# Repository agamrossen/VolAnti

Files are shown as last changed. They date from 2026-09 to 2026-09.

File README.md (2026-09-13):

<div align="center">

<picture>
  <source media="(prefers-color-scheme: dark)" srcset="docs/images/logo-dark.svg">
  VolAnti
</picture>

### Open-source acoustic drone detection. It hears the propellers, not the radio.

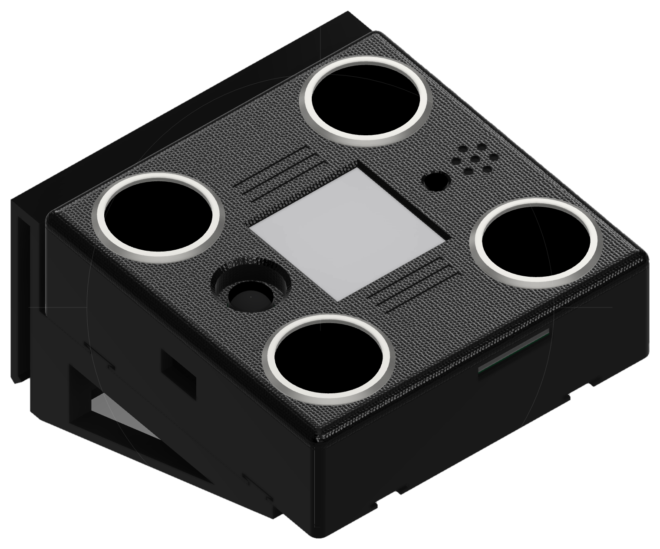
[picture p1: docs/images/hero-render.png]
VolAnti unit on its mount


<br>

**[Website](https://volantitech.com)** · **[Live simulator](https://volantitech.com/#simulator)** · **[Build it on a breadboard](docs/breadboard-build.md)** · **[Build the full unit](docs/pcb-build.md)** · **[Photos and videos](docs/gallery.md)**

Detection and alert only. No jamming, no interception, no countermeasures, ever.

</div>

---

A 91 mm box with four microphones, an ESP32-S3, an e-paper screen and a LoRa radio. It listens for the harmonic comb a multirotor makes and when it hears one it beeps, flashes red, buzzes, writes the time to a screen that survives a power cut, and tells every other unit on the network.

If you want the short illustrated version, or to watch the detector work on a sound field you control, that is what [the website](https://volantitech.com) and [the simulator](https://volantitech.com/#simulator) are for. This page is the long version, and everything needed to build one is in this repository.

<table>
<tr>
<td align="center" width="20%"><h3>104 m</h3>measured detection,<br>hovering airframe, light wind</td>
<td align="center" width="20%"><h3>0.23 s</h3>from first sound<br>to alarm</td>
<td align="center" width="20%"><h3>none</h3>false alarms in<br>field sessions so far</td>
<td align="center" width="20%"><h3>18 to 22 h</h3>on one<br>battery charge</td>
<td align="center" width="20%"><h3>£50 to £80</h3>parts for a<br>full unit</td>
</tr>
</table>

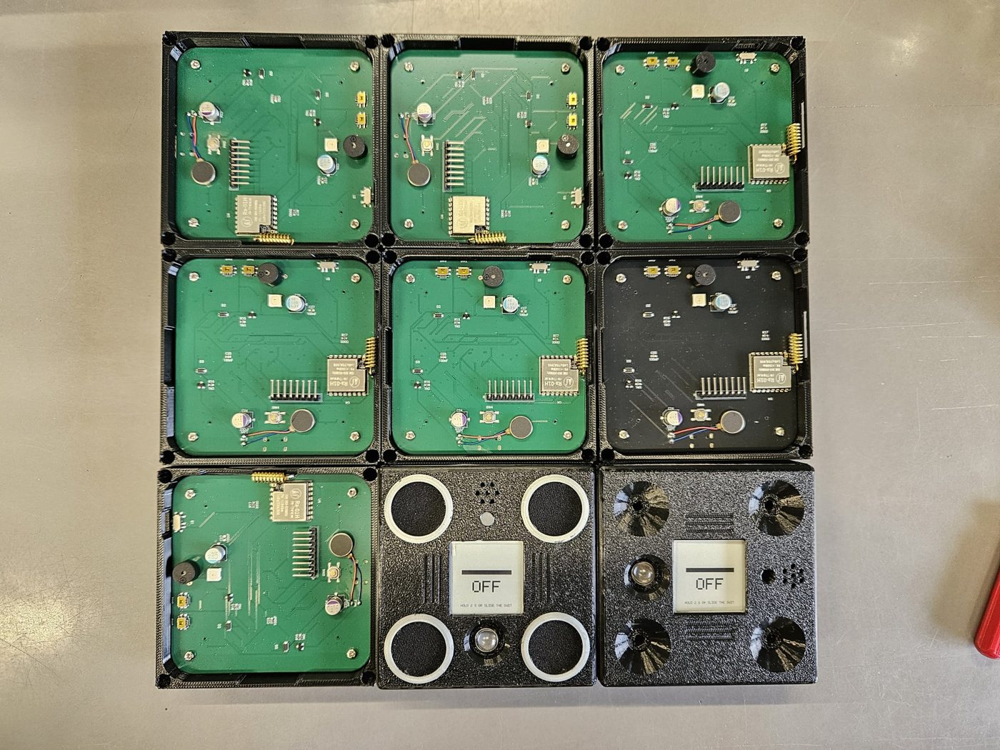
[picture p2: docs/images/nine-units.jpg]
Nine units on the bench, seven open, two closed


## Contents

**Understand it**: [The problem](#the-problem) · [What the device does](#what-the-device-does) · [How it works](#how-it-works) · [Radio](#radio) · [Power](#power) · [Range and testing](#range-and-testing)

**Build it**: [Two ways to build it](#two-ways-to-build-it) · [Breadboard guide](docs/breadboard-build.md) · [Full unit guide](docs/pcb-build.md) · [Flashing](docs/flashing.md) · [Running several units](#running-several-units)

**Everything else**: [Photos and videos](docs/gallery.md) · [Test results](docs/test-results.md) · [Deploying](docs/deploying.md) · [Contributing](#contributing) · [Scope](#scope) · [Licence](#licence) · [A note from Agam](#a-note-from-agam)

**Files**: [firmware](firmware/) · [reference detector](src/) · [PCB, BOM and placement](hardware/pcb/) · [printable enclosure](hardware/enclosure/) · [test audio](test/) · [website source](index.html)

---

## The problem

Nearly all drone detection listens for radio. It finds the control link between the pilot and the aircraft, decodes it, and reports where both are. It works well, and it has one hard failure: the drone has to transmit.

A fibre-optic FPV drone does not. It trails a thread of glass back to its operator, video comes down the fibre, control goes up it, and the radio spectrum stays silent. There is nothing to find and nothing to decode.

What it cannot hide is four motors spinning propellers. A 7 in three-blade propeller on a 2807-class motor puts a precisely structured comb of harmonics into the air, spaced by the blade-passage rate, and that spacing is set by physics the airframe cannot switch off. VolAnti listens for that structure.

It is not radar and not a replacement for one. It is a cheap local tripwire for the last few hundred metres that keeps working when the radio picture is empty, and that a school or a farm can build and repair themselves.

## What the device does

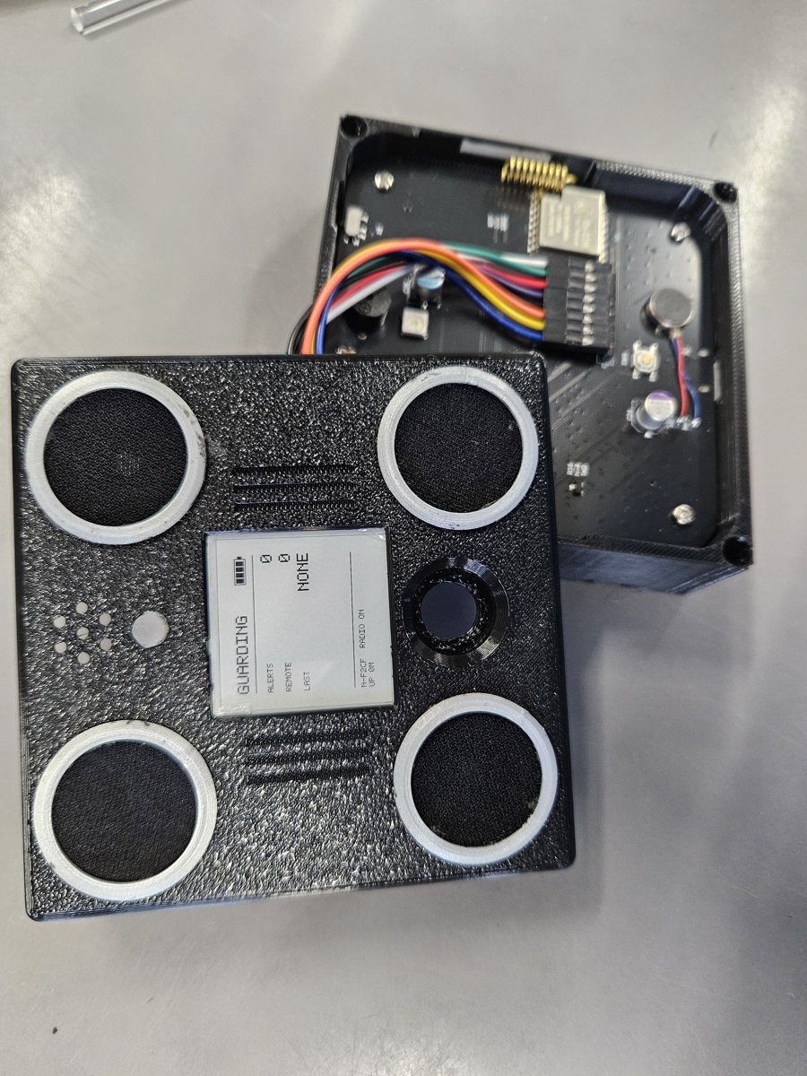
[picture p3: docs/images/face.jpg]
The face of the unit: four grilles, a screen, a light and a button


It runs continuously and does one job. Every 32 ms it takes a new slice of sound from the four microphones, folds them together, measures how comb-like the spectrum is, and asks four independent detectors whether that is a rotor.

When one of them says yes, five things happen at once.

| Channel | What happens |
|---|---|
| Beeper | Loud and patterned. The one that carries through a wall. |
| LED | Fast flashing red through the light pipe in the lid. |
| Motor | A haptic pulse for whoever is holding it. |
| E-paper | The alert and the time, and it stays on the screen with no power. |
| LoRa | An 18 byte packet to every other unit in range. |

Between alerts the light blinks slow green, so a quiet unit and a dead unit never look the same. A press on the snooze button silences the outputs for ten seconds while detection carries on underneath.

<br clear="right">

## How it works

A propeller with B blades turning at R revolutions per second chops the air B×R times a second. That is the fundamental. Because the chopping is not a smooth sine, energy also lands at 2×, 3×, 4× and so on, and the result is a harmonic comb: peaks at even spacing with quiet gaps between.

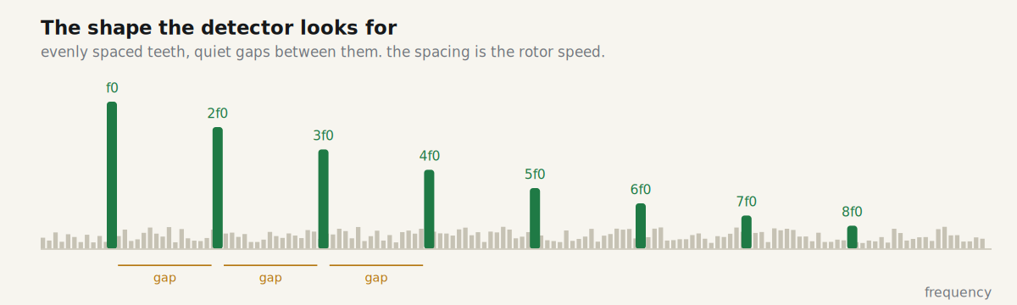
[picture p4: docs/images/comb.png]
Measured spectrum of a loaded propeller, showing the comb


Wind, traffic and rain smear across the whole spectrum. Evenly spaced teeth do not, and their spacing is the rotor speed. So the detector measures a rate and checks that it holds still.

**Four microphones to one number.** Four ICS-43434 MEMS microphones sit in a plus, 79 mm corner to corner, clocked from one source. Their four streams are added. At these frequencies 79 mm is a tenth of a wavelength, so sound from any direction adds in phase and each capsule's own noise does not. That is about 6 dB of signal to noise for free and it is nearly omnidirectional. Beamforming was tried at this size and buys nothing, so the array is a sensitivity device, not a direction finder.

**Spectrum.** A 2048 point FFT every 512 samples at 16 kHz, one frame every 32 ms.

**Adaptive floor.** The detector keeps a running picture of what the site normally sounds like at every frequency and subtracts it. Quiet things are learned in about 6 s, loud broadband bursts in under a second, which is what stops a passing lorry parking itself in the noise model.

**Comb score.** For every candidate rate from 70 to 2000 Hz, add the energy on that comb's teeth, subtract the energy in its gaps, normalise, keep the best.

**Track and hold.** One high scoring frame means nothing. The same rate has to win six frames in a row within 2 %. Noise does not do that. A rotor does.

**Four detectors on one spectrum.** A single detector would have to be tuned for either a drone that arrives or a drone that hovers, so there are four, and the alert is whichever is sure first.

| | Tier | Catches | How | Latency |
|---|---|---|---|---|
| 1 | Fast comb | An aircraft that arrives, approaches or changes | Comb score against the fast floor | 0.23 s |
| 2 | Slow comb | An aircraft that arrives and then hovers | Same score against a 30 s floor | 1.4 to 4 s |
| 3 | Envelope wash | Loaded, close, high thrust flight | Broadband modulation above 3 kHz | 1 to 3 s |
| 4 | No-floor comb | A long hover somewhere that never goes quiet | 2 s Welch spectrum, whitened, no floor | 5 to 15 s |

Tier 1 is sealed: golden test vectors pin its behaviour, and the same audio gives the same score to the last decimal place on a laptop and on the board. Tier 4 is the one that fired at 104 m.

More detail, including the numbers behind each stage, is in [docs/how-it-works.md](docs/how-it-works.md). All of it runs live in [the simulator](https://volantitech.com/#simulator).

## Radio

Each unit carries an Ra-01H LoRa module and a spring antenna lying in the wall of the case. The alert packet is 18 bytes: identity, tier, rate, score, sequence. There is no relay and no mesh. Every unit hears every other unit directly, which is a thing you can test in an afternoon.

The link spreads an alert, it does not vote on one. Every unit decides for itself. Waiting for a second opinion costs seconds and seconds are the whole product.

The frequency has to be set for the country of use: 868 MHz in the UK and EU, 915 MHz in the US, and whatever the local allocation is elsewhere. Details in [docs/deploying.md](docs/deploying.md).

## Power

USB-C in, a BQ24074 charger with power path, a TPS63020 buck-boost holding 3.3 V, and a 1S 2500 mAh LiPo. About 18 to 22 hours on the cell alone.

The cell stays fitted even on a unit that lives on mains. During bring-up the board browned out when the beeper, the motor and the radio fired at the same moment on USB alone. The cell absorbs that spike. A mains unit with no battery is a unit that reboots at the exact moment it matters.

## Range and testing

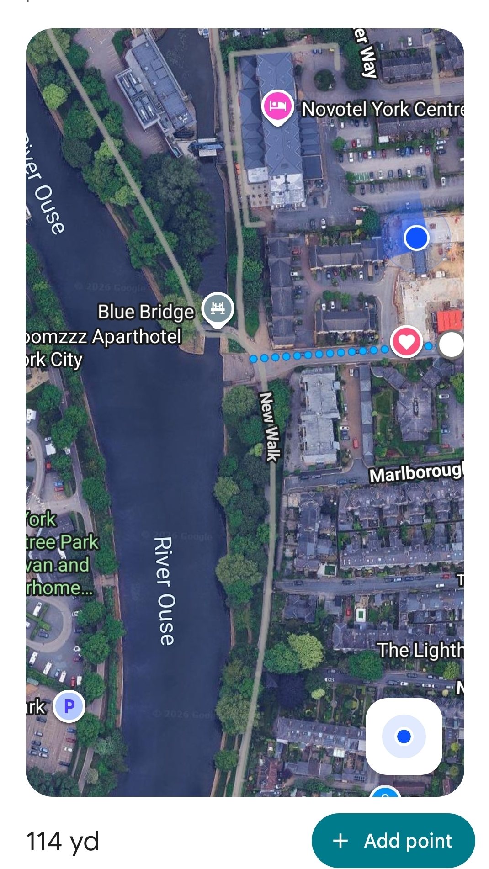
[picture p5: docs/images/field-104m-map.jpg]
114 yards on the map


**6 September 2026, 104 m.** One unit on a brick-walled street with traffic passing, the test rig hovering at the far end. Tier 4 fired at 104.2 m, 114 yards on the map, with people talking near the unit. Nothing fired on the cars. The rig is four 2807-class motors with 7 in three-blade propellers on the same frame as the airframes this was built against, each motor on its own throttle, so it holds a hover wherever the tape says. Video, the map and the test screen are in [test results](docs/test-results.md) and [the gallery](docs/gallery.md).

Since that test the detector has been tuned further, for a lower false-alarm rate and a faster reaction, and those changes are in the current firmware.

**Before it.** 21 August, open ground, changing wind: 14 m with loaded propellers, no false alarms all day. 28 August, first production board: detector output bit-identical to the reference on the golden vectors, worst frame 29.4 ms against the 32 ms budget over 1,938 frames, no overruns.

Range moves by an order of magnitude with wind. Still air and a quiet site should give 100 to 200 m. A breezy or noisy site can give 15 to 50 m. Above 8 m/s assume it is degraded. [docs/deploying.md](docs/deploying.md) has the table.

<br clear="right">

## Two ways to build it

<table>
<tr>
<td width="50%" valign="top">

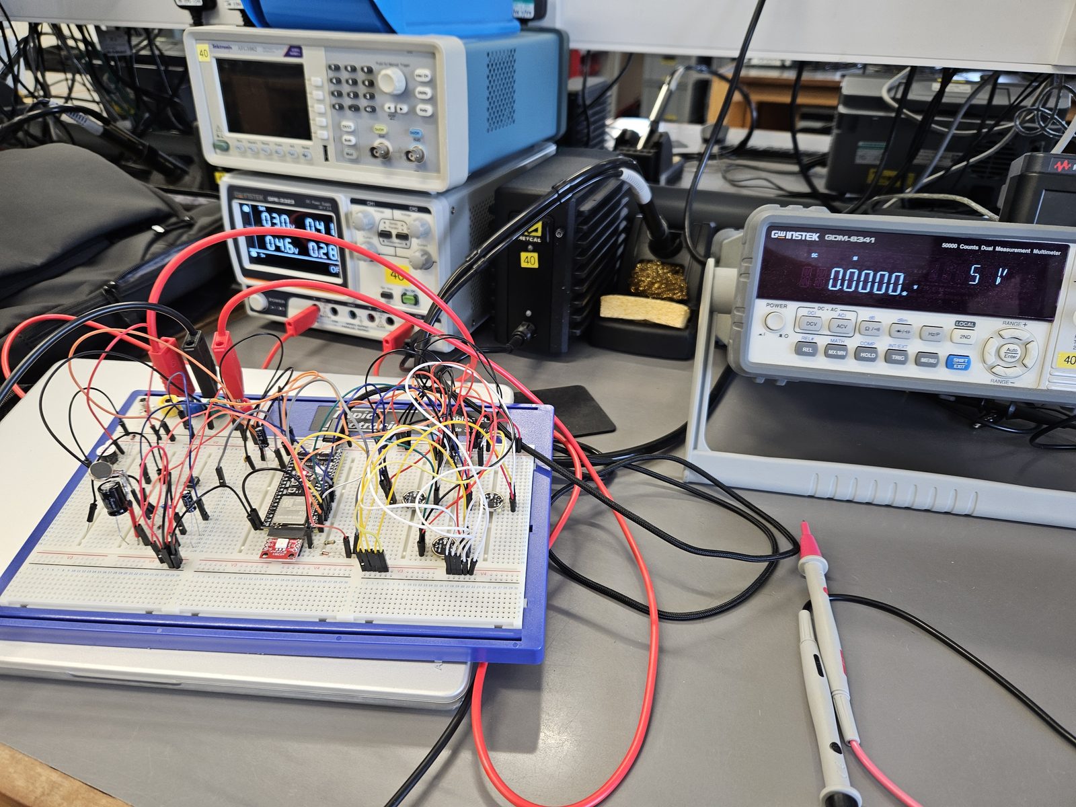
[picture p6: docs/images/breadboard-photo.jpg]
The breadboard build


**On a breadboard.** A dev board and four microphone breakouts. No custom PCB, nothing to solder beyond header pins. Same firmware, same detector, and it will detect a drone. About £35 to £45 and an evening.

**[Breadboard build guide →](docs/breadboard-build.md)**

</td>
<td width="50%" valign="top">

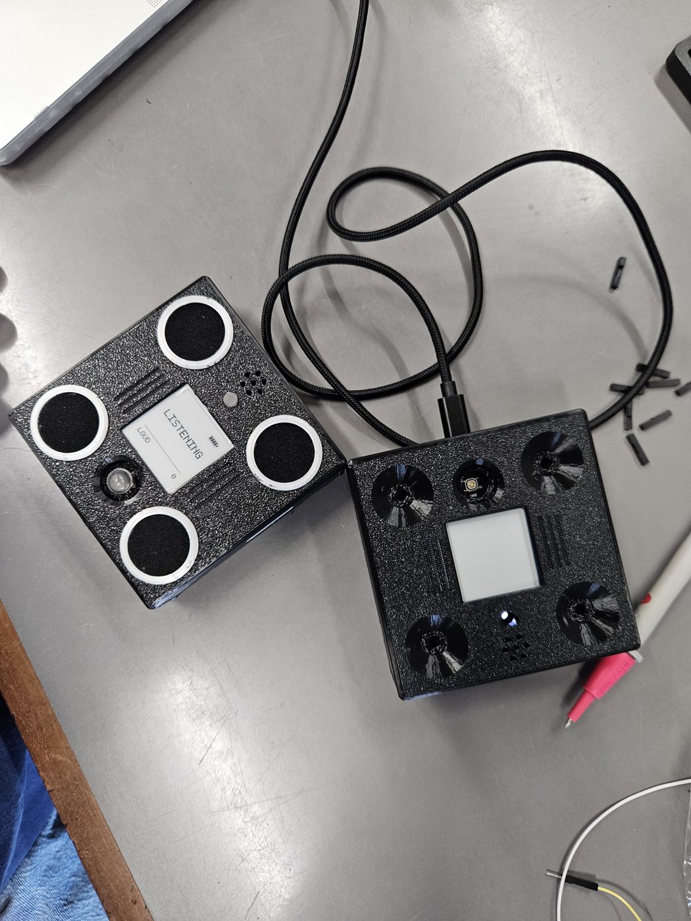
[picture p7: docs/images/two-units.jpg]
Two finished units


**Or the full unit.** Order the four-layer board assembled, print four parts, solder the few joints the fab cannot, screw it together. This is the unit every number on this page came from. About £50 to £80 and a weekend.

**[Full unit build guide →](docs/pcb-build.md)**

</td>
</tr>
</table>

## Running several units

A single unit is complete on its own. Several units cover more ground and move the alarm to where the people are: a unit at the fence hears the aircraft, a unit in the kitchen repeats it.

Every unit runs the full detector and alerts on its own evidence. Listening units go out on the approach sides, spaced so their coverage touches, on solar or battery. Indoor units sit where people are, on mains, and mostly repeat. One assembled and flashed spare on a shelf turns a week's repair into a two minute swap.

Face up, parallel to the ground, in shade, 2 to 4 m high, a few metres clear of steady noise. Do not publish where your units are. Siting, mains wiring, the service schedule and the planning arithmetic are in [docs/deploying.md](docs/deploying.md).

## Contributing

Build reports are the most useful thing you can send, including the ones where it did not work. Open an issue titled `Build report: <rough location, month>` with the build type, firmware version, what made the sound, the distance it was and was not detected at, the wind, and any false alarms. No maps of where your units are.

Pull requests are welcome for anything inside the scope below. Changes to the detection chain need to pass the golden vector tests unchanged, or come with new vectors and a reason.

## Scope

VolAnti detects and alerts. It will never include jamming, spoofing, interception, targeting or any other countermeasure, in this project or in any fork carrying its name. Contributions in that direction are closed without discussion.

## Licence

Hardware under CERN-OHL-W-2.0, firmware under Apache-2.0, documentation under CC BY-SA 4.0. Full texts in [LICENSES/](LICENSES/), the short version and the disclaimer in [LICENSE.md](LICENSE.md). Not a life-safety product. It will miss aircraft.

## A note from Agam

Hello, and thank you for taking an interest in VolAnti. If you have questions about the breadboard build, the hardware or the firmware, open an issue and I will be happy to help.

A few things worth knowing before you build and test one:

- **The software has the most room for improvement.** I wrote the firmware in one month while building the hardware at the same time, and parts of it show that.
- **It was made for outdoors.** Outside it has coped well with wind, traffic, people and generators. Indoors it has raised false alarms a number of times on certain music, propeller recordings and loud fan-like sounds. I believe this comes from the sensitivity of tiers 1 and 4, which triggered indoors the most.
- **By my calculations the hardware is capable of more than the firmware gets out of it**, in how early and how far away it can detect a drone. Most of the tuning used synthetic audio and a small number of real recordings, so recordings of real drones and real background noise, from other places and in other weather, are the most useful thing for improving both range and false alarms.
- **The LED has misbehaved on some flashed units**, sometimes staying lit the whole time the device was on and sometimes flashing red at boot. I believe it is a software fault and have not had time to track it down.

VolAnti does not care about politics, where you are from or what you look like. It exists to protect people's lives and the lives of those around them. That is why it is not sold, why it was never made for or with any military, and why it is open source: the small towns and communities these drones attack are often the ones left unprotected, and anyone who could benefit from one should be able to build it. A few units are being deployed at a civilian site in Israel as a deployment test, as an extra layer of protection for the residents rather than something to rely on alone. Beyond that, I hope people build their own and improve it, especially the firmware, so it can reach people anywhere without waiting on shipping.

If you build one or test it in the field, I would love to see photos of it being made, tested or used. Leave out anything that shows where a unit is deployed. It would genuinely make my day, and it helps my portfolio for academic applications.

---

<div align="center">

Designed and tested by Agam Rossen at the University of York.

</div>

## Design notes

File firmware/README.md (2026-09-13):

# Firmware

ESP32-S3 firmware, built with ESP-IDF v6.0. Setup, build commands for both boards and the three mistakes that cost an evening are in [docs/flashing.md](../docs/flashing.md). [docs/how-it-works.md](../docs/how-it-works.md) describes what the detector does.

    firmware/sentry_node/
      main/              the application: capture, the four detector tiers, alerts, display, radio
        boards/          pin maps for the two targets, the DevKitC breadboard and the PCB
        epaper/          e-paper panel drivers
        generated/       headers written by the build, not kept in git
      scripts/           host tools: header generator, golden vector capture and comparison, parity checks
      PORTING_NOTES.md   how the C port is kept identical to the Python reference

    src/                 the Python reference detector, and the synthetic audio used to test it
    data/                detector constants, operating points and the golden test vectors
    tests/test_golden.py checks the golden vectors against the reference detector
    environment.yml      the Python environment the build and the tools use

## One codebase, two boards

The four-layer board and the DevKitC breadboard build are two build targets of the same source. The target selects the pin map and the hardware the board has, such as the battery monitor and the LoRa radio, and nothing else. The detector is the same code on both, which is what lets a breadboard result mean something for a boxed unit.

## Generated headers

The detector's constants, lookup tables and golden vectors are not written by hand. On every build `scripts/gen_headers.py` writes them into `main/generated/` from `src/` and `data/`, which is why the build needs Python with numpy as well as ESP-IDF.

## Sealed

Tier 1 is pinned by golden test vectors. A given input file must produce the same score to the last decimal place on a laptop and on the board, and on the production board it does, bit for bit. Any change to the detection chain has to pass those unchanged, or bring new vectors and a reason.

On a laptop, `python tests/test_golden.py` checks the vectors against the reference detector. On a board, `scripts/capture_trace.py` records the replay of each vector and `scripts/compare_trace.py` judges it against the reference trace.

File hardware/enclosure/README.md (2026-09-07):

# The enclosure

91 × 91 × 29 mm, four printed parts, no supports anywhere. The lid's four 45 degree cones are the point of the design: they run unbroken from the grille mouth down to the microphone port and print as self-supporting funnels when the lid is face down.

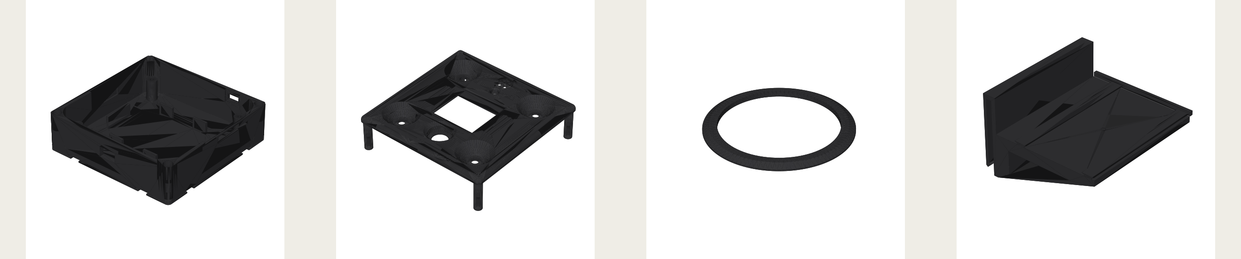
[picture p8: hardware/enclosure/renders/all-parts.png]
Base, lid, grille ring and mount


| Part | STL | STEP | Material | On the bed |
|---|---|---|---|---|
| Base | [VolAnti_Base.stl](stl/VolAnti_Base.stl) | [step](step/VolAnti_Base.step) | PETG | As modelled, cavity up |
| Lid | [VolAnti_Lid.stl](stl/VolAnti_Lid.stl) | [step](step/VolAnti_Lid.step) | PETG | Face down, flat on the bed |
| Grille ring, four per unit | [VolAnti_GrilleRing.stl](stl/VolAnti_GrilleRing.stl) | [step](step/VolAnti_GrilleRing.step) | PLA is fine | Flat side down |
| Mount | [VolAnti_Mount.stl](stl/VolAnti_Mount.stl) | [step](step/VolAnti_Mount.step) | PETG | Wedge, tray with two rails, belt clip on the back |

All STLs are in millimetres and print at 100 %. STEP files are there for anyone changing the design.

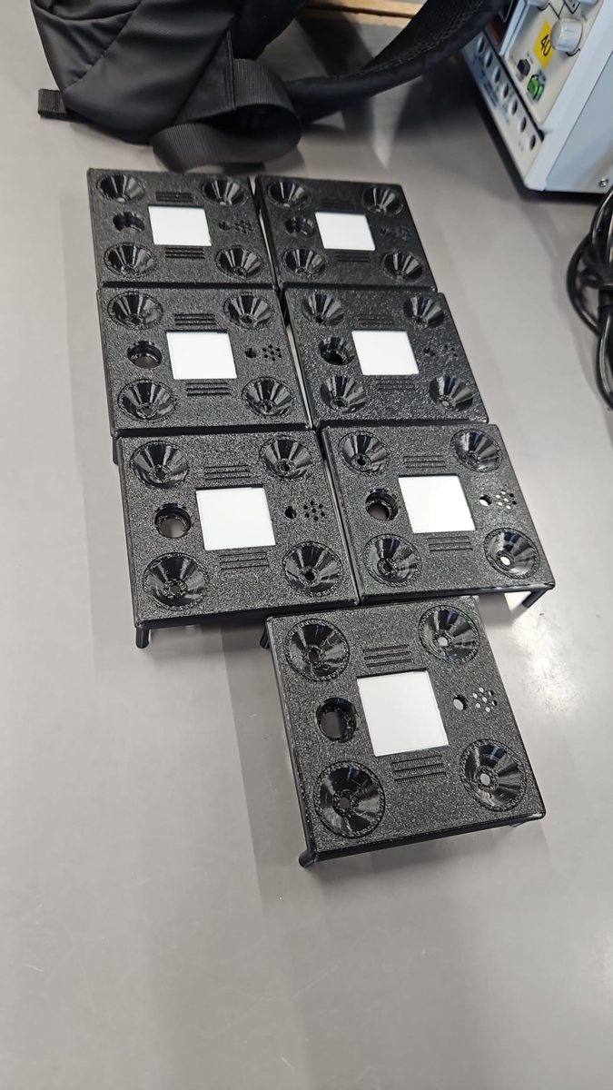
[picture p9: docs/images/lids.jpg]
Seven printed lids


## Print settings

Every unit so far: 0.4 mm nozzle, 3 perimeters, 20 to 25 % infill, 0.2 mm layers, black PETG. Grille rings at 0.1 mm layers so the ramp comes out smooth. Elephant-foot compensation on, several fits are first-layer critical. If your slicer wants supports, the part is the wrong way up.

After printing, check the corner posts drop into the lid bores and the light pipe port takes a 5 mm rod. Ream to 5.1 mm if your printer runs tight.

## For anyone remixing

Three things this design learned the hard way. Weld every hanging feature at least 1 mm into its parent, a face-kissing overlap exports as a floating body. Any feature joined after a cut refills that cut, so recheck every hole downstream of a new join. Printed undersides are flat or ramped, never stepped. The grille ring took three revisions to get a fully flat bottom and has printed cleanly ever since.

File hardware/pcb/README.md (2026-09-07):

# The PCB

84 × 84 mm, four layers, ENIG, designed in Flux. One board carries the whole device: the ESP32-S3-WROOM-1-N16R8, the four microphones at ±28 mm, the LoRa radio, the charger and regulator, and every alert output. The fab assembles everything except four through-hole parts.

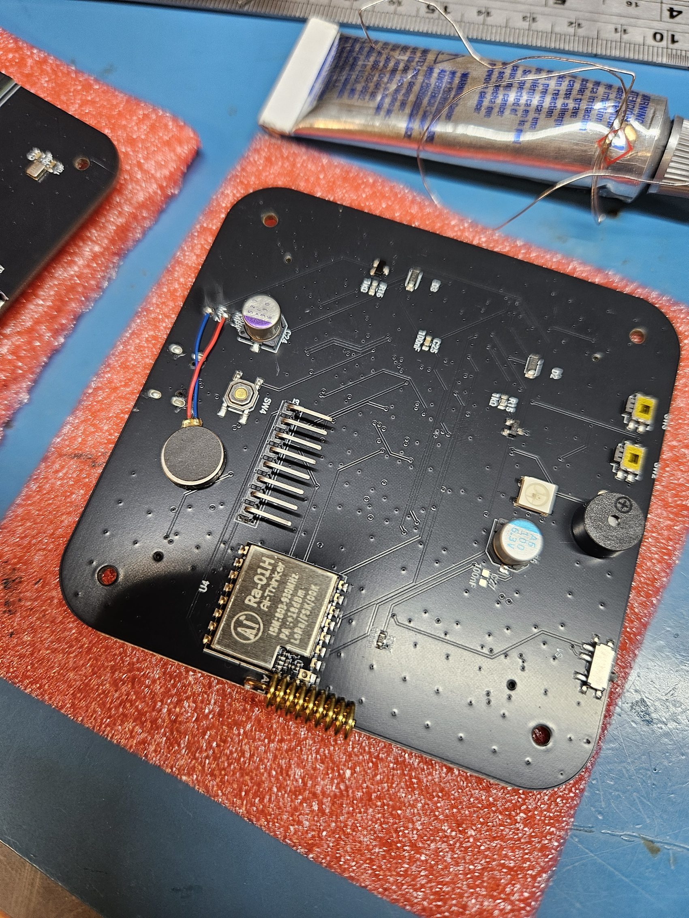
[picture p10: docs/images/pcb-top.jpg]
Rev A2, top side


| File | What it is |
|---|---|
| [gerbers/VolAnti_revA2_gerbers.zip](gerbers/VolAnti_revA2_gerbers.zip) | Gerber and drill set, rev A2, straight from Flux, with per-fab BOMs inside |
| [bom.csv](bom.csv) | Bill of materials, 36 lines, with LCSC part numbers |
| [pick-and-place.csv](pick-and-place.csv) | Placement file for assembly |
| [placement-bottom.jpg](placement-bottom.jpg) | The fab's placement drawing for the underside |
| [Flux project](https://www.flux.ai/agamrossen/sentry-node-v1~wa) | The design itself, schematic and layout |

## Ordering from JLCPCB

1. Upload the gerber zip. Accept the detected 84 × 84 mm four-layer stackup.
2. ENIG finish, 1.6 mm, any mask colour, five is the minimum quantity.
3. Turn on assembly, top and bottom, and upload `bom.csv` and `pick-and-place.csv` when asked.
4. On the part matching screen every line carries its LCSC number. If a passive is out of stock, any same value, size and tolerance substitute is fine. Do not substitute U1 to U4, the four microphones, or the USB and battery connectors.
5. BZ1, J3, ANT1 and the motor pads are excluded from assembly on purpose. You solder those, see [the build guide](../../docs/pcb-build.md).

About two weeks door to door.

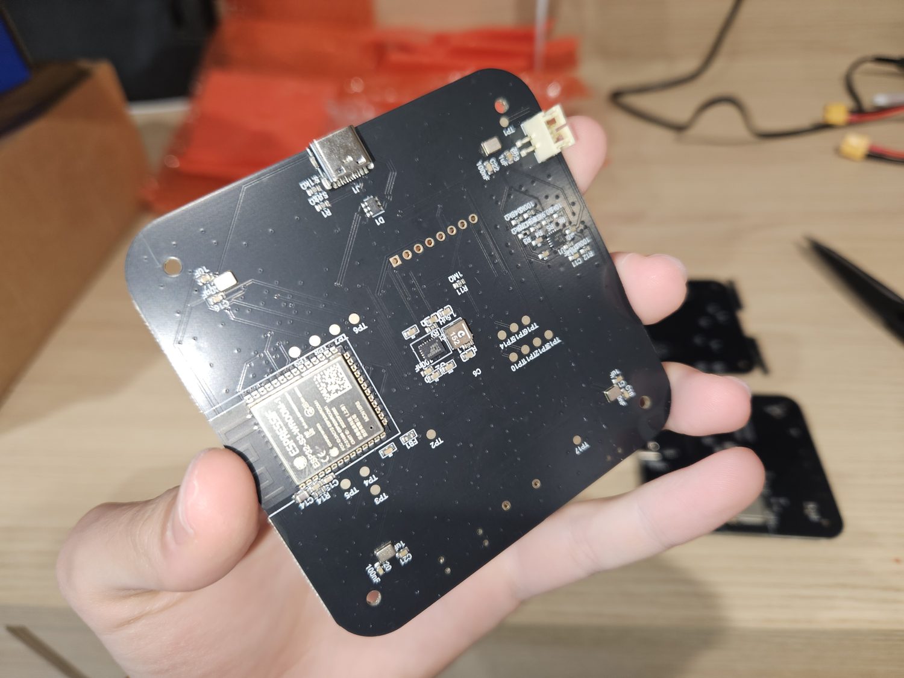
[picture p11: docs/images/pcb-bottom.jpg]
Rev A2, underside


## Design notes

The microphones are bottom-ported parts firing through apertures in the board. Keep fingers and flux off the port holes. The mic positions, the shared I2S clock tree and the per-channel calibration path are exactly what the firmware assumes, which is why a stock board reproduces the golden vectors bit for bit.

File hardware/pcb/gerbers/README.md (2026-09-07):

# Gerbers

`VolAnti_revA2_gerbers.zip` is the fabrication export straight from Flux: all four copper layers, mask, paste and silk for both sides, the board outline, the drill file, the IPC-D-356 netlist, the pick and place file, and a BOM in each of the formats JLCPCB, PCBWay, Eurocircuits, Seeed, Elecrow, AllPCB and Advanced Circuits ask for. Board 84 × 84 mm, four layers, 1.6 mm, ENIG. Upload the zip as it is.

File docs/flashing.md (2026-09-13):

# Flashing

The firmware is in [firmware/sentry_node](../firmware/sentry_node/). Building it needs two things: ESP-IDF v6.0 with the ESP32-S3 toolchain (tested with v6.0.2), and a Python environment with numpy, which the build uses to generate the detector's constants, tables and test vectors from [src/](../src/) and [data/](../data/).

## Setting up

Install ESP-IDF v6.0 by following Espressif's getting started guide, and open a terminal where `idf.py` works. Then create the Python environment from the root of this repository:

    conda env create -f environment.yml

The build finds that environment by its name, `acoustic-detector`. To use a different interpreter instead, point the build at any Python 3 with numpy installed:

    export SENTRY_PYTHON=/path/to/python

## Building and flashing

The breadboard build, on an ESP32-S3-DevKitC-1, is the default target:

    cd firmware/sentry_node
    idf.py build
    idf.py -p PORT erase-flash flash monitor

The full unit, on PCB rev A2, builds into its own directory with its own configuration:

    cd firmware/sentry_node
    idf.py -B build_pcb_a2 -DSDKCONFIG=build_pcb_a2/sdkconfig -DSDKCONFIG_DEFAULTS="sdkconfig.defaults;sdkconfig.pcb_a2" build
    idf.py -B build_pcb_a2 -p PORT erase-flash flash monitor

Keep the two builds in separate directories. The `-DSDKCONFIG` option is what stops the PCB configuration leaking into the breadboard build. The target changes the pin map and the hardware the board has, such as the battery monitor and the LoRa radio, and nothing else. The detector is the same code on both.

Three things that will save you an evening.

1. **Never assume the serial port.** The ESP32-S3's native USB re-enumerates on every reset and the name differs between bootloader and application. List ports from the terminal each time, and if `idf.py` picks the wrong one give it `-p`.
2. **Erase before the first flash of a new unit.** The image expects clean settings storage. Leftovers from an interrupted flash produce confusing boots. Later flashes of the same unit can leave out `erase-flash`.
3. **Use a data cable.** Charge-only USB-C cables are the most common reason a board does not show up, ahead of every real fault seen so far.

The unit boots to LISTENING in about two seconds and needs nothing else. The serial console stays available. Send `I` for the pin map and the board the image was built for, and watch the frame line for the score, the best rate and the tier states.

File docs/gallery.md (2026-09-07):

# Photos and videos

Everything from the build, in order, then the field session videos, then the rest of the archive. Full-size originals are on request.

## The build, in order

**Parts on the desk**  
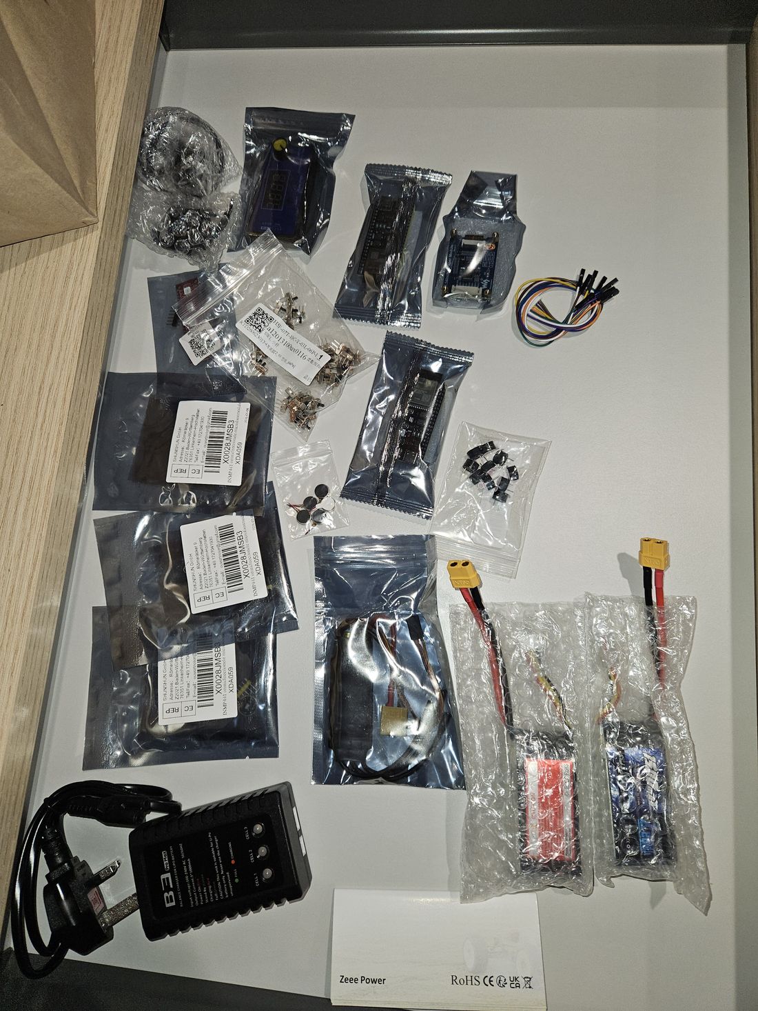
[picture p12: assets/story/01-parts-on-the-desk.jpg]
Parts on the desk


**First power up**  
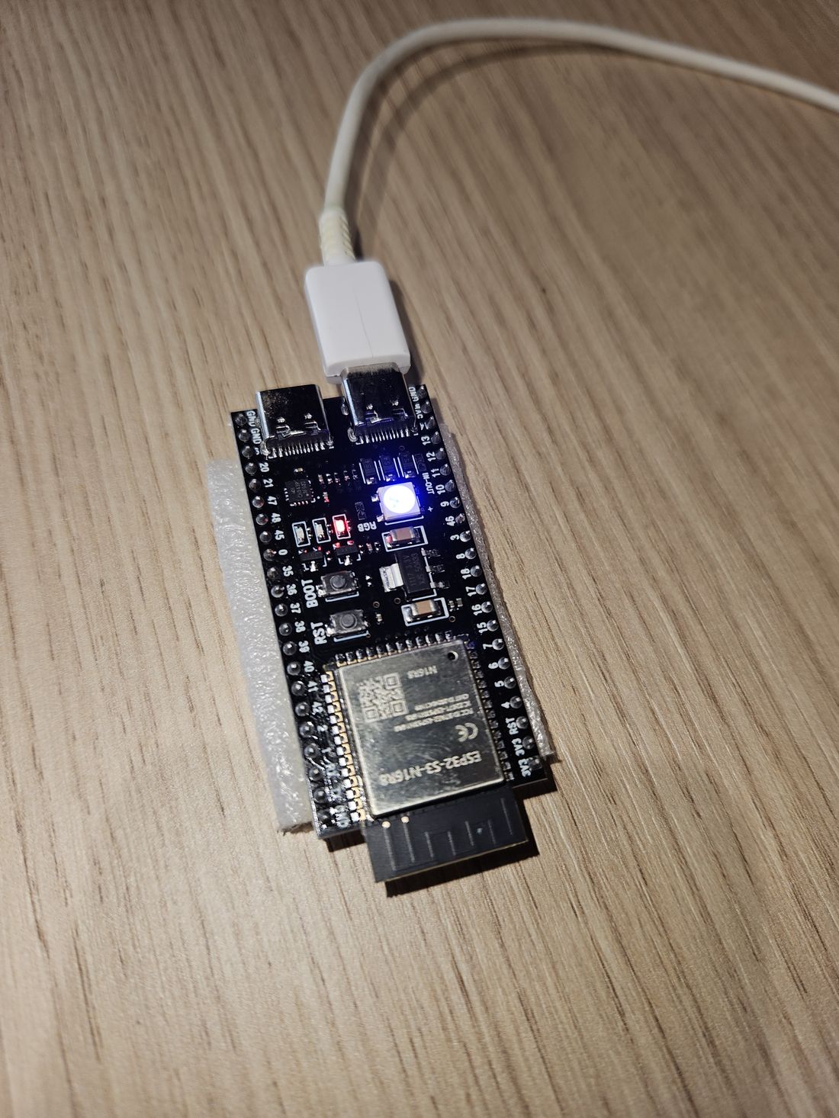
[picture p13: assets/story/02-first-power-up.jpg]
First power up


**First microphones on a breadboard**  
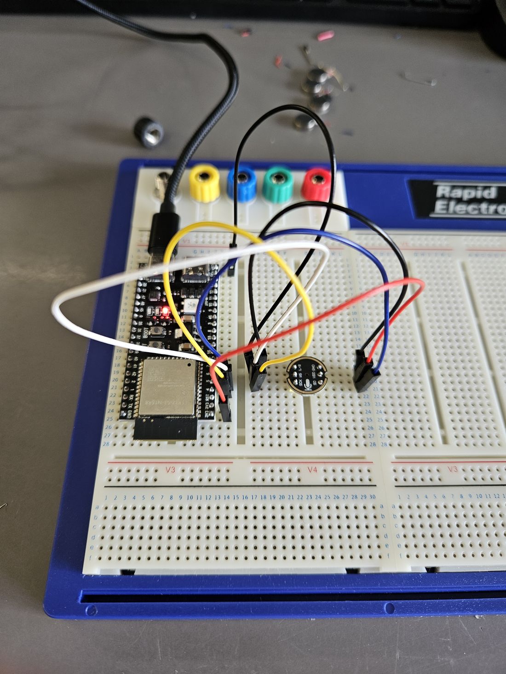
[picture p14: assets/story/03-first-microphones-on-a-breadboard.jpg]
First microphones on a breadboard


**The breadboard grows**  
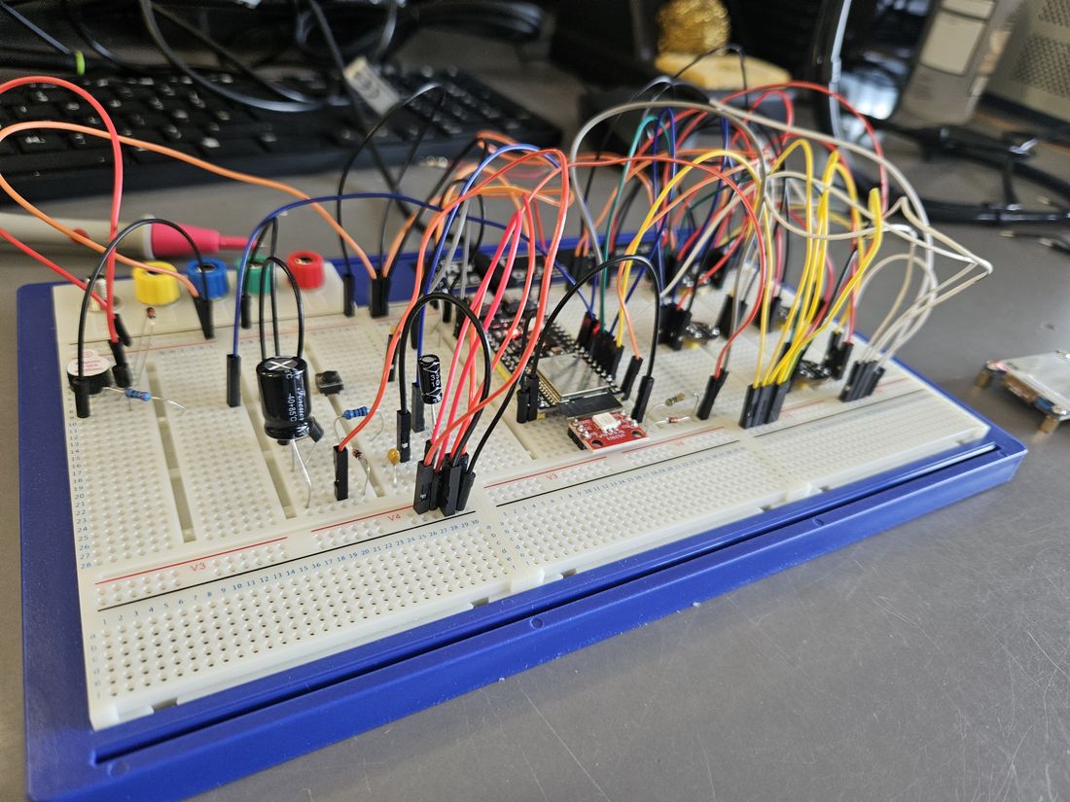
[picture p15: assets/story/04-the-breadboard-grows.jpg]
The breadboard grows


**On the bench**  
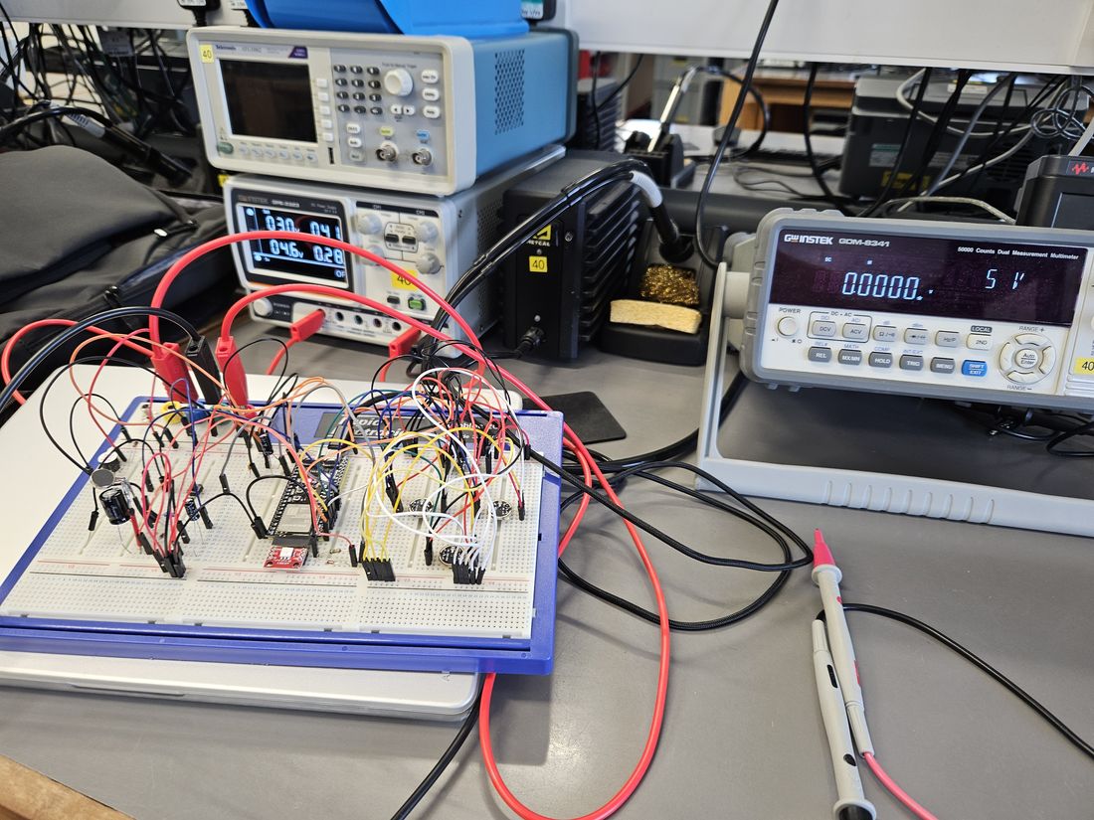
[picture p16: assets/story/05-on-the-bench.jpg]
On the bench


**First real rotor**  
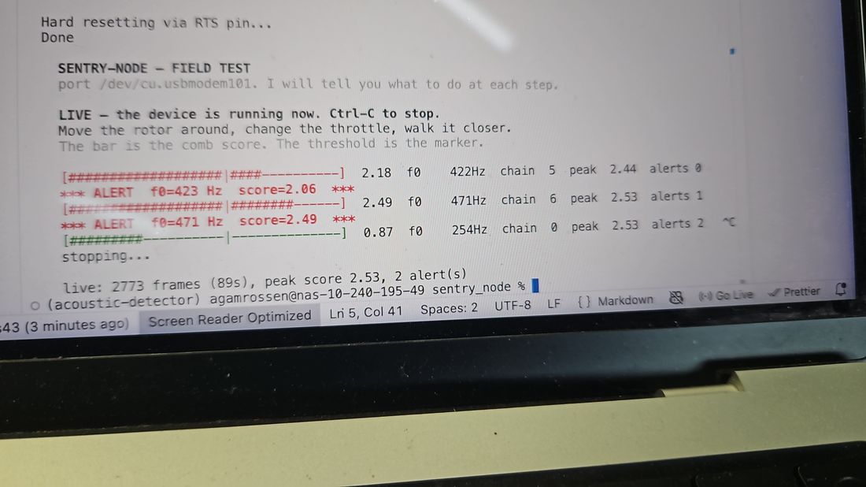
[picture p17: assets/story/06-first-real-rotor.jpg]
First real rotor


**Designing the pcb**  
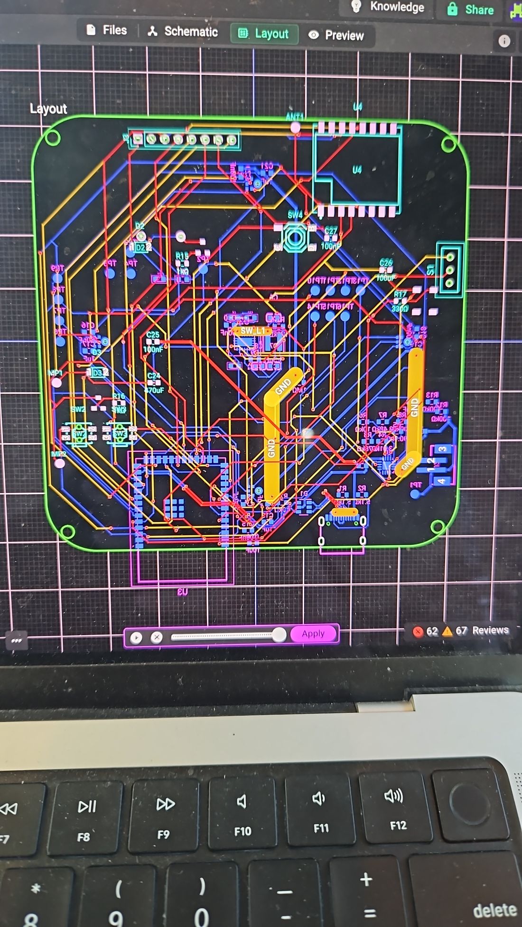
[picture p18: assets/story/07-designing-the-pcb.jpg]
Designing the pcb


**The board rendered**  
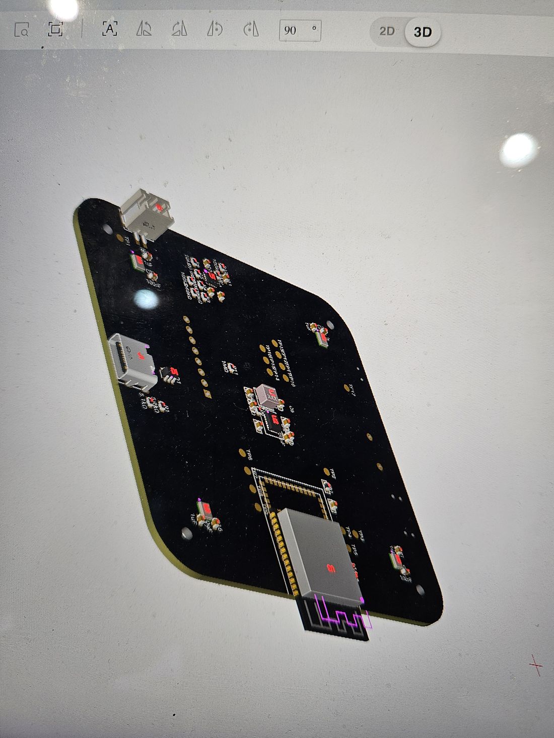
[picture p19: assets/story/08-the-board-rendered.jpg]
The board rendered


**Designing the case**  
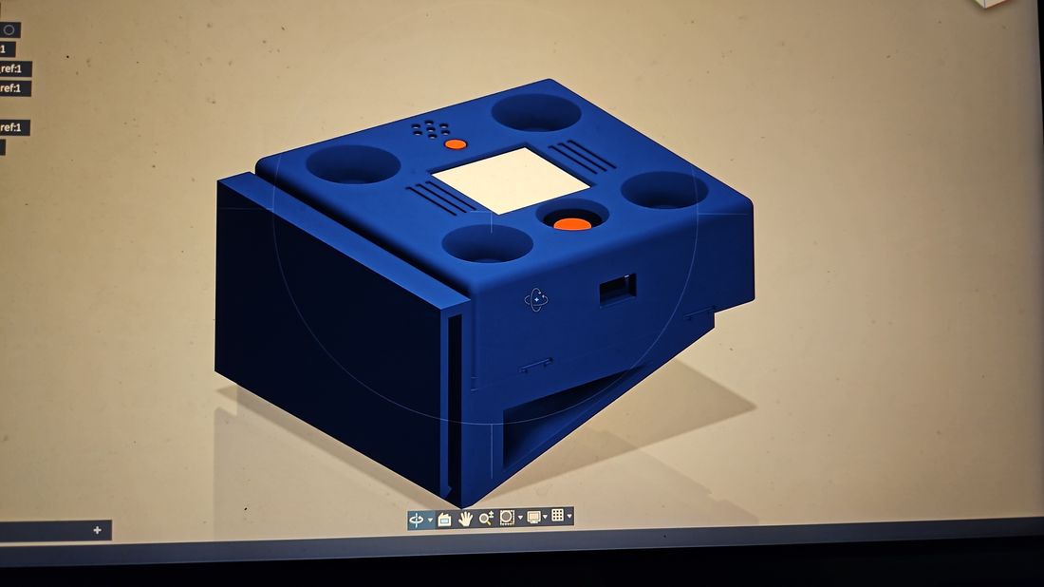
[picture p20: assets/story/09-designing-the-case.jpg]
Designing the case


**Building the drone rig**  
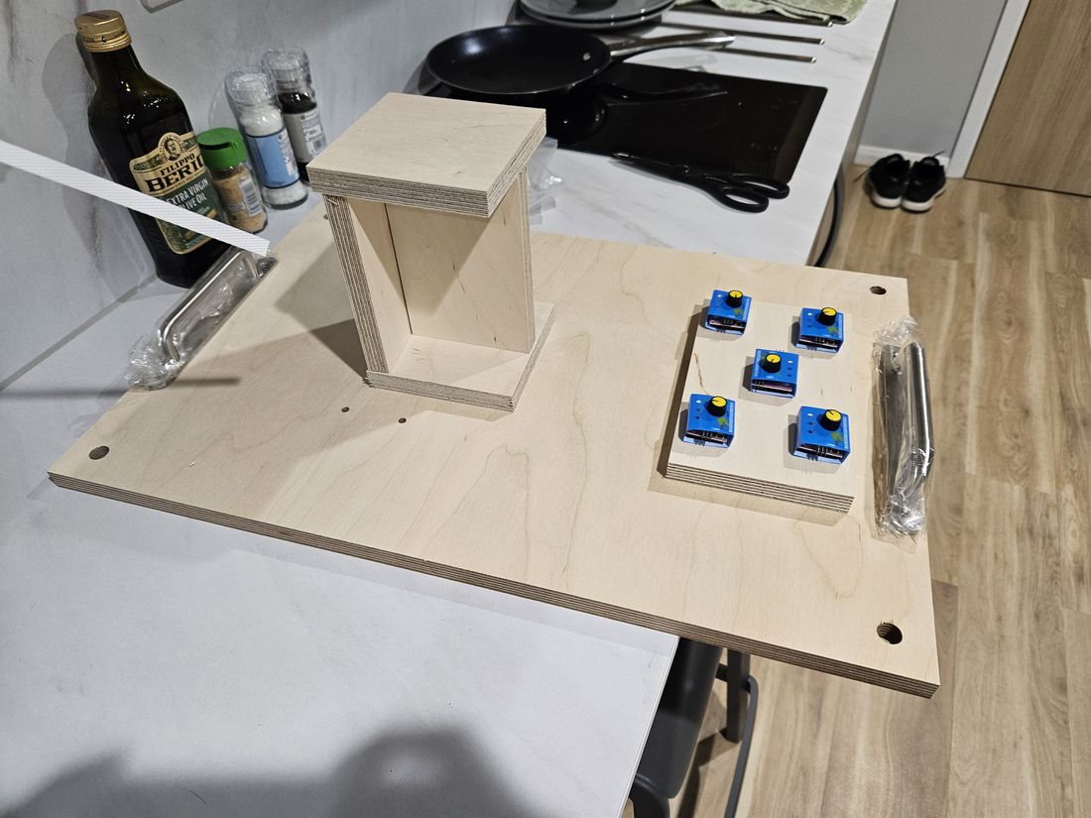
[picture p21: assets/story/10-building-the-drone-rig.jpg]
Building the drone rig


**The drone rig takes shape**  
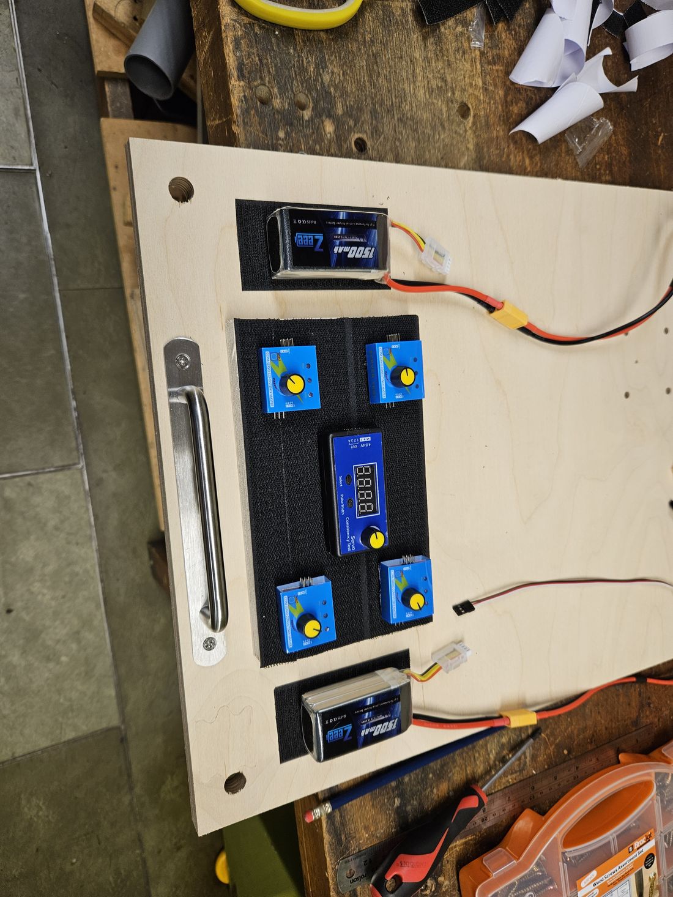
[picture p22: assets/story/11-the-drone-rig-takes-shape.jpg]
The drone rig takes shape


**The drone rig**  
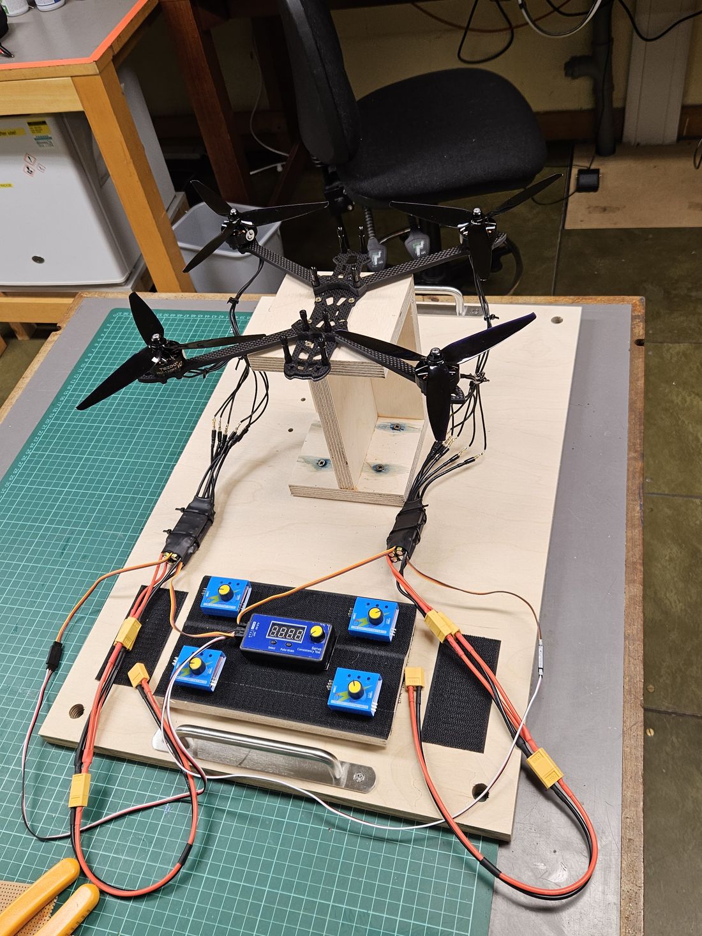
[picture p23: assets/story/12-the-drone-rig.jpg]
The drone rig


**First outdoor field test**  
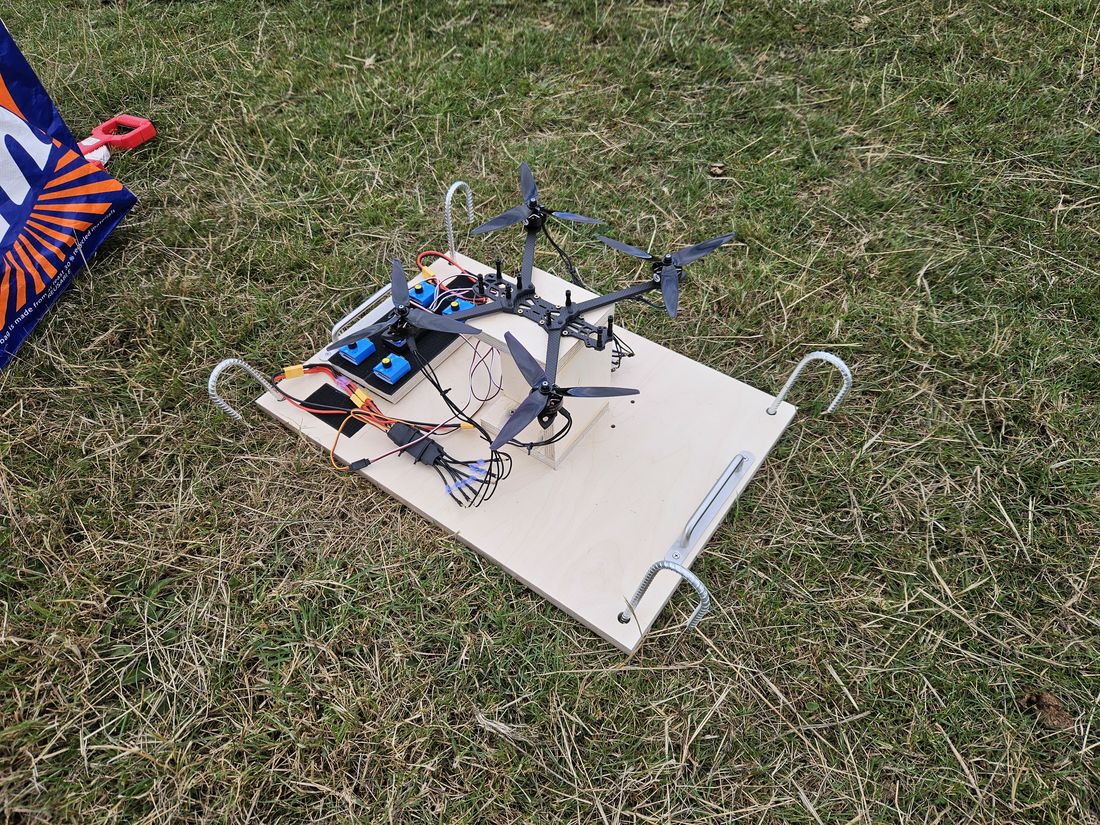
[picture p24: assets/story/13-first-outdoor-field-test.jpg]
First outdoor field test


**All the enclosure parts arrive**  
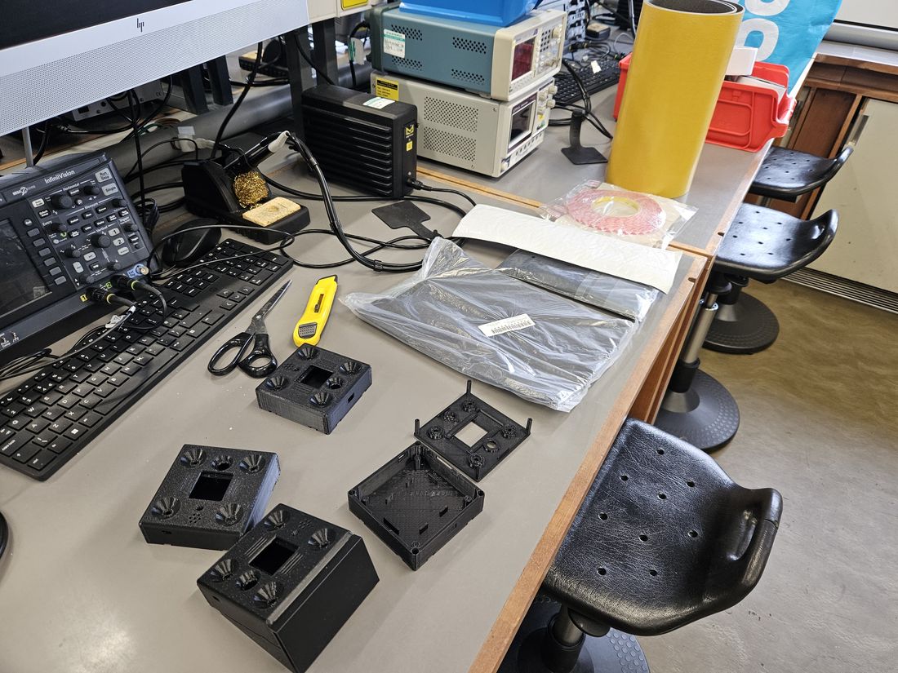
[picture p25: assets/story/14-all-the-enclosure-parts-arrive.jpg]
All the enclosure parts arrive


**Installing grill cloth**  
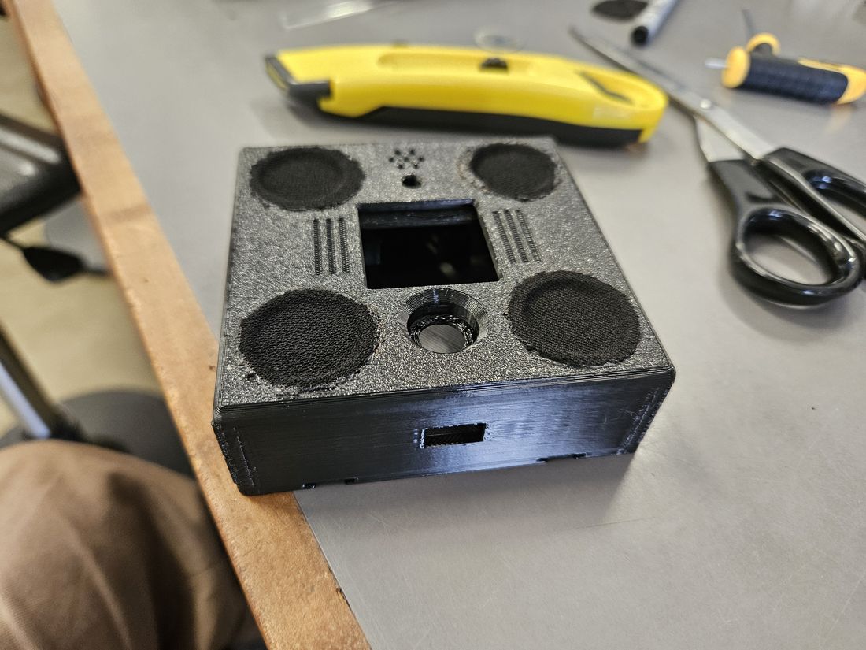
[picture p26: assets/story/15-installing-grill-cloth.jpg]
Installing grill cloth


**First batch of boards arrive**  
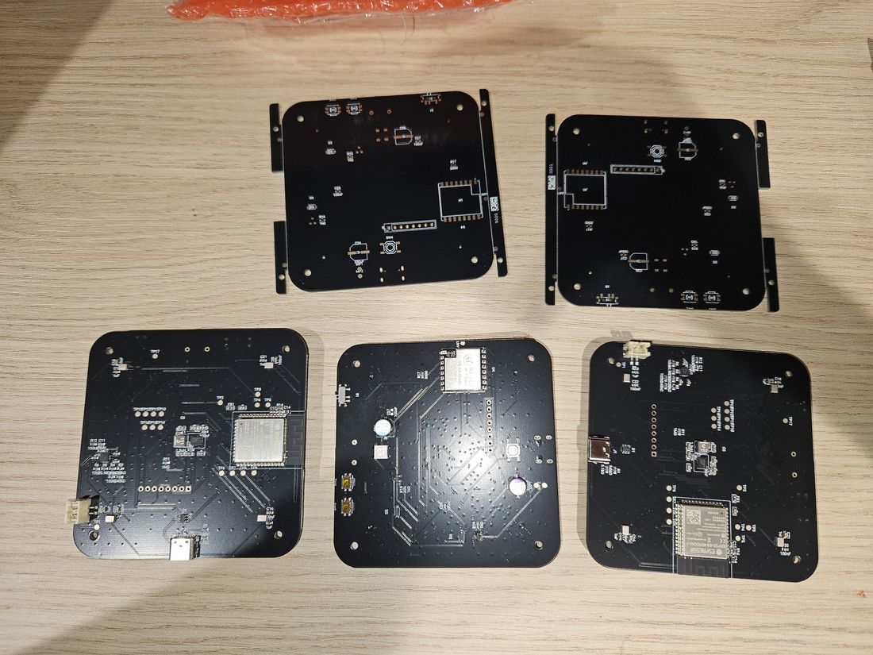
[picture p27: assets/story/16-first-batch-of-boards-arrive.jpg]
First batch of boards arrive


**Remaining enclosure parts arrive**  
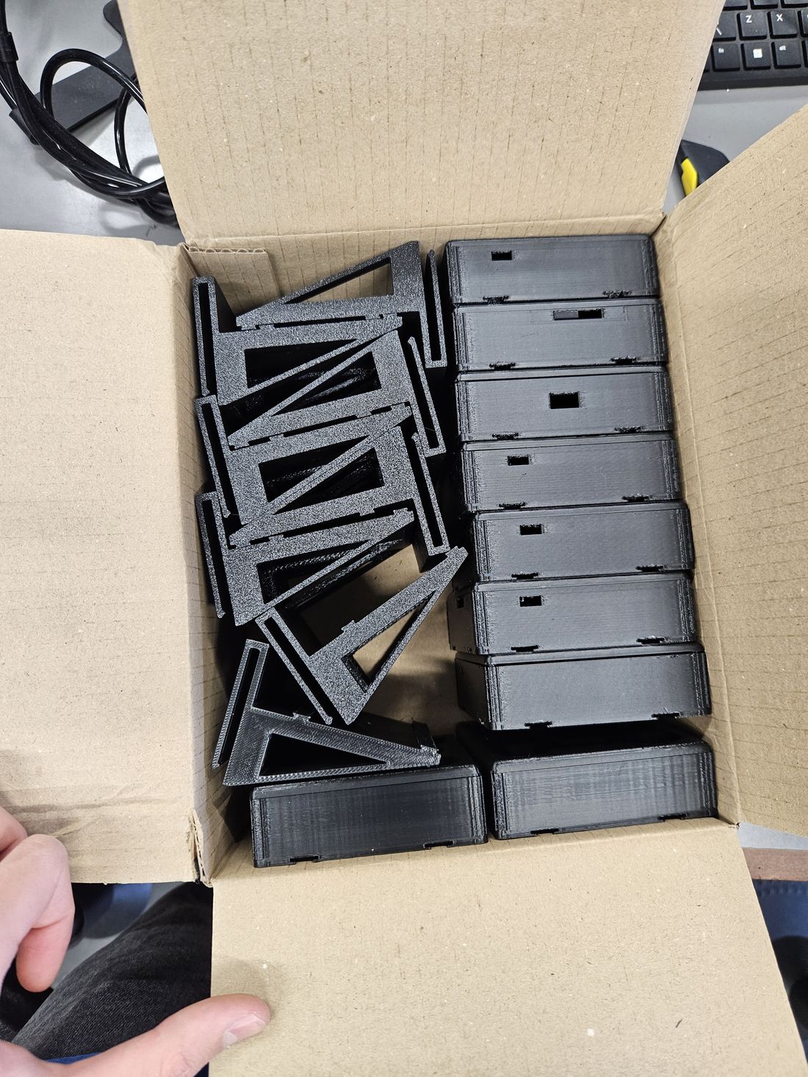
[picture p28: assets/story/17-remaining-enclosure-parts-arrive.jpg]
Remaining enclosure parts arrive


**Parts to go on the board**  
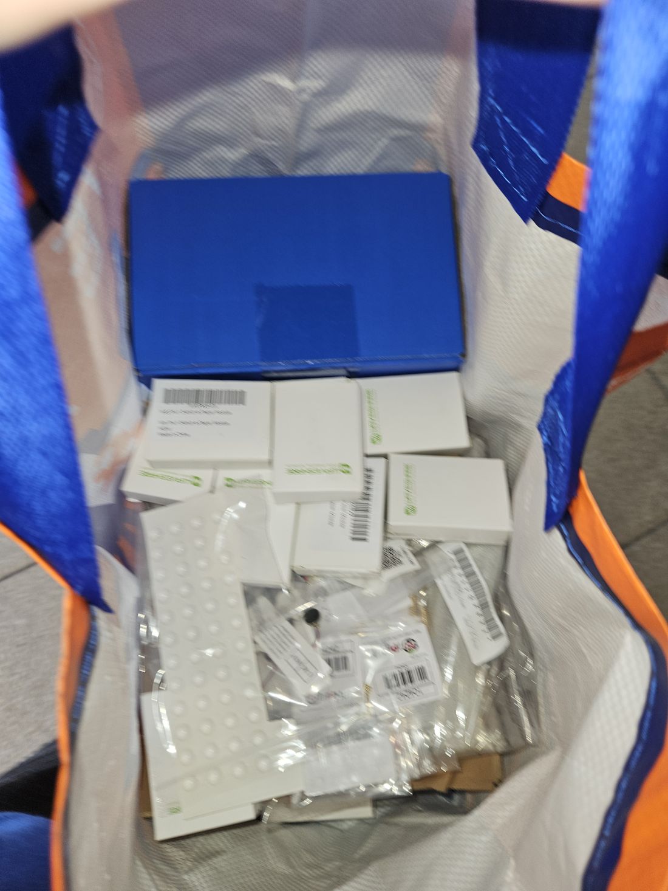
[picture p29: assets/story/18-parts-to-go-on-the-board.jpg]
Parts to go on the board


**Soldering of extra parts on the pcb**  
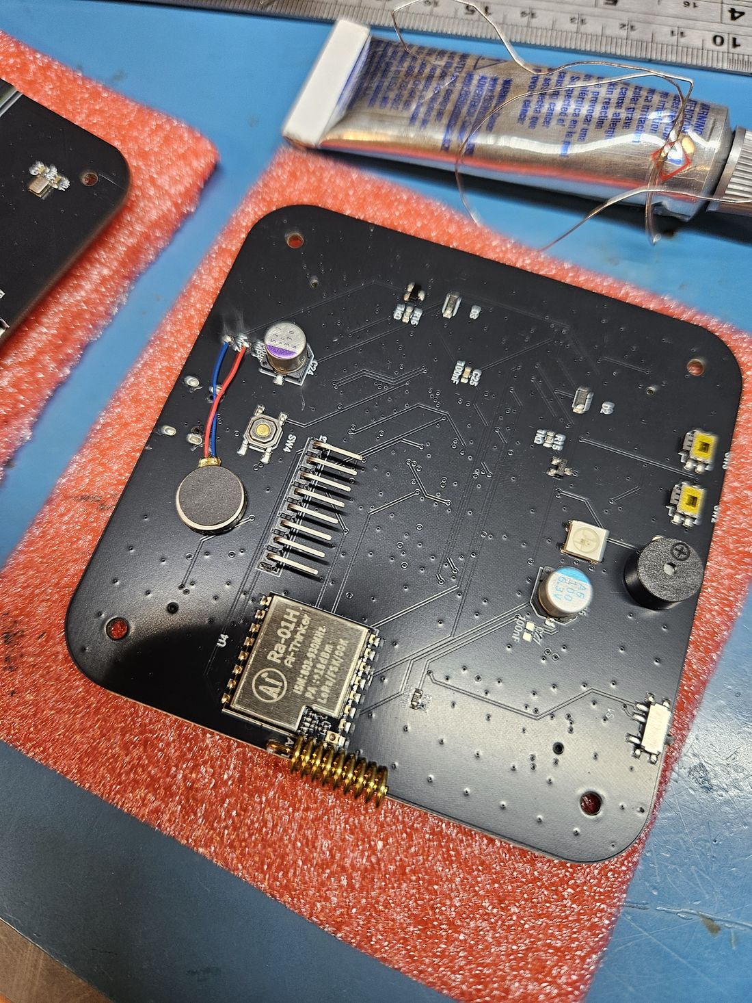
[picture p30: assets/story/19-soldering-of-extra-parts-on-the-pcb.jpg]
Soldering of extra parts on the pcb


**In the lab**  
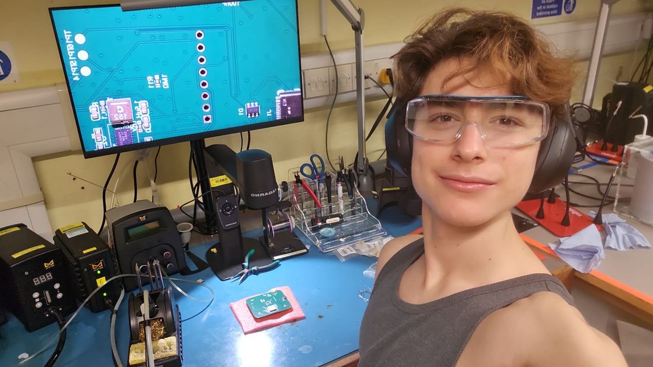
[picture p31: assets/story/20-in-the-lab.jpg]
In the lab


**Printing accessory parts**  
Printing accessory parts

**Bring up**  
Bring up

**Board in the base display and lid**  
Board in the base display and lid

**Battery foam pad in**  
Battery foam pad in

**Fitting the battery**  
Fitting the battery

**Unit assembly**  
Unit assembly

**The face**  
The face

**In the hand**  
In the hand

**More units**  
More units

**More than one finished unit**  
More than one finished unit

## Field test videos

6 September 2026, the 104 m street session. Click a frame to open the clip.

**The 104 m detection, sped up. The unit in the hand, the rig at the far end of the street.**  
[The 104 m detection, sped up. The unit in the hand, the rig at the far end of the street.](media/field/20260906_104m-test-sped-up.mp4)

**The same run at normal speed.**  
[The same run at normal speed.](media/field/20260906_104m-test-full.mp4)

**Setting up. Walking the rig out along the wall, 18:59.**  
[Setting up. Walking the rig out along the wall, 18:59.](media/field/20260906_185923.mp4)

**The unit on the pavement, 19:10.**  
[The unit on the pavement, 19:10.](media/field/20260906_191004.mp4)

**19:12.**  
[19:12.](media/field/20260906_191256.mp4)

**19:14.**  
[19:14.](media/field/20260906_191406.mp4)

## The rig and the 21 August session

The rig staked on open ground

The four-motor rig from above

The 50 m tape laid along the path

The unit showing its test screen, rig behind

Two units at two ranges

## Everything else

Every photo taken during the build, by date.

 
 
 
 
 
 
 
 
 
 
 
 
 
 
 
 
 
 
 
 
 
 
 
 
 
 
 
 
 
 
 
 
 
 
 
 
 
 
 
 
 
 
 
 
 
 
 
 
 
 
 
 
 
 
 
 
 
 
 
 
 
 
 
 
 
 
 
 
 
 
 
 
 
 
 
 
 
 
 
 
 
 
 
 
 


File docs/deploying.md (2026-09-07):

# Deploying

## What to expect for range

Range moves by an order of magnitude with wind, so a figure without its wind speed is meaningless. These are for a full 7 to 9 in multirotor under load, unit face up in the open with grille cloth fitted.

| Conditions | Wind | Expect detection at |
|---|---|---|
| Still air, quiet rural site | under 2 m/s, leaves still | 100 to 200 m |
| Light breeze, ordinary background | 2 to 5 m/s, leaves moving | 50 to 120 m |
| Moderate wind, or a noisy site | 5 to 8 m/s, branches moving | 15 to 50 m |
| Strong wind | over 8 m/s | tens of metres at best |

The 104 m measurement was made in light wind on a noisy street, so it sits where the second row says it should. Warning time is detection distance divided by closing speed. At 27 m/s, 120 m is about 4.5 s and 50 m is under 2 s.

A steady distant hover takes longer to alarm than an approach. Loud steady noise near the unit shortens range without causing false alarms. Your own drone triggers it. Close conversation can trigger the comb tiers, which is rare in an outdoor mounting position and known.

## Several units

Every unit runs the full detector and alerts on its own evidence. There is no voting. The radio spreads an alert, it does not confirm one.

| Role | Where | Power |
|---|---|---|
| Listening units | Across the approach sides, spaced so coverage touches | Solar or battery |
| Indoor units | Where people are, mostly repeating the alert | Mains |
| Cold spare | On a shelf, assembled and flashed | |

Warning time = (detection distance + standoff) ÷ threat speed. A unit that reliably hears an aircraft at 100 m, sited 300 m out, gives about 15 seconds against something moving at 27 m/s.

## Siting

Face up, parallel to the ground. The array is omnidirectional at drone rates, so the only orientation that matters is the unit's own body shadowing the sky. In shade: sun cooks the cell and ages the e-paper. Two to four metres up, above head height and below rooflines. A few metres clear of air conditioning, generators and transformers. They will not false-alarm it, but they raise the floor and cost range.

Do not publish where your units are.

## Radio region

The LoRa frequency has no universal default. Set it for your country before transmitting, and set every unit at a site the same.

| Region | Band |
|---|---|
| UK and EU | 868 MHz |
| Israel | 917 to 920 MHz, verify the current allocation |
| US | 915 MHz |

The Ra-01H covers all of them. Link settings are SF9, BW125, CR4/5.

## Mains units

The USB input is the charger and the battery stays fitted. It is the buffer that keeps the rail up when beeper, motor and radio fire together. Use a locally certified 5 V supply, a braided USB-A to USB-C cable no longer than 2 m at 22 AWG, a drip loop under the port with self-amalgamating tape over the connector, and an RCD on the circuit.

## Service

| When | What |
|---|---|
| Weekly | Green blink present, screen sane, note the alert count |
| 3 months | Open one mains unit and look at the cell for swelling |
| 6 months | Replace cells. Check the silica sachets. A saturated one means that unit's seal has failed. |
| After any alert | Pull the event log and keep it. Real events are the rarest data this project has. |

## Drills

Decide in advance what an alert means, who moves where, who checks and who stands down, and walk it once with the beeper going. Seconds of warning only help people who already know what to do with them.

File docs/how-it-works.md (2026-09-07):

# How it works

The device measures how strongly the sound spectrum looks like an evenly spaced comb of harmonics, and refuses to alert until that pattern has held still long enough not to be an accident. This page is the numbers behind that sentence. Every stage below runs live in [the simulator](https://volantitech.com/#simulator).

## The signal

A propeller with B blades at R revolutions per second chops the air B×R times a second. That is the fundamental, f0. The chopping is not a sine, so energy lands at 2×, 3×, 4× and so on: a harmonic comb.

Measured spectrum of a loaded 7 in three-blade propeller

For a three-blade propeller the detector tracks two comb families, at the 2× and 3× spacing, so a detection survives one family being masked. The predicted hover band for the airframe this was built against was 375 to 475 Hz. The first real-rotor locks landed at 423 and 471 Hz. Loaded flight sits higher, 480 to 570 Hz, which is what a propeller doing work should do.

## Capture

| Stage | Setting |
|---|---|
| Microphones | 4 × ICS-43434, digital MEMS, one shared I2S clock |
| Array | Plus pattern, 79 mm corner to corner, ±28 mm on each axis |
| Sample rate | 16 kHz per channel |
| Combination | The four channels are summed |
| FFT | 2048 points, every 512 samples, so one frame every 32 ms |
| Bin width | 7.8 Hz |

At the frequencies that matter, 79 mm is about a tenth of a wavelength, so the array is effectively a point. Sound from any direction adds in phase, uncorrelated capsule noise does not, and the sum gains about 6 dB of signal to noise while staying nearly omnidirectional. Measured grazing loss across the comb band was between −0.02 and +0.03 dB.

That measurement closed a design question. Beamforming was tried and dropped. At 79 mm the ratio of aperture to wavelength at 450 Hz is about 0.10, and steering does nothing until around 2 kHz. The sum already is the beam. The array buys sensitivity, not direction.

## Floor

The detector keeps a running estimate of the site's normal spectrum in every bin and subtracts it. Quiet changes are learned with a 6 s time constant, so a new tone stands out for seconds. Loud broadband bursts, wind gusts, a lorry, are learned in 0.8 s, so they cannot park themselves in the model. The whitened value is capped at 2.5 so nothing can dominate.

The floor has a known weakness. A drone that arrives and hovers is learned into the fast floor after about 6 s and disappears from tier 1. Tiers 2 and 4 exist because of that.

## Score

For every candidate f0 from 70 to 2000 Hz in 1 Hz steps, 1931 candidates a frame:

    score = (energy on the comb teeth − energy in the gaps) / √K

with K the number of teeth in band. A high score means the spectrum is combed at that spacing, not just loud. The best candidate has to win six frames in a row within 2 % before anything is allowed to happen.

## Four detectors

| Tier | Floor | Band | Decision | Threshold | Latency |
|---|---|---|---|---|---|
| 1 Fast comb | 6 s rise, 0.8 s fall | 70 to 2000 Hz, alerts 200 to 810 Hz | 6 frame chain, family continuity across 1, 2, 3, ½, ⅓ | 1.70 | 0.23 s |
| 2 Slow comb | 30 s | 200 to 800 Hz | 44 of 63 frames | 1.40 | 1.4 s and up |
| 3 Envelope wash | none, whitened across frequency | modulation rate 100 to 650 Hz on the envelope above 3 kHz | 16 of 23 | 20 | 1 to 3 s |
| 4 No-floor comb | none, 64 frame Welch median, whitened across frequency | f0 110 to 700 Hz | 5 of 8 updates | 30.5 | 5 to 15 s |

Tier 1 catches arrivals and changes. Tier 2 catches an arrival that then hovers, because its floor has not caught up. Tier 3 catches loaded, close, high thrust flight, where the giveaway is a roar modulated above 3 kHz rather than a clean comb. Tier 4 catches a long hover in a place that never goes quiet, because nothing is ever learned into a floor. It is the most sensitive and the slowest, and it is the one that fired at 104 m.

The alert is the first tier to be sure. Outputs hold for 5 s with a countdown on the screen, and the slow accumulators freeze while the outputs are active so the unit's own beeper cannot feed the detector.

## Why the thresholds are low

For this use a missed aircraft costs far more than a false beep. So the thresholds sit low and the false alarm defence is the trackers: a real, stable, physically plausible rotor rate that persists. That rejects noise better than a high threshold does, because a high threshold also rejects quiet real drones.

## Sealed

Tier 1 is pinned by golden test vectors. A given input file must produce the same score to the last decimal place on a laptop and on the board, and on the production PCB it does, bit for bit. No future change can move it silently.

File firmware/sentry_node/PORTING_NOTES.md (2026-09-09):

# PORTING_NOTES.md — every place the C could have diverged from the Python

Companion to `main/detector.c`. `src/detector.py` is normative; this file
records each site where a faithful port required a decision, what was decided,
and why. Nothing here is a tolerance and nothing here is a tuning knob.

Result of the port: **all four golden vectors PASS** — zero decision-field
mismatches, zero chain divergence, at 61% of the frame budget.

(The two `f0_bin` differences that appear since the float32 whitening landed
are both frame 0, pre-warmup, at score ~5e-7: on frame 0 the floor is
initialised to the magnitude, so `S = ln2` in every bin and teeth-minus-gaps is
exactly zero for all ~1881 candidates. The argmax is a coin flip among exact
ties and can never reach a decision field.)

---

## 0. The reference is NOT uniformly float32

This is the single most important thing to understand before reading the C.
`src/detector.py` looks like a float32 pipeline and is not one. Reading the
code rather than the comments:

| site | Python dtype | why |
|---|---|---|
| `np.fft.rfft(block * window)` | **float64** (complex128) | numpy's FFT always promotes to double, whatever the input dtype |
| `st.floor` | **float64** from frame 0 onward | `np.where(up, a_up, a_fall)` builds a float64 array from two numpy float64 scalars, so `a*prev + (1-a)*mag` promotes |
| `r`, `m1`, `m2`, `flat` | **float64** (frame 0: float32) | consequence of the above |
| `log1p(mag/(floor+1e-9))` | **float64**, cast to float32 after `minimum` | consequence of the above |
| `S`, `tv`, `gv`, `tw`, `gw`, `znorm`, `scores` | **float32** | genuinely, by construction |
| tracker arithmetic (`f0`, `t`, thresholds, jitter) | **float64** | Python floats |

So "float32 throughout" would itself have been a divergence. The port matches
the dtype **at each site**: `double` for the floor/whitening/tracker path,
`float` for the spectrum gather and the comb score.

Two places now differ from the reference dtype, both deliberately:

* the **FFT**, which esp-dsp only provides in float32 — irreducible, and
  budgeted before a line of C was written (§1);
* the **whitening `log1p`**, which is float32 by choice
  because float64 cost 21.8 ms of a 32 ms frame and the port could not run in
  real time with it (§4). Measured, not argued: ≤1 ulp of float32 on `S`,
  ~150x below the measured decision tolerance, and re-proved against all four
  golden vectors with zero decision mismatches.

---

## 1. FFT — precision, scaling, ordering

### 1a. Precision: measured, not assumed

Before choosing esp-dsp's float32 FFT over a soft-float64 one (~2 M cycles per
frame), the question "how much FFT error can the golden set actually absorb?"
was answered by measurement, not by a rule of thumb.

`scratchpad/sensitivity.py` imports the unmodified reference detector, wraps
`front_end` to inject error into the spectrum, re-runs all three vectors and
counts decision-field mismatches against the shipped traces (3 seeds per
point). Two models: per-bin relative, and norm-scaled (`spec += eps*rms*n`),
the latter being what a float32 radix-2 FFT actually does — its roundoff is
proportional to the norm of the transform, so small bins take a large
*relative* hit.

```
model 'abs' (norm-scaled)
  eps=1e-8 .. 1e-5   0 decision-field mismatches on all three vectors
  eps=1e-4           12 mismatches + VERDICT FLIP on golden_marginal_pos
```

A float32 radix-2 FFT of length 2048 has norm-scaled roundoff of about
`eps_f32 * sqrt(log2 N)` ≈ 2e-7 — roughly **50x inside** the measured
tolerance. esp-dsp float32 was therefore chosen on evidence.

The tightest decision margins in the reference, for context:

| vector | frame | role | \|score − 2.14\| |
|---|---|---|---|
| golden_marginal_pos | 169 | takes chain 5 → 6, i.e. FIRES | 4.65e-4 |
| golden_marginal_pos | 74 | — | 1.78e-4 |

Both reproduced exactly (device 2.1404647827148438 vs reference 2.140465).

### 1b. Scaling

None. `dsps_fft2r_fc32` and `np.fft.rfft` are both the **unnormalised** DFT —
there is no 1/N on either side. Confirmed on-device with the `F` self-test
command: `x[n] = cos(2π·64n/2048)`, no window, gives `|X[64]| = 1024.0002`
(exactly N/2 as required) and ~1e-3 in every other bin.

### 1c. Ordering — the real difference

esp-dsp does the packed-real trick: the N real samples are consumed as N/2
**complex** values.

```c
dsps_fft2r_fc32 (buf, N/2);   /* N/2-point complex FFT   */
dsps_bit_rev2r_fc32(buf, N/2);   /* natural order           */
dsps_cplx2real_fc32(buf, N/2);   /* unpack to a real spectrum */
```

The result is bins 0..N/2−1 in place, **with the real-valued Nyquist bin
packed into the imaginary slot of bin 0** (`dsps_cplx2real_fc32_ansi_` does
`result[0].im = X[0].re − X[0].im`, which is X[N/2]). numpy's `rfft` instead
returns N/2+1 separate bins.

`front_end()` unpacks to the numpy layout, so nothing downstream ever learns
the difference:

```
spec[0]      = { buf[0], 0 }        DC, real
spec[k]      = { buf[2k], buf[2k+1] }   k = 1 .. 1023
spec[1024]   = { buf[1], 0 }        Nyquist, real, un-packed from bin 0's im
```

Bin 1024 is not decoration: `mag.sum()` (the tonality energy gate) and
`r.mean()` (the flatness moments) run over all 1025 bins, so dropping it
would move the floor gate.

`dsps_cplx2real_fc32` reads the **radix-4** twiddle table, so
`dsps_fft4r_init_fc32()` is required even though no radix-4 FFT is ever
called. Its `wind_step = table_size / N` needs `dsps_fft4r_w_table_size` to be
`2 * max_fft_size`, which is why both inits take `N_FFT >> 1`.

### 1d. Sign convention — deliberately not reconciled

numpy uses `exp(-2πi kn/N)`. Whether esp-dsp matches or conjugates is
irrelevant here: only `|X|` is ever consumed, and conjugation leaves the
magnitude unchanged. Do not "fix" this if beamforming later needs phase —
**check the convention then**, because the combiner is where phase first
matters.

### 1e. 16-byte alignment is REQUIRED, not preferred — this one bit

`dsps_fft2r_fc32` resolves on ESP32-S3 (with `CONFIG_DSP_OPTIMIZED`) to
`dsps_fft2r_fc32_aes3`, the SIMD assembly variant, whose 128-bit loads need
the data buffer 16-byte aligned. `__attribute__((aligned(16)))` on a struct
member does **not** reach the allocator, and `heap_caps_calloc` only promises
4.

The first run of the port produced a magnitude spectrum that was flat at ~330
across every bin and nearly identical from frame to frame — the FFT silently
returning nonsense rather than faulting. The allocation is now
`heap_caps_aligned_calloc(16, ...)` and `I` reports the alignment it actually
got. If a future refactor moves `detector_work_t`, keep the aligned
allocation.

---

## 2. numpy's summation order, reproduced exactly

`np.sum` / `np.mean` over a contiguous axis are **not** left-to-right. numpy
uses an 8-accumulator unrolled block up to `PW_BLOCKSIZE = 128` and recurses
above it:

```
n < 8      naive left-to-right
n <= 128   r[0..7] = a[0..7]; r[k] += a[i+k] in steps of 8 while i < n-(n%8);
           res = ((r0+r1)+(r2+r3)) + ((r4+r5)+(r6+r7)); then += the remainder
n > 128    n2 = (n/2) rounded DOWN to a multiple of 8; recurse on both halves
```

Left-to-right accumulation over the 1025-bin spectrum differs from numpy in
the 6th significant figure — the same order as the 1.78e-4 margin at
`golden_marginal_pos` frame 74. So the order is reproduced, in
`pw_sum_f32` / `pw_sum_f64`.

Validated bit-for-bit against numpy 2.4.6 on the host before any C was written
(`scratchpad/pairwise_check.py`): **0 mismatches** over 1800 random arrays at
n = 7 / 12 / 137 / 1025 / 2048 in both float32 and float64, plus `axis=1` rows
of 12 and `mean`.

Sites that depend on it:

| Python | n | dtype |
|---|---|---|
| `mag.sum()` — tonality energy gate | 1025 | float32 |
| `r.mean()`, `(r*r).mean()` — flatness | 1025 | float64 |
| `(tv*tw).sum(axis=1)`, `(gv*gw).sum(axis=1)` | 12 | float32 |

The 12-element case is not a special case worth skipping: it evaluates as
`((a0+a1)+(a2+a3))+((a4+a5)+(a6+a7))` followed by `+a8 +a9 +a10 +a11` in
order, which is *not* the same float32 result as a plain loop.

---

## 3. Compiler flags that are load-bearing

`main/CMakeLists.txt` compiles this component with:

```
-ffp-contract=off -fno-fast-math -fno-unsafe-math-optimizations
-fno-associative-math
```

`-ffp-contract=off` is the critical one. Xtensa has `MADD.S`, and without it
GCC is free to contract `S[i0]*(1-fr) + S[i0+1]*fr` into a single fused
operation with one rounding instead of two. That silently changes the comb
score in the last bits, on every one of 46,344 interpolations per frame. The
others forbid reassociation, which would defeat §2.

---

## 4. The floor, step by step

`_update_floor`, "tonality" branch, in the order the Python actually executes:

```
prev   = floor                     the OLD array (Python rebinds, C reads
                                   before writing, per bin)
e      = float(mag.sum())          float32 pairwise sum, then widened
rising = e > gate_ratio * e_slow   BEFORE e_slow is updated
r      = mag / (prev + 1e-9)
flat   = mean(r)^2 / (mean(r*r) + 1e-12)
fast   = rising and flat > flat_hi
e_slow = a_energy*e_slow + (1-a_energy)*e
a_up   = a_rise_fast if fast else a_rise
a      = where(mag > prev, a_up, a_fall)
floor  = a*prev + (1-a)*mag
S      = min(log1p(mag / (floor + 1e-9)), sat_log)     <-- the NEW floor
```

Two traps:

* **S whitens against the floor AFTER this frame's update, while the tonality
  gate looks at the one BEFORE.** Getting these the same way round is the
  difference between passing and a slow drift that only shows up 200 frames
  later.
* `rising` uses `e_slow` from the *previous* frame. On frame 0 `e_slow = e`,
  so `rising = e > 1.35e` is false for any `e >= 0` and the fast path can
  never fire on frame 0. The C relies on this rather than special-casing.

**Frame-0 dtype quirk, deliberately not reproduced.** On frame 0 only, Python's
`prev` is still float32 (`mag.copy()`), so `r` and the flatness moments are
computed in float32; from frame 1 they are float64. The C computes them in
double on every frame. This is safe *because* `fast` is false on frame 0
regardless of `flat` (see above) and `flat` is not a trace field, so the
quirk cannot reach any observable. Recorded here so nobody "fixes" it into a
real divergence.

**Smoothing coefficients** (`a_rise`, `a_fall`, `a_rise_fast`, `a_energy`) are
`exp(-hop/fs/tau)` evaluated **on the host in float64** by
`scripts/gen_headers.py` and frozen into `detector_config.h` as 17-digit
literals. The device never calls `exp()`, so it never depends on its libm
agreeing with numpy's.

---

## 5. Sample conversion

`x = q / 32767.0f` — 32767, not 32768, matching `make_golden.py`'s
`np.clip(np.round(x*32767), -32768, 32767)` and the inverse
`q.astype(np.float32) / 32767.0`. That division is a **float32** operation
under NumPy 2's NEP 50 weak-scalar promotion (float32 array ÷ Python float
stays float32), so the C does it in float32 too.

---

## 6. Gather tables — exported, not recomputed

`t_i0`, `t_fr`, `g_i0`, `g_fr`, `tw`, `gw`, `znorm`, `n_tooth` are exported
from an **instantiated `CombDetector`** by `scripts/gen_headers.py`, not
rederived in C. Recomputing them would introduce a second implementation of
`np.arange`, `np.clip`, integer truncation and the `1/sqrt(k)` normalisation —
four more chances to diverge, for no benefit. `znorm` in particular involves
two more float32 sums that would otherwise have to reproduce §2.

Float literals use `%.9g` (float32) and `%.17g` (float64), which IEEE-754
guarantees round-trip exactly.

`tooth_ok` is not exported as a mask: `tooth_f = k*f0` is monotone in `k`, so
the mask is always a **prefix**, and a single count per `f0` reproduces it
exactly. The generator asserts this rather than assuming it, and also asserts
`valid == (n_tooth >= n_harm_min)`.

### Indexed, not quantised

The float tables cost 460 KB of flash traffic **per frame**, and the comb score
was bandwidth bound on them. They are now stored as one byte per entry, an
index into the table's own distinct float32 values:

| table | distinct values | why that number |
|---|---|---|
| `tw`, `gw` | 76 | the normalised 1/sqrt(k) weights depend ONLY on how many harmonics fall below `f_max_harm`, and that count takes 10 values across the whole grid — not 1931 |
| `t_fr`, `g_fr` | 125 | `bin_w = fs/n_fft = 16000/2048 = 125/16`, so every position `f/bin_w` is an exact multiple of 1/125 and its fractional part can only be one of 125 values |

This is **not quantisation**. The LUT holds the original float32 values, so the
dequantised array is bit-identical — the generator asserts that on the raw
uint32 bit patterns and refuses to emit otherwise. Device traces are
byte-for-byte the same as with the float tables.

Scalar quantisation was measured on the host first and is the wrong answer:
uint8 broke the gate outright (13 decision mismatches and a verdict flip),
uint16 survived but is **bigger** than the exact scheme and 100x less accurate.

460.1 KB -> 188.6 KB, comb score 19.5 -> 10.9 ms/frame. `SENTRY_TABLES_LUT=0`
rebuilds with the float tables for an A/B.

Total flash `.rodata` is now 1,835,540 B against 11,854 B of `.data` — the
tables and all four vectors are in flash, not DRAM.

---

## 7. Tracker

Direct transcription of `TrackerState.step`. Points worth naming:

* `track_miss = 2`: a rejected frame does `count = max(0, count - 2)`, and the
  chain/`last_f0` reset happens **only when the counter reaches exactly 0** —
  including when the tracker had not fired. Both branches are reproduced.
* **Octave-tolerant continuity holds `last_f0`**: on an octave match the frame
  is accepted, `is_oct` is set, and `last_f0` is *not* updated; the held value
  is what enters `chain_f0s`.
* **The jitter gate runs on the RAW argmax**, not the accepted chain. With
  `reanchor` off the two are numerically identical, but the C keeps them as
  separate fields so re-enabling re-anchoring cannot silently change which
  series is gated.
* `np.median`: odd n → middle element; even n → mean of the two middle. The C
  sorts a copy and does the same.
* `above_thr` is computed **independently** of warmup, band and continuity,
  exactly as `track_frames` does — it is not "the frame was accepted".
* `band_threshold` is implemented in full even though both offsets are 0.0 and
  it currently returns `thr` unconditionally. The two-tier machinery is kept
  because the bench rig may move the priority band.

`SENTRY_MAX_CHAIN = 1024` bounds the chain arrays (longest vector is 916
frames). Overflow sets a flag that the host comparator treats as a hard
failure — it never wraps silently.

---

## 8. REJECTED features have no code path

Re-anchoring and comb-hold are **absent**, not disabled. `reanch` and
`n_held_bins` are emitted as constant 0 and the host comparator fails the run
if either is ever nonzero. `detector_config.h` carries `_Static_assert`s on
`CFG_REANCHOR_ENABLED == 0` and `CFG_HOLD_ENABLED == 0` with the rejection
rationale inline, so re-enabling one is a deliberate act with the measurement
that killed it in front of you.

`min_teeth == 0`, so the teeth gate is `#if`'d out rather than evaluated to
"always true" — but the `teeth` count itself is still computed and traced,
because it is a trace field.

---

## 10. The microphone: 24-in-32, and what is deliberately NOT done to it

The INMP441 emits **24-bit two's complement, MSB first, in a 32-bit slot**,
Philips timing (MSB one BCLK after the WS edge). The I2S peripheral assembles
that into a 32-bit word as

```
bits 31..8   the 24 data bits, sign correct by position
bits  7..0   zero - the mic drives nothing there
```

so the signed 24-bit value is `raw >> 8`, and the pipeline's int16 is the top
16 bits of it:

```c
dst[k] = (int16_t)(s_raw[k] >> 16);     /* arithmetic shift, sign preserved */
```

That is a pure rescale by 2^-16. Nothing else happens to the sample.

**NO DC removal, NO high-pass, NO gain, NO dither.** The Python reference has
no such stage, so adding one on the device would be an ALGORITHM CHANGE wearing
plumbing's clothes: it would move the floor, the energy gate and the flatness
moment, and every golden number would silently stop meaning what it says. The
DC offset is **measured instead** — meter mode reports it every 500 ms — and
the decision about whether it needs handling is a separate, evidenced one.

Where the DC offset actually lands, so the measurement can be read properly:
bin 0 is never a comb tooth (the lowest is `f0=70, k=1` -> bin 8), so DC cannot
contribute to a comb score directly. It *is* inside `mag.sum()` (the tonality
energy gate) and `r.mean()` / `r*r.mean()` (the flatness moments), so a large
offset biases the floor's fast/slow decision without ever showing up as a
score. That is the thing to watch in the meter numbers.

**Gain invariance, and its one limit.** `S = log1p(mag/floor)` with the floor a
linear EMA of `mag`, so scaling the input by k scales both and leaves S
unchanged; the energy gate is a ratio and the flatness moment is scale-free.
Microphone sensitivity therefore does NOT move the operating point. The limit
is the `+1e-9` in `mag/(floor + 1e-9)` and the `+1e-12` in the flatness
denominator: invariance holds only while levels stay well above those. Do not
right-shift the sample "to be safe" — that is the one way to break it.

### I2S configuration

| | |
|---|---|
| mode | `i2s_std`, master, RX only |
| slot | 32-bit, `I2S_SLOT_MODE_MONO`, `slot_mask = I2S_STD_SLOT_LEFT` |
| why LEFT | the mic's L/R pin is strapped to GND, so it drives the left slot |
| BCLK | `fs * 32 * 2` = 1.024 MHz — std mode always clocks two slots even when only one is stored |
| DMA | 6 descriptors x 512 frames = 3072 samples = **192 ms**, i.e. six whole hops of slack against a 19.6 ms compute |

Pins live in exactly one place, `main/board_pins.h`, and the running firmware
prints them in response to `I` — so what you read is what is flashed.

---

## 9. What is NOT covered by this port

* `combiner()` is the identity at `N_CHANNELS == 1`. The multi-channel branch
  is written but **never executed and never tested** — it is a placeholder for
  beamforming, not a validated path.
* `source_i2s()` is implemented (§10) but, as of writing, **has never seen a
  microphone**. It has been exercised end to end against a floating SD pin:
  the I2S clocks, DMA delivers, samples reach the detector, and C and Python
  agree decision-for-decision on 153 frames of that input. What is unproven is
  everything downstream of the connector.
* Both presets are now exercised: three parity vectors at NORMAL (2.14) and
  `golden_high_alert_pos` at HIGH_ALERT (1.70). Each vector is replayed at the
  threshold it was cut at, carried in `generated/vectors.h` as a named preset
  macro, and the comparator FAILS a run whose header threshold does not match
  the vector's entry in `golden_vectors.json`.
* Real-time is met: **19.6 ms p99 against a 32 ms hop, 61%**. See
  `PORT_LOG.md`.

---

## 11. TIER-2 — `main/detector_t2.c`

Tier-2 is a SECOND consumer of the same seam, not a second pipeline: it takes
the combiner's output exactly as `back_end` does, and it shares no mutable
state with `detector.c`. `G`, `Z`, `L`, `Y` and `R` never enter it. Everything
in §0–§8 above applies to it unchanged; this section records only what is
specific to the second tier.

### 11.1 The dtype decisions, all of them

| quantity | Python reference | C port | why |
|---|---|---|---|
| `floor2` | **float64** | **float64** | `np.where(up, a2_up, a2_dn)` builds a float64 array from two numpy scalars, exactly as v1's floor does. `src/detector_t2.py` mirrors that promotion ON PURPOSE — see its "NUMERICS" section — so the T2 port faces the identical, already-measured relationship the v1 port faces. One religion, one gate. |
| whitening `log1p` | float64 | **float32 `log1pf`** | The one deliberate divergence, and it is the SAME one v1 makes for the same reason: 1025 soft-float64 `log1p` calls cost ~21.8 ms of a 32 ms budget on a core with no double FPU. Within 1 ulp of float32 (~6e-8 on S). |
| magnitude | `np.abs(spec)` in float64, cast to float32 | `sqrtf(re*re+im*im)` in float32 | Identical line to `back_end`'s, identical divergence, already characterised in §0. |
| comb score | float32, numpy pairwise | float32, `t2_pw_sum_f32` | numpy's sum is not left-to-right even at n = 12. |
| decision arithmetic | Python floats | `double` | thresholds, continuity, f0. |
| `hits >= M2/2` | `st.hits * 2 >= m2` | `2 * st->hits >= c->m2` | written the same way on both sides so an odd M2 rounds identically. |

### 11.2 `t2_pw_sum_f32` is a byte-for-byte copy, and that is the point

`detector.c`'s `pw_sum_f32` is `static` and `detector.c` is frozen for this
branch, so the T2 port carries its own copy. If the two ever drift apart the
K-mode T2 gate fails, which is exactly what the gate is for.

### 11.3 The table duplication, measured

`generated/tables.h` declares its arrays `static const`, so including it in a
second translation unit gives that unit its own copy. **Measured cost: the
image grew from 0x1fc570 to 0x22de00, i.e. +197 KB** (about 189 KB of tables
plus ~8 KB of new code), leaving 73% of the app partition free.

D3 requires the T2 grid to be rows 130–730 of the EXISTING tables and forbids
new ones, and `detector.c` is frozen, so a shared-linkage table was not
available tonight. **The one-line fix for the first session allowed to touch
`detector.c`:** move the table definitions into a translation unit of their own
and declare them `extern const` in `tables.h`. Both tiers then share one copy
and the 189 KB comes back.

### 11.4 Coherence is evaluated at the teeth, not over the spectrum

The reference computes `C(b)` over all 1025 bins and then takes a
tooth-weighted mean. The port evaluates `C(b)` **only at the winner's teeth** —
the same ≤ 12 gathers the score already performs — because every other bin is
multiplied by a zero weight. Same number, roughly 40× less work: 24 bin reads
instead of four passes over the spectrum. The brief budgeted ~1.2 ms for this;
it is now negligible.

With one channel, `C(b) = |X|² / (1 · |X|²) = 1` identically, which is why a
mono `K` replay carries `kappa = 1.0` rather than a missing field — and why the
comparator FAILS a mono capture whose kappa is anything else.

### 11.5 Half rate

`st->frame_i++ % decim` is evaluated with the SAME pre-increment order as the
Python (`st.frame_i += 1` then test), so frame 0 always runs on both sides.
Every frame count halves and the floor coefficients are re-derived for the
doubled step, so the integration measured in SECONDS is unchanged. The
comparator detects a rate mismatch as a step-count difference and says so
rather than diffing misaligned series.

### 11.6 What is deliberately NOT in the parity gate

The Python event record carries a MEDIAN f0 over the event; the device's `AL2`
record carries the track f0 **at the firing frame**. Both are telemetry, and
neither is a per-frame field, so neither is diffed. Storing every f0 of a
latched event on the device would be an unbounded buffer for a reporting field.

### 11.7 CX-A is called, not reimplemented

`combiner_cx('a', ...)` returns `detector.c`'s own `combiner()` result, and
`combiner_cx('d', ..., busoff == 0)` falls through to it. So `H` with default
arguments is provably the same arithmetic as `G` — regrouping the sum as
`(M1+M2) + 1.0*(M3+M4)` would change the accumulation order and therefore the
last bits, which is precisely the class of difference this project refuses to
accept by inspection.

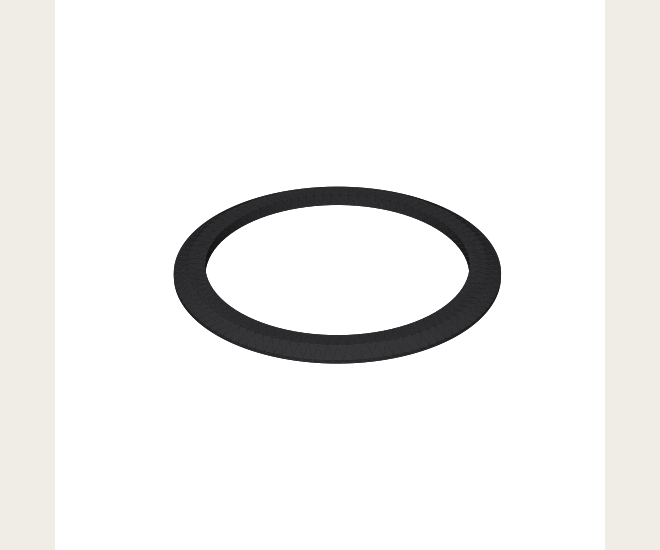
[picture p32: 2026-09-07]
hardware/enclosure/renders/VolAnti_GrilleRing.png

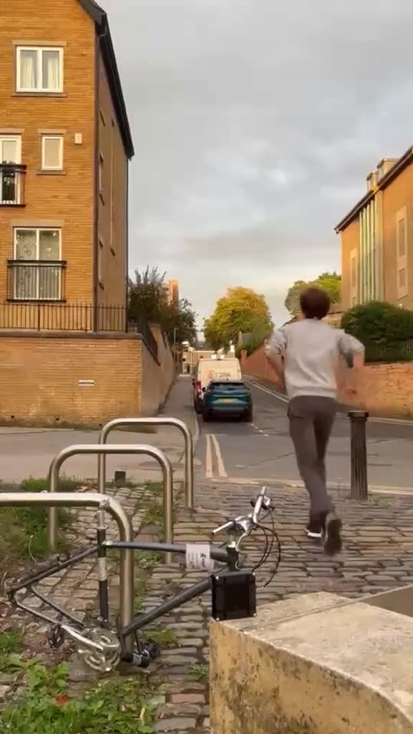
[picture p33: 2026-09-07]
assets/field/104m-poster.jpg

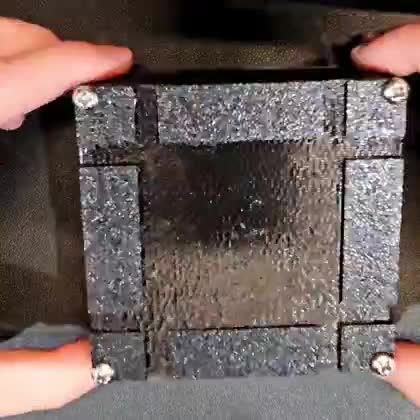
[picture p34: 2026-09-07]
assets/field/in-hand-poster.jpg

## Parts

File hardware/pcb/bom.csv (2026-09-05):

Comment | Designator | Footprint | JLCPCB Part # | LCSC Part #
TMB12A03 | BZ1 | Through Hole D12mm P7.6mm |  | C96222
CL10A475KP8NNNC | C1, C2, C3 |  |  | C1705
GRM188R61A226ME15L | C6, C7, C8 | C0603 |  | C167429
CL10B104KB8NNNC | C10, C11, C15, C16, C18, C20, C22, C25 | C_0603_1608Metric |  | C1591
CL10A106KP8NNNC | C12, C4, C5, C9 |  |  | C19702
CL10A105KB8NNNC | C13, C17, C19, C21, C23 | C_0603_1608Metric |  | C15849
MMASL168BB5106MTNA01 | C14 | C_0603_1608Metric |  | C6594205
6SVPC330M | C24 | CAP-SMD_BD6.3-L6.6-W6.6-FD |  | C139569
OCV101M0JTR-0606 | C26 | CAP-SMD_BD6.3-L6.6-W6.6-LS7.2-R-RD |  | C134854
USBLC6-2SC6 | D1 |  |  | C7519
1N4148W-13-F | D2, D3 | SOD-123_L2.7-W1.6-LS3.7-RD |  | C112342
BLM18AG601SN1D | FB1 |  |  | C19330
TYPE-C-31-M-12 | J1 | USB-C_SMD-TYPE-C-31-M-12 |  | C165948
B2B-PH-SM4-TB(LF)(SN) | J2 | CONN-SMD_B2B-PH-SM4-TB-LF-SN |  | C160352
XFL4020-152MEC | L1 |  |  | C3033018
WS2812B-V6 | LED1 | SMD5050-4P |  | C52917433
ICS-43434 | M1, M2, M3, M4 | LGA-6 3.5x2.65mm bottom-port |  | C5656610
MMBT2222ALT1G | Q1, Q2 | SOT-23 |  | C82460
0603WAF5101T5E | R1, R2 | R_0603_1608Metric |  | C23186
ERJ3EKF1781V | R3 | R_0603_1608Metric |  | C403029
RC0603FR-073K01L | R4 | R_0603_1608Metric |  | C137732
RC0603FR-0790K9L | R5 | R_0603_1608Metric |  | C185305
CL0603FN3K48P | R7 | R_0603_1608Metric |  | C52209912
ERJ-U03F1783V | R10 | R_0603_1608Metric |  | C1859202
0603WAF1004T5E | R11, R9 | R_0603_1608Metric |  | C22935
0603WAF1003T5E | R12, R13, R8 | R_0603_1608Metric |  | C25803
0603WAF1002T5E | R14, R6 | R_0603_1608Metric |  | C25804
0603WAF1001T5E | R15, R16 | R_0603_1608Metric |  | C21190
0603WAF3300T5E | R17 | R_0603_1608Metric |  | C23138
MK-12C02-G015 | S1 | SW-SMD_G-SWITCH_MK-12C02-G015 |  | C2911519
K2-1114SA-A4SW-06 | SW2, SW3 | KEY-SMD_4P-L4.8-W4.6-P1.70-LS6.2 |  | C136662
TS-1187A-B-A-B | SW4 | SW-SMD_4P-L5.1-W5.1-P3.70-LS6.5-TL-2 |  | C318884
BQ24074RGTR | U1
TPS63020DSJR | U2 |  | C15483
ESP32-S3-WROOM-1-N16R8 | U3 | WIRELM-SMD_ESP32-S3-WROOM-1 |  | C2913202
Ra-01H | U4 | WIRELM-SMD_RA-01H |  | C503593

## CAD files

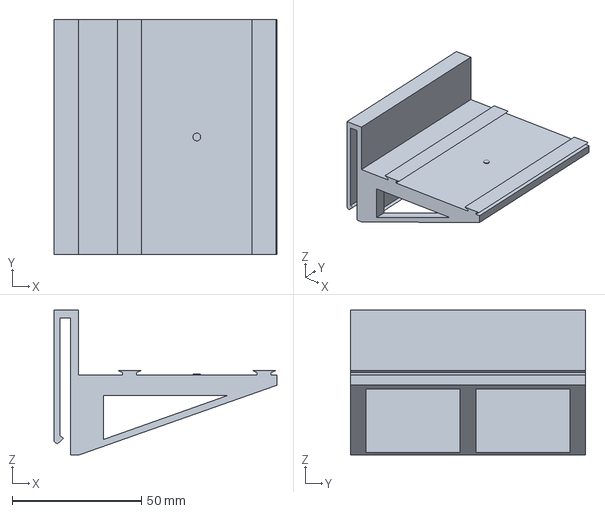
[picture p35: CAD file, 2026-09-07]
hardware/enclosure/step/VolAnti_Mount.step
86.2 x 91.0 x 56.0 mm

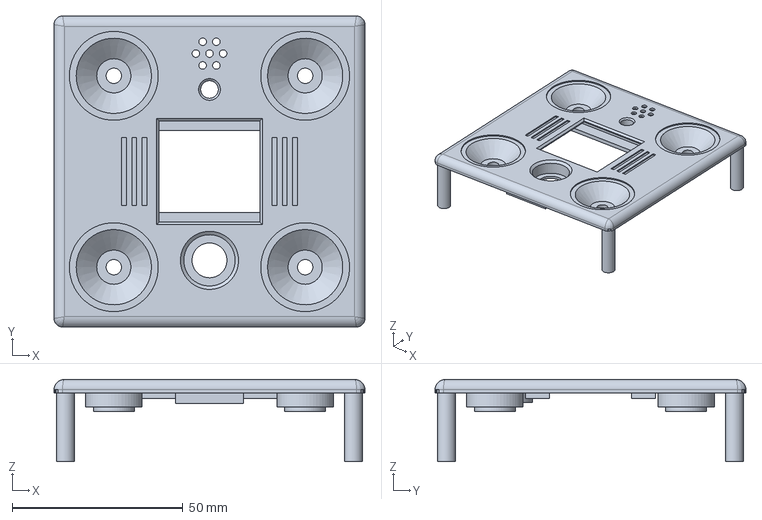
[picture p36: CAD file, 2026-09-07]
hardware/enclosure/step/VolAnti_Lid.step
91.0 x 91.0 x 24.0 mm

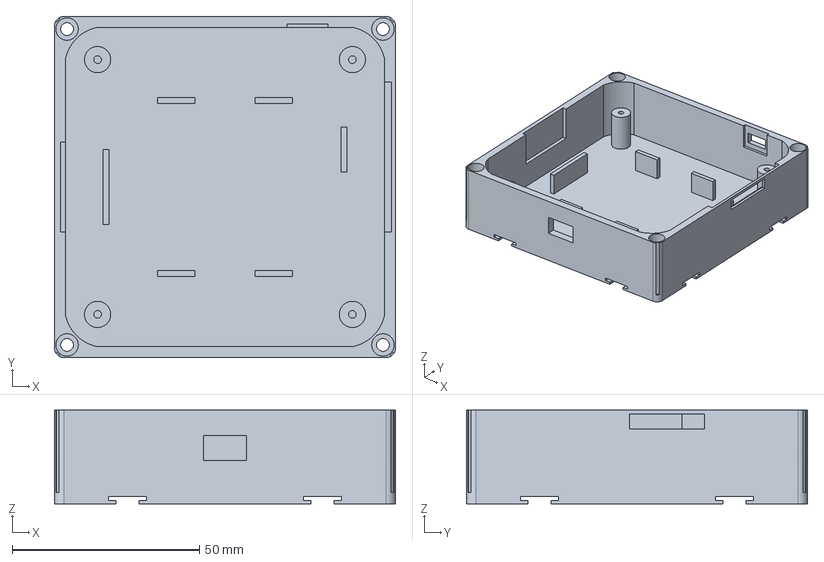
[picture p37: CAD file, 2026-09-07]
hardware/enclosure/step/VolAnti_Base.step
91.0 x 91.0 x 25.0 mm

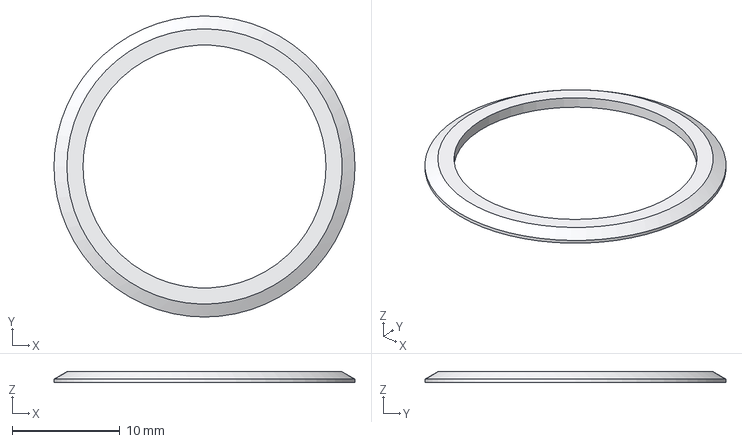
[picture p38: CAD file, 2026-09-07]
hardware/enclosure/step/VolAnti_GrilleRing.step
28.0 x 28.0 x 1.00 mm

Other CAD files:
hardware/enclosure/stl/VolAnti_Base.stl
hardware/enclosure/stl/VolAnti_GrilleRing.stl
hardware/enclosure/stl/VolAnti_Lid.stl
hardware/enclosure/stl/VolAnti_Mount.stl

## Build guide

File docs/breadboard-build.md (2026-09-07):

# Building it on a breadboard

The full detector on a dev board, with no custom PCB and no printed parts. This is how VolAnti was developed for its first weeks. Every algorithm in the firmware was proven on exactly this before a board was ordered, and the same image runs on both.

What you give up against the full unit: the sealed case and its wind performance, the e-paper that holds an alert with the power off, a tidy loud beeper, and a few dB of consistency from fixed microphone geometry.

The breadboard build wired up

## Parts

| Part | What to buy | Notes |
|---|---|---|
| Controller | ESP32-S3-DevKitC-1 **N16R8** | The memory variant matters. The firmware assumes 16 MB flash. |
| Microphones | 4 × I2S MEMS breakout, ICS-43434 or INMP441 | Any I2S breakout with SCK, WS, SD and L/R pins. |
| Display | Waveshare 1.54 in e-paper V2, black and white | Optional on the bench. The serial console shows everything. |
| LED | WS2812 breakout, 330 Ω, 100 µF | Optional. |
| Beeper | 3 V active beeper, BC337 or 2N2222, 1 kΩ, 1N4148 | Optional. Never drive a beeper straight from a GPIO pin. |
| Motor | 3 to 5 V coin vibration motor, same driver as the beeper, 470 µF | Optional. |
| Button | 6 mm tactile switch | |
| Power | USB-C data cable from your computer | The only supply. If you fit beeper, motor and radio together, expect brown-outs on USB alone. |

Plus a breadboard, male-to-male jumpers, 10 µF and 100 nF rail capacitors, and something stiff to mount the four microphones on. Skip the LoRa radio. It is a multi-unit feature and easy to add later. About £35 to £45 in total.

## Wiring

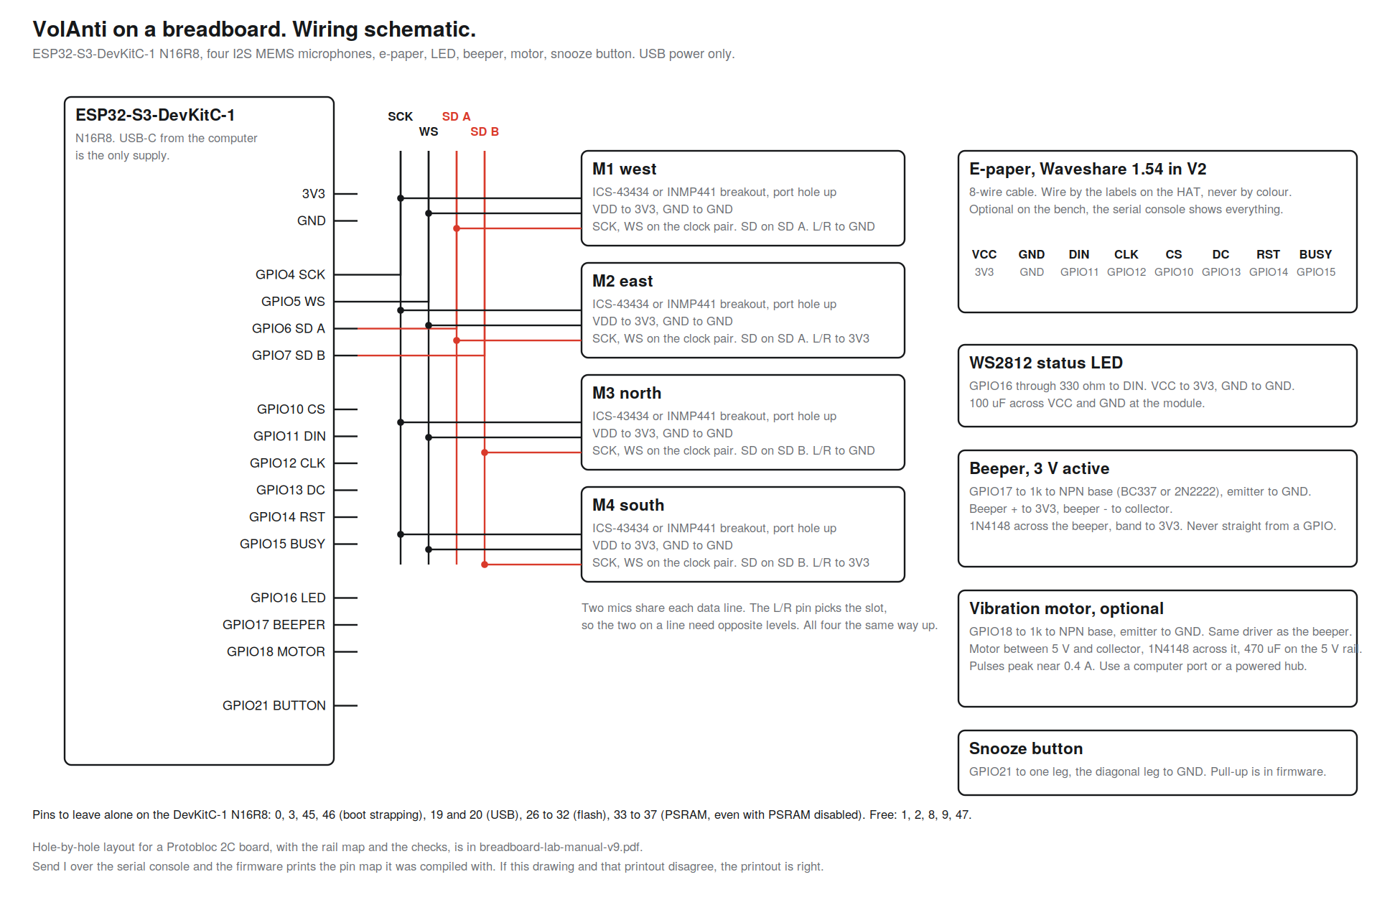
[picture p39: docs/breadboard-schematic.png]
Wiring schematic


[SVG version](breadboard-schematic.svg). The hole-by-hole layout with the rail map and the checks at every stage is [breadboard-lab-manual-v9.pdf](breadboard-lab-manual-v9.pdf), for a Protobloc 2C board. The earlier [v5 manual](breadboard-lab-manual-v5.pdf) does the same build on five clipped 830-point breadboards, if that is what you have.

All four microphones share one clock pair. They split across two data lines, two mics each, and the L/R pin picks which slot each one drives.

| Mic | Position | SD to | L/R to |
|---|---|---|---|
| M1 | west | GPIO6 | GND |
| M2 | east | GPIO6 | 3V3 |
| M3 | north | GPIO7 | GND |
| M4 | south | GPIO7 | 3V3 |

SCK on GPIO4 and WS on GPIO5 go to all four. Every mic: VDD to 3V3, GND to GND, same orientation, port hole up and never covered.

| GPIO | Function |
|---|---|
| 10, 11, 12, 13, 14, 15 | E-paper CS, DIN, CLK, DC, RST, BUSY. Wire by the labels on the HAT, never by wire colour. |
| 16 | WS2812 data, through 330 Ω |
| 17 | Beeper, through 1 kΩ to the transistor base |
| 18 | Motor, same driver, on the 5 V rail |
| 21 | Snooze button to GND. The pull-up is in firmware. |

Leave these alone on the DevKitC-1: 0, 3, 45 and 46 (boot strapping), 19 and 20 (USB), 26 to 32 (flash), and 33 to 37, which are bonded to the PSRAM die even when PSRAM is off and fail intermittently rather than cleanly. Free for your own additions: 1, 2, 8, 9, 47.

## Geometry

Mount the four breakouts on stiff card in a plus, about 56 mm across, ports up, M1 west, M2 east, M3 north, M4 south. Exact spacing does not matter for detection. It only matters that they stay put and all face the same way.

## Bring-up

1. Flash the `devkit` target. See [flashing.md](flashing.md).
2. Open the serial console and send `I`. The firmware prints the pin map it was compiled with. If your wiring and that printout disagree, the printout wins.
3. The boot report should show four healthy channels with quiet RMS values in the same order of magnitude, around 250 to 420 each on a bench. One silent channel is always a wiring fault.
4. Tap next to each mic and watch its channel respond. This catches swapped positions that every electrical check passes.
5. Play the clips in [test/audio](../test/audio/) from a phone at half a metre and watch the score cross 1.70 on the fast tier.

From here the unit behaves exactly like a boxed one. [Deploying](deploying.md) and [test results](test-results.md) apply unchanged.

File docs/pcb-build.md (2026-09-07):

# Building the full unit

Custom four-layer board, four printed parts, a battery, a screen and a radio in a sealed 91 mm box. Two evenings once the parts arrive. The board comes from the fab with everything placed except four through-hole parts.

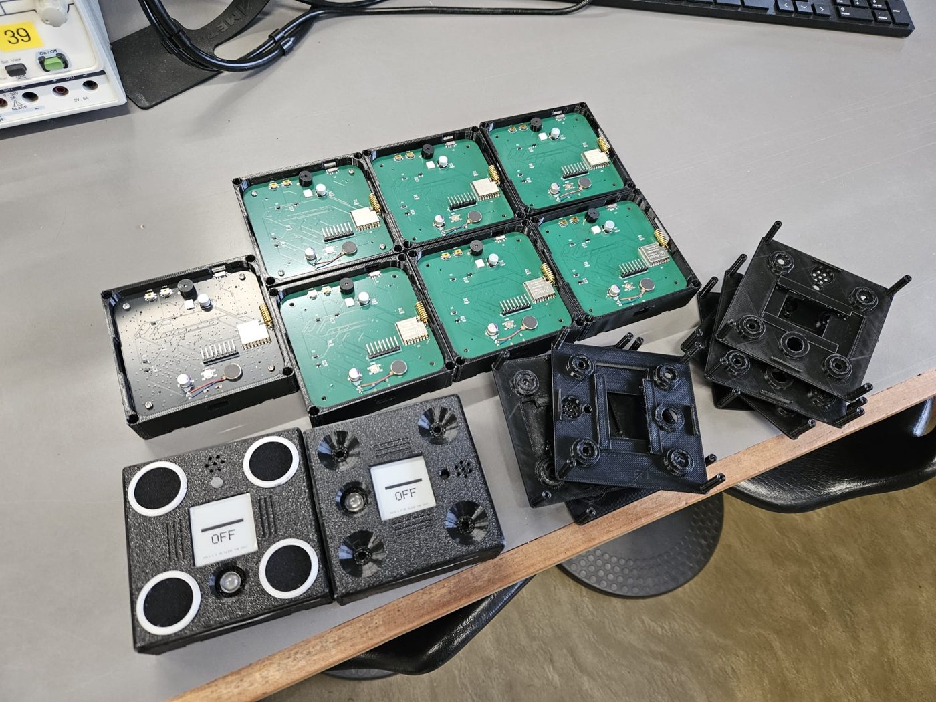
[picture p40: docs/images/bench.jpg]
Boards in their bases, lids alongside, on the bench


## What you order

| | Where | Files |
|---|---|---|
| The PCB, assembled | JLCPCB or any fab with SMT assembly | [gerbers](../hardware/pcb/gerbers/), [bill of materials](../hardware/pcb/bom.csv), [placement](../hardware/pcb/pick-and-place.csv), [ordering notes](../hardware/pcb/README.md) |
| Four printed parts | Your printer, or any print service | [STL and STEP files, print settings](../hardware/enclosure/README.md) |
| Fit parts | Anywhere | Table below |

The design itself lives in Flux: [flux.ai/agamrossen/sentry-node-v1](https://www.flux.ai/agamrossen/sentry-node-v1~wa). The schematic and every net is readable there.

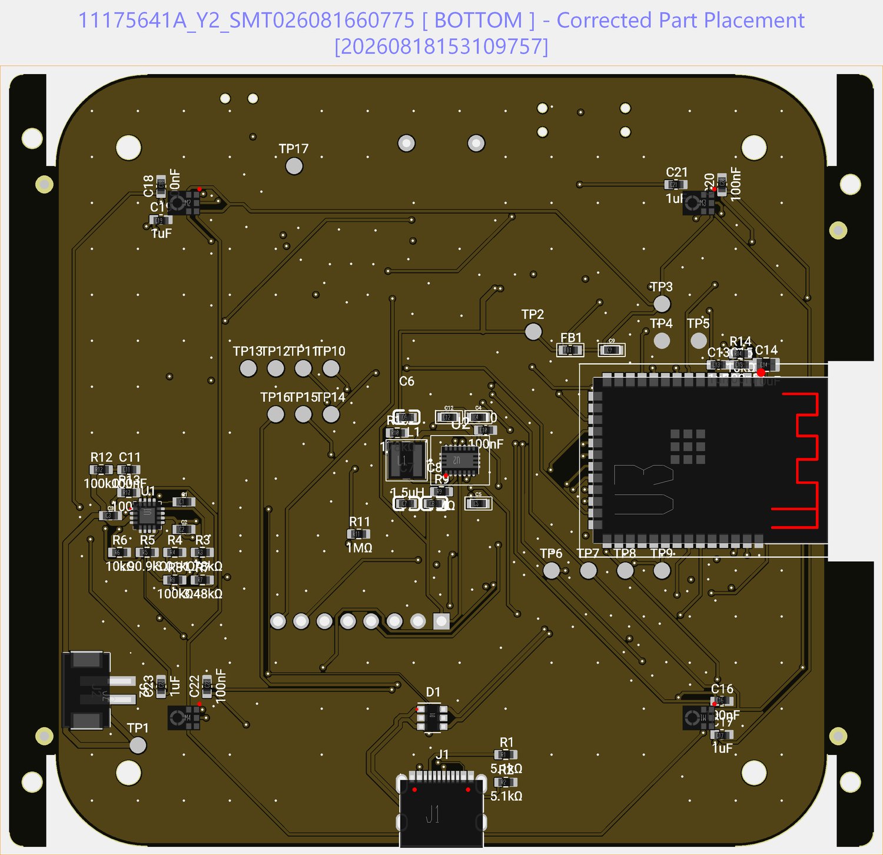
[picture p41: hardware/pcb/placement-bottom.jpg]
Placement drawing, underside of the board


## Fit parts

| Part | Spec |
|---|---|
| Battery | Protected 1S LiPo, 2500 mAh, JST-PH 2.0, no larger than 61 × 51 × 8 mm. PKCELL LP785060 or similar. |
| Battery pad | 1 mm EVA foam, cut to the bay |
| Display | Waveshare 1.54 in e-paper V2, black and white, 200 × 200. Not the three colour one, it refreshes far too slowly. |
| Antenna | Solder-type spring antenna, 868 or 915 MHz, about 17 mm coil |
| Beeper | TMB12A03 |
| Display header | 8 pin 2.54 mm right-angle male header |
| Motor, optional | Ø10 mm ERM coin motor |
| Light pipe | 5 mm clear acrylic rod, cut to 9 mm |
| Snooze dome | Ø9.5 × 3.8 mm clear hemispherical self-adhesive bumpon |
| Grille cloth | Thin woven speaker cloth, 0.4 mm or less, four Ø25 mm discs |
| Mic gaskets | 2 mm closed-cell foam rings, Ø8 mm with a Ø5 mm hole, four |
| Sealant | Neutral-cure silicone, Permatex Ultra Black 22072 or similar. Never acetic-cure near the microphones. |
| Desiccant | Two 1 g silica gel sachets |
| Screws | 4 × M2.5 × 8 mm machine screws for the board. 4 × ST2.9 × 9.5 mm stainless self-tappers for the lid. Not M3 machine screws, they split the printed pilots. |

## Hand soldering

Four joints. The fab places everything else, including the USB-C and the battery socket.

1. **Beeper, BZ1.** Top side. The pins come at 6.5 mm and the pads are 7.6 mm, so splay them gently. Polarity matters: left pad is +.
2. **Display header, J3.** Right-angle, top side, pins pointing toward the display bay. Pin order VCC, GND, DIN, CLK, CS, DC, RST, BUSY.
3. **Antenna, ANT1.** Onto the pad on the east edge, lying flat and parallel to the board so it drops into the wall channel. Do not trim the spring.
4. **Motor, MP1 and MP2.** Optional. The driver is already on the board. The motor lies flat on the top face.

## Check before it goes in the box

Power over USB-C with the battery connected. Check the plug polarity first: red must reach the VBAT pin of J2. If it is reversed, lift the two crimp tabs with a pin and swap them.

The unit boots to LISTENING in about two seconds and runs its output parade once. Then over the serial console: send `I` and confirm four healthy microphones, tap next to each port and watch the right channel respond, press the snooze button and see it register. Everything is reachable now. Nothing is once the lid is on.

## Assembly, in this order

Base, lid, grille ring and mount

1. Stick the snooze dome centred on the tactile switch. Press it twenty times before you go on. A mis-centred dome binds in the lid.
2. Foam gasket rings around the four microphone ports.
3. Foam pad into the battery bay, then the cell, plug into J2.
4. Board onto the four bosses, 4 × M2.5 × 8. Snug, not tight, the bosses are plastic.
5. Display into the lid tray on thin double-sided tape at the corners. Its cable plugs onto J3. The stock 200 mm cable needs coiling, or shortening and re-crimping.
6. Light pipe, 9 mm of 5 mm rod, faces polished through 400, 800 and 1200 grit, press-fit into the lid port. One wrap of PTFE tape if it is loose.
7. Grille cloth discs into the four cone recesses, bonded with a thin ring of silicone, then the grille rings on top.
8. Two silica sachets taped flat to the base floor. These go in last. At service time a saturated sachet tells you that unit's seal has failed.
9. Lid on. Corner posts and the north and south tabs, then 4 × ST2.9 × 9.5 from below.

## First power-up in the box

Hold it at arm's length. Green blink through the light pipe, LISTENING screen with four microphone marks, one clean chirp. Tap the dome and see the snooze register. Then do the only test that matters: carry a real source past it at a known distance and write down what happened. [Test results](test-results.md) has the format.

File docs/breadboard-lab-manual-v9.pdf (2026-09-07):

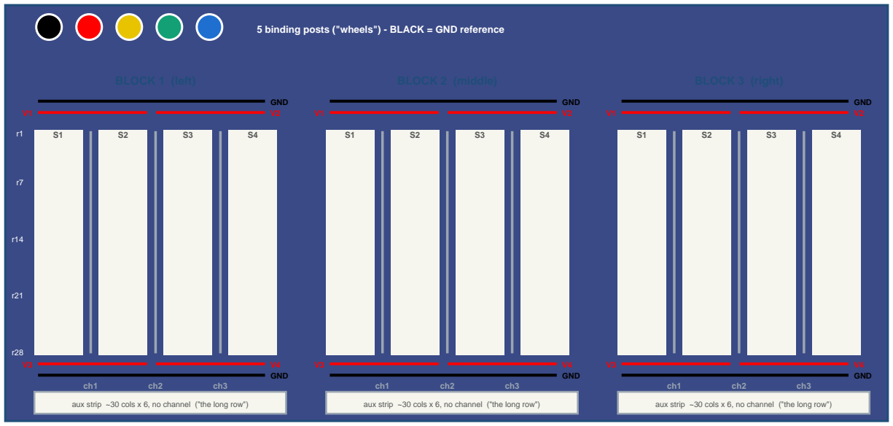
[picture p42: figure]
GND; BLOCK 1 (left); BLOCK 2 (middle); BLOCK 3 (right)

WIRE COLOURS: 5V | 3V3 | GND | SCK | WS | SD_A | SD_B | EPD | CTRL | SENTRY-Node lab manual v9 - Protobloc 2C as-built - p. 1

# SENTRY-Node - Breadboard Lab Manual v9 (Protobloc 2C - rails as-built)

v9 - RAILS AS-BUILT Per block, SIX rail nets: a continuous BLACK GND line outermost top and bottom, plus FOUR independently named half-rails - V1 (top-left), V2 (top-right), V3 (bottom-left), V4 (bottom-right) - split at mid-block. V1 and V2 are different nets, not one broken rail. Only TWO bridges exist in the whole build (B2 and B3, V1-V2). B3 V3|V4 deliberately carry different signals (SCK|WS). Everything else as v8: three vertical channels per block, blocks electrically separate, aux strips at the bottom, posts top-left, DevKit USB-up in B2, e-paper off-board, array coordinates unchanged.

## 1 · Board anatomy (verified)

### 5 binding posts ("wheels") - BLACK = GND reference

aux strip ~30 cols x 6, no channel ("the long row") | aux strip ~30 cols x 6, no channel ("the long row") | aux strip ~30 cols x 6, no channel ("the long row")

Rails are HORIZONTAL and PER BLOCK - nothing continues from one block to the next. BLACK rails (outermost) run the whole block = GND. The inner red line is TWO separate named half-rails: V1|V2 (top), V3|V4 (bottom).
Blocks | Three electrically separate blocks side by side. Per block: four vertical sets S1-S4, each 6 hole-columns x 28 rows. Hole columns c1-c24: S1=c1-6, S2=c7-12, S3=c13-18, S4=c19-24.
Nets | One net = one ROW within one set = 6 holes in a horizontal line. Every row has FOUR separate nets (one per set). A seated pin leaves 5 free holes on its net, same row, same side.
Channels | ch1 (c6|c7), ch2 (c12|c13), ch3 (c18|c19) - vertical, 0.3 in across (F2: verify on one module). Two-row parts straddle them; nothing conducts across a channel.
Rails | SIX nets per block, all horizontal. Outermost top + bottom: BLACK continuous GND lines, 24 holes, full block width. Inner top: V1 (left 12 holes) and V2 (right 12) - separate nets. Inner bottom: V3 (left) and V4 (right) - separate nets. The split sits at mid-block, under ch2. NOTHING joins block to block except your jumpers.
Lettering | Board silkscreen: sets read A-F / G-L / A-F / G-L = S1-S4 (c1-24); rows numbered 1-28 on both edges; aux strip a-f x 1-30. V1-V4 are printed at the rail halves.
Aux strips | The "long row" along the board bottom: ~30 columns x 6 per block, no channel. Unallocated - use as a jumper park / spare field.
Posts | 5 x 4 mm binding posts, top-left. BLACK is wired to GND as the DMM / scope reference. Others unused.

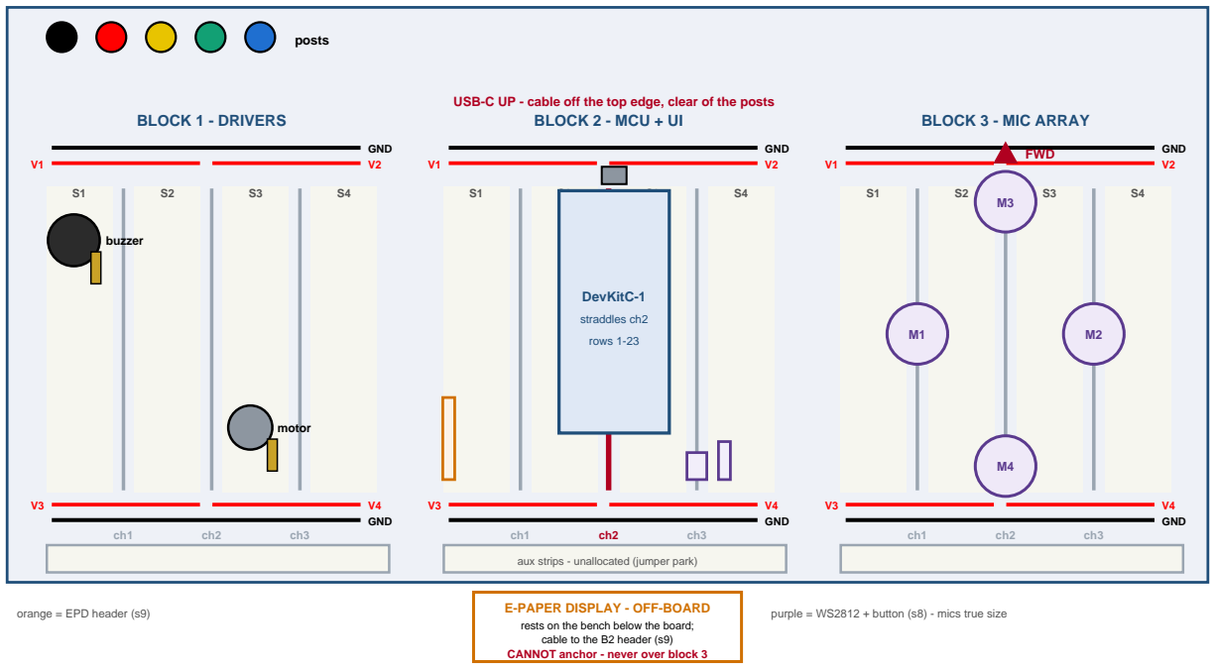
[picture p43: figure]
posts; GND; BLOCK 1 - DRIVERS; BLOCK 2 - MCU + UI; BLOCK 3 - MIC ARRAY; aux strips - unallocated (jumper park); buzzer; motor; DevKitC-1; straddles ch2; rows 1-23; FWD; E-PAPER DISPLAY - OFF-BOARD; rests on the bench below the board; cable to the B2 header (s9) CANNOT anchor - never over block 3

WIRE COLOURS: 5V | 3V3 | GND | SCK | WS | SD_A | SD_B | EPD | CTRL | SENTRY-Node lab manual v9 - Protobloc 2C as-built - p. 2

## 2 · Census (10 minutes, before anything else)

2a | Count: 3 channels per block, 28 rows per set, 6 holes per row-net. Confirm the aux strip length (expect ~30).
2b | DMM the rails: BLACK top + bottom lines continuous end to end; V1-to-V2 OPEN (separate nets); V3-to-V4 OPEN. Note any block that differs.
2c | Hole-to-hole across each channel: must be 0.3 in / 7.62 mm (one INMP441 module must drop straight in). Check the MIDDLE channel (ch2, the L|A boundary) especially - M3, M4 and the DevKit all straddle it. If 0.2 in anywhere, STOP - flag it.
2d | Seat the DevKit once in block 2 straddling ch2, USB toward the top edge. Record: which columns its two pin rows land in (expect c9/c10 and c17/c18), the row of pin 1, the total row span (expect ~23), and the ROW NUMBER of every labelled pin used in §5.
2e | If any count disagrees with this manual: stop, send the counts, geometry gets reissued from reality.

## 3 · Whole-board allocation

USB-C UP - cable off the top edge, clear of the posts

orange = EPD header (s9) | purple = WS2812 + button (s8) - mics true size

WIRE COLOURS: 5V | 3V3 | GND | SCK | WS | SD_A | SD_B | EPD | CTRL | SENTRY-Node lab manual v9 - Protobloc 2C as-built - p. 3

## 3.1 · Inter-block wiring (the only things that cross blocks)

Run | From | To | Colour
5V | DevKit 5V pin | B1.V4 (bottom-right half - motor side). No bridge | red
3V3 | DevKit 3V3 pin | B2.V1 -> bridge -> B2.V2; B2.V1 -> B1.V1; B2.V2 -> B3.V1 -> bridge -> B3.V2 | orange
GND | DevKit GND pin | B2 blacks (top + bottom) -> B1 blacks -> B3 blacks -> BLACK post | black
Clocks | GPIO4 / GPIO5 | B3.V3 = SCK (bottom-LEFT half) / B3.V4 = WS (bottom-RIGHT half). NO bridge between them | yellow / white, twisted with a spare GND
SD bus A | GPIO6 | M1 pad row -> daisy -> M2 pad row | blue
SD bus B | GPIO7 | M3 pad row -> daisy -> M4 pad row | green
Drivers | GPIO17 / GPIO18 | B1 buzzer 1k / B1 motor 1k | grey

## 3.2 · Rail map - all eighteen rail nets

Block | GND-T (black, full) | V1 (top-L) | V2 (top-R) | V3 (bot-L) | V4 (bot-R) | GND-B (black, full)
B1 drivers | GND | 3V3 - buzzer | spare | spare | 5V - motor. ONLY 5V on the board | GND
B2 MCU+UI | GND (feed + post) | 3V3 (feed) | 3V3 - BRIDGE to V1 | spare | spare | GND - all UI grounds
B3 array | GND | 3V3 | 3V3 - BRIDGE to V1 | SCK + tape | WS + tape. NEVER bridge V3-V4 | GND

## 4 · Mic array geometry (values unchanged from v7)

Mic | Pads (block 3) | Centre | x (m) | y (m) | SD | L/R
M1 West | c6 / c7, rows 13-15 | (ch1, r14) | -0.02032 | 0.00000 | GPIO6 | GND
M2 East | c18 / c19, rows 13-15 | (ch3, r14) | +0.02032 | 0.00000 | GPIO6 | 3V3
M3 North = FWD | c12 / c13, rows 1-3 | (ch2, r2) | 0.00000 | +0.03048 | GPIO7 | GND
M4 South | c12 / c13, rows 25-27 | (ch2, r26) | 0.00000 | -0.03048 | GPIO7 | 3V3
Baselines | E-W = ch1 to ch3 = 16 pitches = 40.64 mm EXACT. N-S = 24 rows on ch2 = 60.96 mm EXACT. Centres coincide at (ch2, row 14). Zero measured constants.
Aliasing | E-W 4220 Hz, N-S 2813 Hz, adjacent arms 4682 Hz. The full 150 Hz - 2 kHz search band is alias-free; the old 1.5 kHz spatial band limit stays DELETED. Max inter-mic delay 178 us.
Orientation | FORWARD = 0 deg = the row-1 edge = the USB edge. The device points the way the cable leaves.
Buses | M1+M2 = bus A (GPIO6), M3+M4 = bus B (GPIO7): each orthogonal pair lives inside one I2S peripheral, so residual clock offset between peripherals cannot corrupt a baseline.

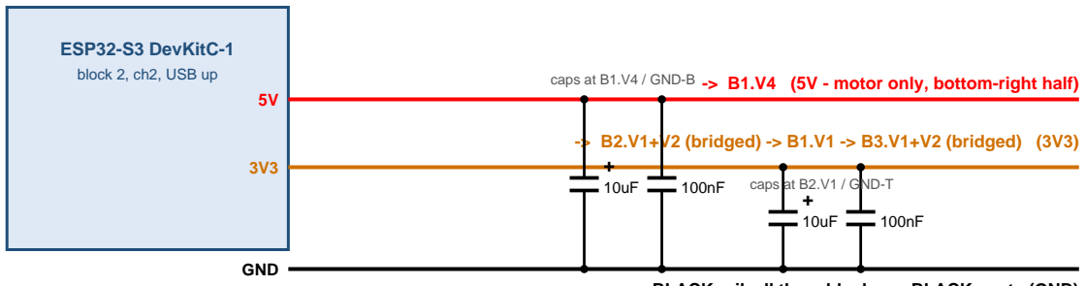
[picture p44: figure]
ESP32-S3 DevKitC-1; block 2, ch2, USB up; GND; caps at B1.V4 / GND-B; caps at B2.V1 / GND-T

WIRE COLOURS: 5V | 3V3 | GND | SCK | WS | SD_A | SD_B | EPD | CTRL | SENTRY-Node lab manual v9 - Protobloc 2C as-built - p. 4

## 5 · Master pin map

Signal | GPIO | Colour | Notes
I2S SCK - all 4 mics | 4 | yellow | shared, to B3.V3
I2S WS - all 4 mics | 5 | white | shared, to B3.V4
I2S SD bus A - M1, M2 | 6 | blue | M1 left slot, M2 right slot
I2S SD bus B - M3, M4 | 7 | green | 2nd I2S peripheral, same clock master
E-paper CS/DIN/CLK/DC/RST/BUSY | 10/11/12/13/14/15 | purple | wire by HAT labels only
WS2812 data | 16 | grey | via 330R
Buzzer base | 17 | grey | via 1k
Motor base | 18 | grey | via 1k
Snooze button | 21 | grey | to GND, internal pull-up
KEEP CLEAR | 0, 3, 19, 20, 26-37, 43-46 | - | strapping / USB / flash / PSRAM / UART
Spares | 1, 2, 8, 9, 39-42, 47 | - | 38 / 48 may drive the onboard RGB

## 6 · Power [B2 rails + B1 rails]

USB-C from Mac = only power source

-> B1.V4 (5V - motor only, bottom-right half)

-> B2.V1+V2 (bridged) -> B1.V1 -> B3.V1+V2 (bridged) (3V3)

-> every BLACK rail, all three blocks + BLACK post (GND)
Only TWO bridges in the whole build: B2 V1-V2 and B3 V1-V2. B3 V3-V4 stays OPEN - they carry different signals.
Parts | Checks (gate - nothing else is wired until these pass)
10uF x2, 100nF x2, 470uF x1, 2 bridges (B2 + B3 V1-V2), inter-block jumpers per §3.1 | 3V3 3.25-3.40 V at B1.V1, B2.V1+V2, B3.V1+V2 • 5V 4.6-5.15 V at B1.V4 • every black rail to the black post < 1 ohm • B3.V3 to B3.V4 reads OPEN • electrolytic stripe = GND side

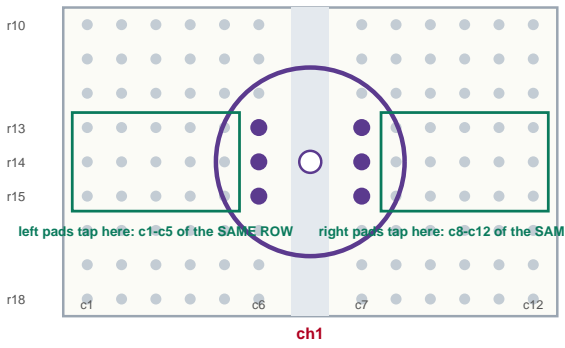
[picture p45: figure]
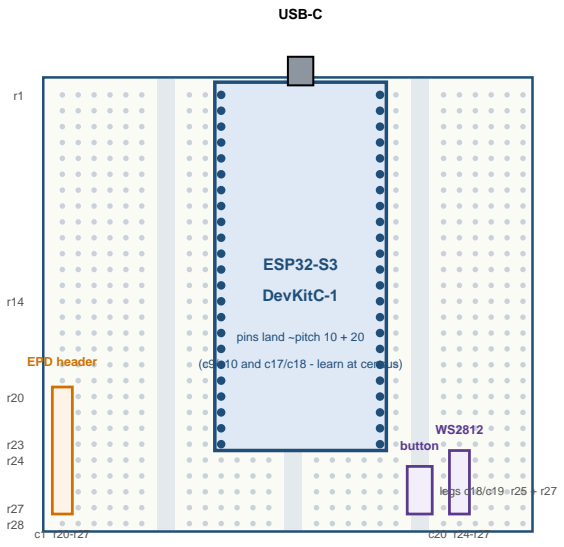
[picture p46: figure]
USB-C; ESP32-S3; DevKitC-1; pins land ~pitch 10 + 20; button; legs c18/c19 r25 + r27

WIRE COLOURS: 5V | 3V3 | GND | SCK | WS | SD_A | SD_B | EPD | CTRL | SENTRY-Node lab manual v9 - Protobloc 2C as-built - p. 5

## 7 · Mic M1 - first light (= Stage 1b) [B3, ch1, pads c6/c7, rows 13-15]

left pads tap here: c1-c5 of the SAME ROW right pads tap here: c8-c12 of the SAME ROW

PORT HOLE UP (white dot) - never covered

M1 exactly as seated: pads c6 / c7, rows 13-15, straddling ch1

Each ROW-in-set is one 6-hole net. A pad in c6 r13 owns c1-c5 of r13; a pad in c7 r13 owns c8-c12 of r13. Same pattern at ch2 / ch3 (shift columns by +6 / +12).
Seat | M1 straddles B3 ch1, pads c6/c7 in rows 13-15, port up. FINAL position - no relocation later.
Wiring | VDD (c6 r14) -> B3.V1 (3V3) • GND (c6 r15) -> GND-T (black) • SD (c6 r13) -> GPIO6 • SCK (c7 r13) -> B3.V3 (bottom-LEFT half - short run) • WS (c7 r14) -> B3.V4 (bottom-RIGHT half - crosses mid-block) • L/R (c7 r15) -> GND-B (black). Pad-to-signal order is by YOUR module silkscreen - confirm before wiring, variants differ.
Checks | Live 24-bit stream • clap = clean full-scale transient • no stuck or repeated words • steady noise floor

## 8 · DevKit + UI [B2]

EPD header | (c9/c10 and c17/c18 - learn at census)

BLOCK 2. DevKit rows 1-23 (23-row span typical - RECORD the real span and the row of every labelled pin at census). Rows 24-28 stay free for the UI.
DevKit | Straddles ch2, rows 1-23, USB-C at the row-1 end, cable off the TOP edge - same side as the posts but two blocks away from them. Never seat it USB-down.
Button | Straddles ch3, legs c18/c19 at rows 25 and 27. GPIO21 -> c13 r25 (S3 net) • c24 r27 -> GND-B (bottom black). Uses one leg from each DIAGONAL pair. 100nF across c13 r25 / c24 r27 if it double-fires.
WS2812 | Pins vertical in c20, rows 24-27 (one row-net per pin, identify DIN/VCC/GND by silkscreen). GPIO16 -> c24 r22 -> 330R (c21, r22-r24) -> DIN row. VCC row -> B2.V2 (3V3, right half - nearby), GND row -> GND-B (bottom black). 100uF legs into the VCC and GND rows at c19, + to VCC.

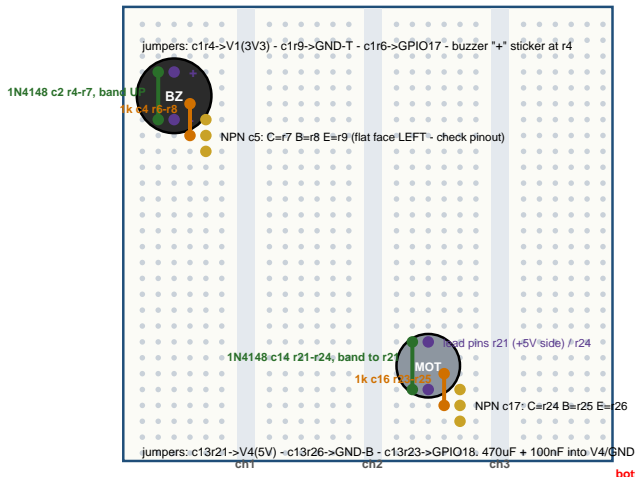
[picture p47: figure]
1N4148 c2 r4-r7, band UP 1k c4 r6-r8; MOT; lead pins r21 (+5V side) / r24; 1N4148 c14 r21-r24, band to r21; NPN c17: C=r24 B=r25 E=r26

WIRE COLOURS: 5V | 3V3 | GND | SCK | WS | SD_A | SD_B | EPD | CTRL | SENTRY-Node lab manual v9 - Protobloc 2C as-built - p. 6

## 9 · E-paper display [header on B2 - display OFF-BOARD]

HAT pin | VCC | GND | DIN | CLK | CS | DC | RST | BUSY
Header row (c1) | r20 | r21 | r22 | r23 | r24 | r25 | r26 | r27
Goes to | B2.V1 | GND-B | GPIO11 | GPIO12 | GPIO10 | GPIO13 | GPIO14 | GPIO15
Anchor rule | The display CANNOT anchor into a breadboard - it has no pins, only a female cable header. Only the 8-pin male strip seats on the board (c1, rows 20-27, one signal per row-net). The display rests on the bench off the BOTTOM edge, screen up, connected by its supplied cable. Never lay it over block 3.
Rule | Wire by the labels on the HAT and the cable heat-shrink, NEVER by wire colour - Waveshare colour order varies by batch.
Check | Demo refresh draws • BUSY toggles during refresh • M1 noise floor unchanged while refreshing

## 10 · Buzzer driver [B1, S1, rows 4-9]

3V3

BUZZER

+
1N4148

band UP

BC337 / 2N2222

1k
GPIO17

GPIO HIGH = on. Load between supply and collector, emitter to GND. Check pinout: BC337 and 2N2222 differ.

Part ID | Black cylinder, two stiff pins, "+" sticker (3 V active buzzer)
Seat | Buzzer pins c3 r4 (+) / c3 r7 • 1N4148 c2 r4-r7, band UP • NPN c5: C r7, B r8, E r9 • 1k c4 r6-r8
Wire | c1 r4 -> B1.V1 (3V3, top-left half - right there) • c1 r9 -> GND-T (black) • c1 r6 -> GPIO17
Check | Beeps on a test pulse • ~0.7 V base-emitter when on • silent and cool when off

## 11 · Motor driver [B1, S3, rows 20-27]

5V

MOTOR | 1N4148 band UP

BC337 / 2N2222

1k
GPIO18

+
470uF

GPIO HIGH = on. Load between supply and collector, emitter to GND. Check pinout: BC337 and 2N2222 differ.

Part ID | Coin / pager disc, red + blue flying leads soldered to male pins first
Seat | Lead pins c15 r21 (5V side) / c15 r24 • 1N4148 c14 r21-r24, band to r21 • NPN c17: C r24, B r25, E r26 • 1k c16 r23-r25
Wire | c13 r21 -> B1.V4 (5V, bottom-right half - right there) • c13 r26 -> GND-B (black) • c13 r23 -> GPIO18 • 470uF + 100nF into V4 / GND-B at the right end, + to V4
Check | Spins on a test pulse • motor OFF: M1 noise floor unchanged from §7

top: GND-T (black) + V1=3V3 (left half)

bottom: V4=5V (right half) + GND-B (black)

NPN c5: C=r7 B=r8 E=r9 (flat face LEFT - check pinout) jumpers: c1r4->V1(3V3) - c1r9->GND-T - c1r6->GPIO17 - buzzer "+" sticker at r4

jumpers: c13r21->V4(5V) - c13r26->GND-B - c13r23->GPIO18. 470uF + 100nF into V4/GND-B at the right end, + to V4.

BLOCK 1. Buzzer net top-left near V1/V2; motor net bottom-right near V3/V4 - the two nets never share a row band.

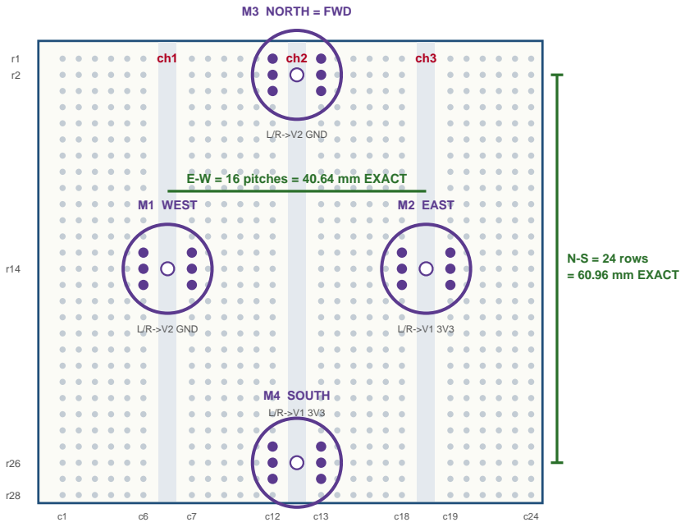
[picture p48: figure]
M1 WEST; L/R->V2 GND; M2 EAST; M3 NORTH = FWD; M4 SOUTH; E-W = 16 pitches = 40.64 mm EXACT; N-S = 24 rows = 60.96 mm EXACT

WIRE COLOURS: 5V | 3V3 | GND | SCK | WS | SD_A | SD_B | EPD | CTRL | SENTRY-Node lab manual v9 - Protobloc 2C as-built - p. 7

## 12 · Full array [B3]

FORWARD = 0 deg (row-1 edge = USB edge)

Centres coincide at (ch2, row 14). Pads: M1 c6/c7 r13-15 - M2 c18/c19 r13-15 - M3 c12/c13 r1-3 - M4 c12/c13 r25-27.
12a | Set B3 rails: V1+V2 = 3V3 (ONE bridge), blacks = GND, V3 = SCK (tape label), V4 = WS (tape label). Do NOT bridge V3-V4.
12b | Seat M2 (c18/c19, r13-15), M3 (c12/c13, r1-3), M4 (c12/c13, r25-27). All four rotated identically, ports up, nothing resting on B3. M1 is in place from §7.
12c | Six jumpers per mic as the M1 pattern in §7, shifted to each mic. L/R: black GND for M1/M3, 3V3 (V1/V2) for M2/M4. SCK lives on the LEFT half (V3), WS on the RIGHT half (V4): M1 crosses right for WS, M2 crosses left for SCK, M3/M4 sit at the split and reach both.
12d | SD runs: GPIO6 -> M1 SD row -> daisy (free holes of the same row) -> M2 SD row. GPIO7 -> M3 SD row -> M4 SD row. Twist each with a spare GND.
12e | Enter the §4 coordinates in firmware - they are unchanged from v7, so if they are already in, touch nothing.
Tap test (mandatory before any beamforming): 4-channel capture running, tap each mic in turn - spike lands on its expected channel (M1 bus A left, M2 bus A right, M3 bus B left, M4 bus B right). Then one sharp clap: all four within ~1 ms. This also validates the shared clock master across the two peripherals.

## 13 · Full smoke test

Run | 4-channel capture + LED + e-paper refresh + commanded buzzer-and-motor alert burst, all at once
Pass | Noise floor unchanged with LED and e-paper active • buzzer/motor mask audio only during the alert • floor returns to baseline after

WIRE COLOURS: 5V | 3V3 | GND | SCK | WS | SD_A | SD_B | EPD | CTRL | SENTRY-Node lab manual v9 - Protobloc 2C as-built - p. 8

## 14 · Parts

From your order | Qty | From York lab stock | Qty
Protobloc 2C / AD-13 board | 1 | Jumpers male-male (incl. short bridge links) | 60+
ESP32-S3 DevKitC-1 N16R8 | 1 (+1 spare) | BC337 or 2N2222 | 3
INMP441 round modules | 4 | 1N4148 | 4
Waveshare 2.13 e-paper HAT V4 + cable | 1 | 1k / 330R resistors | 3 / 2
WS2812 breakout | 1 of 5 | 100nF / 10uF / 100uF / 470uF | 8 / 3 / 2 / 1
Active buzzer 3 V | 1 of 10 | Tact buttons, 3-pin male header strips | 2 / 8
Vibration motor 3-5 V | 1 of 10 | DMM, tape, fine marker | 1 each
USB-C DATA cable | 1 | NOT needed: extra breadboards, clips, backing | 0

## 15 · Risk flags

F1 | INMP441 quantity: cart line showed 3; four are needed. Verify pack size or reorder. STILL OPEN.
F2 | Mic pad-row spacing must be 0.3 in to straddle a channel. Measure one module at census. Gates the array.
F3 | Census disagreement = stop. Counts beat this manual; geometry is reissued from your numbers.
F4 | Exactly TWO bridges exist: B2 V1-V2 and B3 V1-V2. NEVER bridge B3 V3-V4 (SCK | WS - different nets). B1 needs no bridge at all: V1 and V4 are used as independent half-rails.
F5 | WS2812 at 3V3 data: some clones need >3.5 V. Swap modules from the 5-pack before changing anything.
F6 | E-paper: display cannot anchor - off-board only, never over B3. Wire by HAT / cable labels, never colour.
F7 | Port holes up on every mic. Nothing rests on block 3.
F8 | USB current: Mac port or powered hub. Motor pulses peak near 0.4 A.
F9 | USB-C always at the row-1 / top edge - clear of the posts, and it fixes FORWARD for the array.

## 16 · Change-log entries for the Master Brief (§14)

- Rail model corrected from the bench photo: per block, SIX rail nets - continuous BLACK GND lines outermost top and bottom, plus four independently NAMED half-rails V1 (top-left), V2 (top-right), V3 (bottom-left), V4 (bottom-right). V1/V2 are separate nets, not one broken rail.
- Rail assignments rebuilt: only two bridges in the build (B2 and B3, V1-V2 = 3V3). B1 uses V1 (3V3, buzzer) and V4 (5V, motor) as natural half-rails - zero bridges. B3 rides SCK on V3 and WS on V4: the two halves of one physical line carry two different signals, and must never be joined.
- Every part now has a hole-exact seat: (block, column, row) for all pads, resistors, diodes, transistors and jumper landings.
- DevKit seats vertically in block 2 straddling ch2, rows 1-23, USB off the top edge (clear of the posts). FORWARD = the USB edge.
- E-paper display moved OFF-BOARD (it cannot anchor into a breadboard); only its 8-pin header lands, one signal per row-net in B2 c1.
- Mic array relocated to block 3 with IDENTICAL coordinates to v7 (+-0.02032 m, +-0.03048 m): no firmware change. Spatial band limit remains deleted (worst-case aliasing 2813 Hz).

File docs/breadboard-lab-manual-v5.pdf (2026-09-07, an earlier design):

WIRE COLOURS: 5V | 3V3 | GND | SCK | WS | SD_A | SD_B | EPD | CTRL | SENTRY-Node breadboard lab manual v5 - p. 1

# SENTRY-Node - Breadboard Lab Manual v5

v5 -
CORRECTED

The INMP441 breakout is a ROUND module with TWO rows of three pads, so it lies flat and STRADDLES a centre channel. One channel per board means one mic line per board, so a 2-D array needs THREE mic boards, not two. Geometry, slab, rail map and assembly all rebuilt around this. New firmware constraint: spatial processing band-limited to 1.5 kHz (§3.1).

## 1 · The whole unit

DECK B main - 5V side

DECK A main - 3V3 side

DECK E mic - M4 line

DECK D mic - M1 / M2 line

DECK C mic - M3 line

channel = the only mic line on a board

clips

ESP32-S3 DevKitC-1

USB-C | cols 2-23, straddles A/B seam M1 TEST / I2SE-PAPER LED + BTN
CAPS BUZZER | MOTOR

M3

M1 | M2

M4

FORWARD = 0 deg (M3 edge)

### 6 feed jumpers cross THIS seam

273 mm

165 mm
Five boards, clipped LONG edge to LONG edge. Back the slab with stiff card or scrap ally - 5 clipped boards flex.
Stack (top to bottom) | C, D, E (mic) then A, B (main). Five 830-pt boards clipped along LONG edges: 165 x 273 mm.
Why three mic boards | The mic straddles a centre channel, and a board has exactly one channel - so every mic on a board shares the same Y. Two boards can only make a T. Three channel lines give a true cross: M3 / M1+M2 / M4.
Why the baselines are fixed | N-S is channel-to-channel = one board width x2 = 109.22 mm, exact by construction. E-W is 42 column pitches = 106.68 mm, exact by counting. Nothing to measure.
Crossing the E/A seam | Only 6 jumpers: 3V3, GND, SCK, WS, SD_A, SD_B.
Stiffener (recommended) | Five clipped boards flex. Peel the backing and stick the slab to stiff card, thin ply, or scrap aluminium. Flex changes array geometry, which changes bearing.
Vibration tradeoff | Rigid coupling conducts motor buzz into the mics. The motor driver sits on deck B, furthest from the array, and only runs post-detection. If §14 shows the motor-OFF floor changing, unclip the mic deck and rerun on 20 cm jumpers.

WIRE COLOURS: 5V | 3V3 | GND | SCK | WS | SD_A | SD_B | EPD | CTRL | SENTRY-Node breadboard lab manual v5 - p. 2

## 2 · Main deck layout (build order left to right)

DECK A (top) - 3V3 rails

1 | 10 | 20 | 30 | 40 | 50 | 60

DECK B (bottom) - 5V rails

1 | 10 | 20 | 30 | 40 | 50 | 60

seam - inner rails, if present, are both GND

ESP32-S3 DevKitC-1
cols 2-23, straddles seam
USB-C off the LEFT edge

M1 TEST + I2S LANDING
M1 straddles channel 27-29

cols 27-36

E-PAPER HEADER
8 male pins, rows F-J

cols 40-47

WS2812
rows F-J

cols 51-55

BUTTON
straddles channel

cols 58-61

RAIL CAPS
10uF + 100nF x2

cols 27-31

BUZZER DRIVER
rows A-E

cols 35-43

MOTOR DRIVER
rows A-E

cols 47-57

8-wire tether to MIC DECK (male-male, <= 20 cm)

Horizontally to scale: 63 columns = one 830-pt board. Keep cols 24-26 empty as a service gap.
Block | Deck | Cols | Rows | Order
DevKitC-1 | A+B (straddle) | 2-23 | all | 1
Rail caps | B | 27-31 | rails | 1
M1 test seat + I2S landing | A | 27-36 | M1 straddles channel at 27-29 | 2
Button | A | 58-61 | E/F, straddles channel | 3
WS2812 | A | 51-55 | F-J | 4
Buzzer driver | B | 35-43 | A-E | 5
Motor driver | B | 47-57 | A-E | 6
E-paper header | A | 40-47 | F-J | 7
Mic deck (separate) | C+D | see §2 | see §2 | 8

WIRE COLOURS: 5V | 3V3 | GND | SCK | WS | SD_A | SD_B | EPD | CTRL | SENTRY-Node breadboard lab manual v5 - p. 3

## 3 · Mic deck layout

DECK E - M4
channel

DECK D - M1 / M2
channel

DECK C - M3
channel

3V3 GND

SCK
WS

M3

cols 32-34

M1

cols 11-13

M2

cols 53-55

M4

cols 32-34

106.68 mm = 42 column pitches (E-W, exact)

109.22 mm
(N-S)
2 board widths

FWD = 0 deg = M3

Each mic STRADDLES its board centre channel and eats 3 columns. One channel per board = one mic line per board.

## 3.1 · Array coordinates (firmware constants)

Mic | Board | Seat | Pin-1 col | x (m) | y (m) | SD | L/R
M3 North = FWD | C (top) | channel, cols 32-34 | 32 | 0.00000 | +0.05461 | GPIO7 | GND
M1 West | D (middle) | channel, cols 11-13 | 11 | -0.05334 | 0.00000 | GPIO6 | GND
M2 East | D (middle) | channel, cols 53-55 | 53 | +0.05334 | 0.00000 | GPIO6 | 3V3
M4 South | E (bottom) | channel, cols 32-34 | 32 | 0.00000 | -0.05461 | GPIO7 | 3V3
E-W baseline | 106.68 mm = 42 column pitches between pin-1s (M1 col 11, M2 col 53). Module centres land on cols 12 and 54, midpoint col 33 = M3/M4 centre column. Exact.
N-S baseline | 109.22 mm = 2 x board width, channel to channel. Exact by construction - no measurement, no per-build constant.
SPATIAL BAND LIMIT | Aliasing at c/2d: 1570 Hz (N-S), 1608 Hz (E-W), 2247 Hz (diagonals). Band-limit ALL bearing and beamforming to 1.5 kHz. The target fundamental (375-475 Hz) and its first two harmonics sit below this. Detection is per-channel spectral work and is NOT affected - it still uses the full comb.
Max delay | 318 us across the N-S pair - hundreds of samples at 48 kHz, comfortably resolvable.
Landmark | Coordinates reference the module CENTRE = its middle column. Pin-1 offset is identical on all four, so the geometry holds regardless.

## 3.2 · Rail map

THE RULE | Every mic board gets the SAME four rail nets: upper pair = 3V3 / GND, lower pair = SCK / WS. Bridge all three boards at each seam (4 jumpers per seam). SD_A and SD_B are point-to-point - each serves only two mics.
Board | Rail pair | Red strip | Blue strip | Note
C, D, E (mic) | upper | 3V3 | GND | serves VDD, GND and the L/R strap
C, D, E (mic) | lower | SCK | WS | TAPE-LABEL these - blue is NOT ground here
A (main) | north = E/A seam | 3V3 | GND | feed point into the mic deck
A (main) | south = A/B seam | 3V3 | GND | deck A modules; 3V3 decoupling caps
B (main) | north = A/B seam | 3V3 | GND | buzzer supply, just across the seam
B (main) | south = slab bottom | 5V | GND | motor supply; 5V caps. ONLY 5V strip in the build.

## 3.3 · Per-mic jumper list (6 per mic, 24 total)

Pad | Goes to | Tap from | Reach
VDD | 3V3 (upper red) | free holes of its own column, upper half | ~13 mm
GND | GND (upper blue) | same | ~13 mm
SCK | SCK (lower red) | free holes of its own column, lower half | ~13 mm
WS | WS (lower blue) | same | ~13 mm
L/R | GND for M1 and M3, 3V3 for M2 and M4 | cross to the upper pair | ~40 mm
SD | GPIO6 for M1+M2, GPIO7 for M3+M4 | point-to-point: feed to M1 then daisy to M2; feed to M4 then daisy to M3 | up to 160 mm - use 20 cm jumpers

WIRE COLOURS: 5V | 3V3 | GND | SCK | WS | SD_A | SD_B | EPD | CTRL | SENTRY-Node breadboard lab manual v5 - p. 4

## 4 · Master pin map

Signal | GPIO | Colour | Notes
I2S SCK - all 4 mics | 4 | yellow | shared
I2S WS - all 4 mics | 5 | white | shared
I2S SD bus A - M1, M2 | 6 | blue | M1 left slot, M2 right slot
I2S SD bus B - M3, M4 | 7 | green | 2nd I2S peripheral; silent until beamforming
E-paper CS/DIN/CLK/DC/RST/BUSY | 10/11/12/13/14/15 | purple | wire by HAT labels only
WS2812 data | 16 | grey | via 330R
Buzzer base | 17 | grey | via 1k
Motor base | 18 | grey | via 1k
Snooze button | 21 | grey | to GND, internal pull-up
KEEP CLEAR | 0, 3, 19, 20, 26-37, 43-46 | - | strapping / USB / flash / PSRAM / UART
Spares | 1, 2, 8, 9, 39-42, 47 | - | 38 / 48 may drive the onboard RGB (board revision dependent)

## 5 · Mechanical conventions

Header soldering | Mic: two SEPARATE 3-pin strips, one per pad row. Plastic spacer flush to the underside; LONG pins point DOWN into the breadboard; solder the SHORT ends on the labelled top face. Keep solder and flux clear of the centre port hole. Same long-pins-down rule for the other modules.
Mic orientation | Module lies FLAT, pins down, straddling the channel. The acoustic port is the small hole at the centre of the top face - it faces UP and must never be taped, glued, or covered. Rotate all four identically (silkscreen readable from the M3 / forward edge) so wiring and responses stay matched.
Mic is MONO | One transducer, one channel. L/R selects which half of the I2S stereo frame it drives, so two mics share one SD wire. 4 mics = 4 channels; all four feed beamforming, orthogonal pairs are just the bearing readout.
Mic is OMNI | The INMP441 hears all directions equally - at 150 Hz-2 kHz the wavelength is 17-90 cm against a ~1 mm port, so there is no usable directivity in the capsule. Direction comes ONLY from arrival-time differences between separated mics. Facing all four the same way is therefore required, not merely tidy: it keeps the four channel responses matched, which is what the TDOA maths assumes. Rotating one to "cover the front" gains no coverage and adds phase mismatch.
Seating - two-row parts | The mic has TWO rows of three pads, so it must straddle the centre channel exactly like a DIP chip: 3 columns wide, one pad row in the F-J half, the other in the A-E half. Six independent nets, tapped from the free holes of each column. The tact switch straddles for the same reason.
One line per board | A board has exactly one centre channel, so every mic on it shares the same Y. This is why the array needs three mic boards - it is a hard mechanical constraint, not a preference.
Jumper gender | DevKit, tether, mic deck, all modules: male-male throughout (every connection is breadboard-hole to breadboard-hole). E-paper HAT uses its own supplied cable.
Dressing | SCK/WS/SD as one short bundle twisted with a spare GND; keep clear of motor leads. Power stays on rails. Trim excess; no loops.

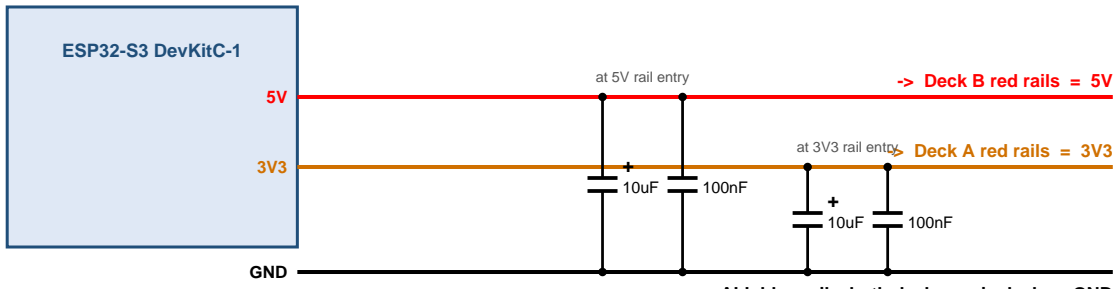
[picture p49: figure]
ESP32-S3 DevKitC-1; GND; -> Deck B red rails = 5V; -> Deck A red rails = 3V3; at 5V rail entry; at 3V3 rail entry

WIRE COLOURS: 5V | 3V3 | GND | SCK | WS | SD_A | SD_B | EPD | CTRL | SENTRY-Node breadboard lab manual v5 - p. 5

## 6 · Power rails [Deck A+B, cols 2-31]

USB-C from Mac = only power source

-> ALL blue rails, both decks + mic deck = GND

Parts | Checks (gate - nothing else is wired until these pass)
10uF electrolytic x2, 100nF ceramic x2, 4x male-male jumpers, 2 board clips | 3V3 rail = 3.25-3.40 V • 5V rail = 4.6-5.15 V • GND continuity deck A rail to deck B rail < 1 ohm • electrolytic stripe = GND side

7 · Mic M1 - first light (= Stage 1b) [Deck A: M1 straddles the channel at cols 27-29; jumper landing

## cols 30-36]

TOP VIEW (as it lies on the board)

PORT
faces UP

SD

VDD

GND

SCK

WS

L/R

Two rows of three pads - identify by silkscreen on YOUR module; variants differ.

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
CENTRE CHANNEL

9 | 10 | 11 | 12 | 13 | 14 | 15 | 16 | 17
column numbers (M1 shown: pin-1 col 11)

SD VDD GND

SCK WS L/R

SEATING - straddles the channel, 3 columns wide One pad row in the F-J half, the other in the A-E half.

Tap each net from the free holes of its own column:
rows G-J for the upper pads, rows A-D for the lower pads.
Seat | M1 straddles deck A centre channel at cols 27-29, port up. Deck A has its own channel - use it for this test; M1 moves to deck D later.
Wiring | VDD->3V3 rail • GND->GND rail • SCK->GPIO4 • WS->GPIO5 • SD->GPIO6 • L/R->GND. Tap each from the free holes of its own column.
Checks | Live 24-bit stream at the configured rate • clap = clean full-scale transient • no stuck or repeated words • steady noise floor
Then | M1 moves to the mic deck at §13. Leave this strip in place - it becomes the tether landing.

WIRE COLOURS: 5V | 3V3 | GND | SCK | WS | SD_A | SD_B | EPD | CTRL | SENTRY-Node breadboard lab manual v5 - p. 6

## 8 · Snooze button [Deck A, cols 58-61, straddling the centre channel]

GPIO21

6 mm tact switch
Use DIAGONAL pins - the two pins on one side are always shorted together internally.
Part | 6 mm 4-pin tact switch (through-hole), legs straddle the channel: two legs in row E, two in row F
Seat | Legs into cols 58 + 60, rows E and F. Straddling the channel is what keeps the two sides isolated.
Wire | GPIO21 -> col 58 (row G) • col 60 (row D) -> GND rail. Use one leg from each DIAGONAL pair.
Optional | 100nF across the same two columns if it double-fires
Check | One clean press/release logged per press; pressed reads LOW

## 9 · WS2812 status LED [Deck A, cols 51-55, rows F-J]

WS2812
module

pins by silkscreen
clone order varies

DIN

VCC

GND

330R
GPIO16

3V3

+
100uF
Parts | WS2812 breakout, 330R, 100uF electrolytic
Seat | Module pins into cols 51-55, row F. Identify DIN / VCC / GND by SILKSCREEN - clone pin order varies.
Wire | GPIO16 -> 330R -> DIN • VCC -> 3V3 rail • GND -> GND rail • 100uF across VCC-GND at the module, + to VCC
Check | Commanded R, then G, then B display as those colours (catches colour order and the 3V3 data threshold at once)
If flicker | Swap to another module from the 5-pack first. Changing the supply is a design change - flag it.

WIRE COLOURS: 5V | 3V3 | GND | SCK | WS | SD_A | SD_B | EPD | CTRL | SENTRY-Node breadboard lab manual v5 - p. 7

## 10 · Buzzer driver [Deck B, cols 35-43, rows A-E]

3V3

BUZZER

+
1N4148

band UP

BC337 / 2N2222

1k
GPIO17

GPIO HIGH = on. Load between supply and collector, emitter to GND. Check pinout: BC337 and 2N2222 differ.

Part ID | Black cylinder, two stiff pins, "+" sticker (3 V active buzzer)
Parts | Buzzer, BC337 or 2N2222, 1k, 1N4148
Seat | Buzzer cols 35/36 • NPN cols 38-40 • 1k cols 41-43
Wire | Buzzer + -> 3V3 rail • buzzer - -> NPN collector • emitter -> GND • GPIO17 -> 1k -> base • 1N4148 across buzzer, band to 3V3
Check | Beeps on a test pulse • ~0.7 V base-emitter when on • silent and cool when off

## 11 · Motor driver [Deck B, cols 47-57, rows A-E]

5V

MOTOR | 1N4148 band UP

BC337 / 2N2222

1k
GPIO18

+
470uF

GPIO HIGH = on. Load between supply and collector, emitter to GND. Check pinout: BC337 and 2N2222 differ.

Part ID | Coin / pager disc, red and blue flying leads (solder to male pins first)
Parts | Motor, BC337 or 2N2222, 1k, 1N4148, 470uF
Seat | Motor leads cols 47/48 • NPN cols 50-52 • 1k cols 53-55 • 470uF cols 56/57 to rails
Wire | Identical to §10 but supply = 5V rail and GPIO18. Motor leads go either way round. Band of the 1N4148 to 5V.
Check | Spins on a test pulse • with the motor OFF, M1 noise floor unchanged from §7 (the motor must not contaminate audio)

WIRE COLOURS: 5V | 3V3 | GND | SCK | WS | SD_A | SD_B | EPD | CTRL | SENTRY-Node breadboard lab manual v5 - p. 8

## 12 · E-paper display [Deck A, cols 40-47, rows F-J]

HAT pin | VCC | GND | DIN | CLK | CS | DC | RST | BUSY
Col | 40 | 41 | 42 | 43 | 44 | 45 | 46 | 47
Goes to | 3V3 | GND | GPIO11 | GPIO12 | GPIO10 | GPIO13 | GPIO14 | GPIO15
Seat | 8-pin male strip into cols 40-47 row F. HAT hangs off-board on its supplied cable, lying flat right of deck A.
Rule | Wire by the labels on the HAT and cable heat-shrink, NEVER by wire colour - Waveshare colour order varies by batch. No extra passives.
Check | Demo refresh draws • BUSY toggles during refresh • M1 noise floor unchanged while refreshing

## 13 · Full mic array [mic decks C, D, E - see §3]

13a | Before anything: measure the pad-row spacing on one module. It must equal the channel width (0.3 in / 7.62 mm) to straddle. If it is 0.2 in, stop and flag - the module needs short link wires instead of a direct seat.
13b | Clip C to D to E, then clip E onto the top long edge of deck A. Back the whole slab with stiff card or ally.
13c | Set the rails per §3.2 on all three mic boards: upper pair 3V3 / GND, lower pair SCK / WS. Tape-label the lower pairs - blue is not ground there. Bridge all three boards at both seams (4 jumpers per seam).
13d | Seat the mics straddling each channel: M3 cols 32-34 on C, M1 cols 11-13 and M2 cols 53-55 on D, M4 cols 32-34 on E. All four rotated identically, ports up and clear.
13e | Wire the 6 jumpers per mic (§3.3). L/R: GND on M1 and M3, 3V3 on M2 and M4.
13f | Six feed jumpers across the E/A seam: 3V3 and GND from deck A north pair; SCK and WS from the §7 I2S strip to deck E lower pair; SD_A to M1 column; SD_B to M4 column. M1 leaves deck A.
13g | Set the firmware coordinates from §3.1 and enable the 1.5 kHz spatial band limit before running any bearing test.
Tap test (mandatory before any beamforming): with 4-channel capture running, tap each mic in turn - the spike must land on its expected channel (M1 bus A left, M2 bus A right, M3 bus B left, M4 bus B right). Then one sharp clap: all four channels show it within ~1 ms.

## 14 · Full smoke test

Run | 4-channel capture + LED activity + e-paper refresh + commanded buzzer-and-motor alert burst, all at once
Pass | Noise floor unchanged with LED and e-paper active • buzzer/motor mask audio only during the alert • floor returns to baseline after

WIRE COLOURS: 5V | 3V3 | GND | SCK | WS | SD_A | SD_B | EPD | CTRL | SENTRY-Node breadboard lab manual v5 - p. 9

## 15 · Parts

From your order | Qty | From York lab stock | Qty
ESP32-S3 DevKitC-1 N16R8 | 1 (+1 spare) | 830-pt breadboards | 4 (2 main + 2 mic deck)
INMP441 modules | 4 | Board clips / spare 830-pt | as needed
Waveshare 2.13 e-paper HAT V4 + cable | 1 | Jumpers male-male | 60+
WS2812 breakout | 1 of 5 | BC337 or 2N2222 | 3
Active buzzer 3 V | 1 of 10 | 1N4148 | 4
Vibration motor 3-5 V | 1 of 10 | 1k / 330R resistors | 3 / 2
USB-C DATA cable | 1 | 100nF / 10uF / 100uF / 470uF | 8 / 3 / 2 / 1
NOT used: slide switch, LiPo gear, power bank | 0 | Tact buttons, 40-pin male header, stiff card or ally backing, DMM, marker | 2 / 2 / 1 / 1 / 1

## 16 · Risk flags

F1 | INMP441 quantity: cart line shows 3. If those are single modules you are one short of the array. Verify pack size / reorder before lab day.
F2 | Measure the pad-row spacing before lab day. 0.3 in straddles the channel directly; 0.2 in does not and needs link wires. This gates the whole array build.
F3 | WS2812 at 3V3 data: usually fine, some clones need >3.5 V. Symptom = flicker / wrong colour. Swap modules first.
F4 | DevKitC-1 barely fits: straddle cols 2-23. Single-board fallback works but is cramped.
F5 | E-paper: wire by HAT/cable labels only - Waveshare colours are not consistent between batches.
F6 | Board dimensions vary slightly by manufacturer: confirm the N-S baseline by measurement, not by trusting 83.82 mm.
F7 | USB current: use the Mac port or a powered hub. Motor pulses peak near 0.4 A.
F8 | Slab rigidity: five clipped boards flex, and flex moves the array geometry. Back the slab, carry it flat, re-run the tap test after transport.
F9 | Port hole faces up on every module - do not rest anything on the mic deck, and keep the backing material off the top face.

## 17 · Change-log entries for the Master Brief (§14)

- CORRECTION: the INMP441 breakout in use is the round 2 x 3-pad variant. It lies flat and straddles a breadboard centre channel; it does not stand in a single row. Earlier plate / riser / vertical-seating notes are void.
- A board has one centre channel, so it can host only one mic line. A 2-D array therefore requires THREE mic boards. Mic deck is now decks C, D, E.
- Array geometry fixed by construction: symmetric cross, E-W 106.68 mm (42 column pitches), N-S 109.22 mm (2 board widths). No per-build measurement, no MIC_SPACING constant - four explicit (x, y) coordinates.
- NEW FIRMWARE CONSTRAINT: spatial aliasing at ~1.57 kHz, so all bearing and beamforming is band-limited to 1.5 kHz. Target fundamental and first two harmonics sit below it. Detection is unaffected.
- Breadboard v3: single five-board slab (C, D, E, A, B), 165 x 273 mm, backing recommended. Slide switch still deleted; build remains USB-powered.
- Confirmed: the mic is mono AND omnidirectional. L/R is the I2S frame slot, not a channel and not a direction; bearing comes solely from inter-mic arrival time.

# MIC DECK MAP - 1:1

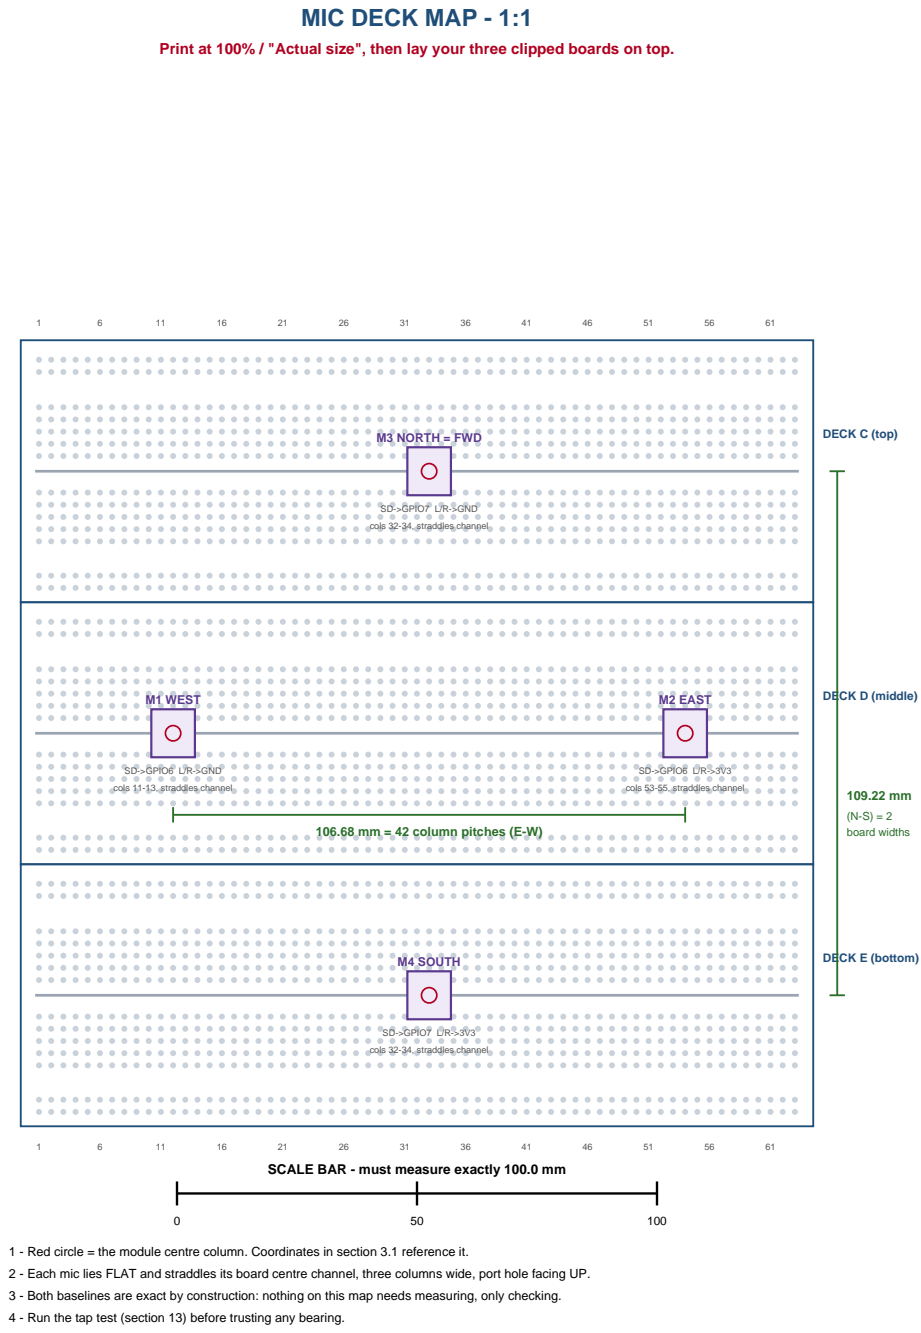
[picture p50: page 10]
DECK E (bottom); DECK D (middle); DECK C (top); M3 NORTH = FWD; M1 WEST; M2 EAST; M4 SOUTH; (N-S) = 2 board widths

Print at 100% / "Actual size", then lay your three clipped boards on top.

SD->GPIO7 L/R->GND
cols 32-34, straddles channel

SD->GPIO6 L/R->GND
cols 11-13, straddles channel

SD->GPIO6 L/R->3V3
cols 53-55, straddles channel

106.68 mm = 42 column pitches (E-W)

SD->GPIO7 L/R->3V3

SCALE BAR - must measure exactly 100.0 mm

1 - Red circle = the module centre column. Coordinates in section 3.1 reference it.
2 - Each mic lies FLAT and straddles its board centre channel, three columns wide, port hole facing UP.
3 - Both baselines are exact by construction: nothing on this map needs measuring, only checking.
4 - Run the tap test (section 13) before trusting any bearing.

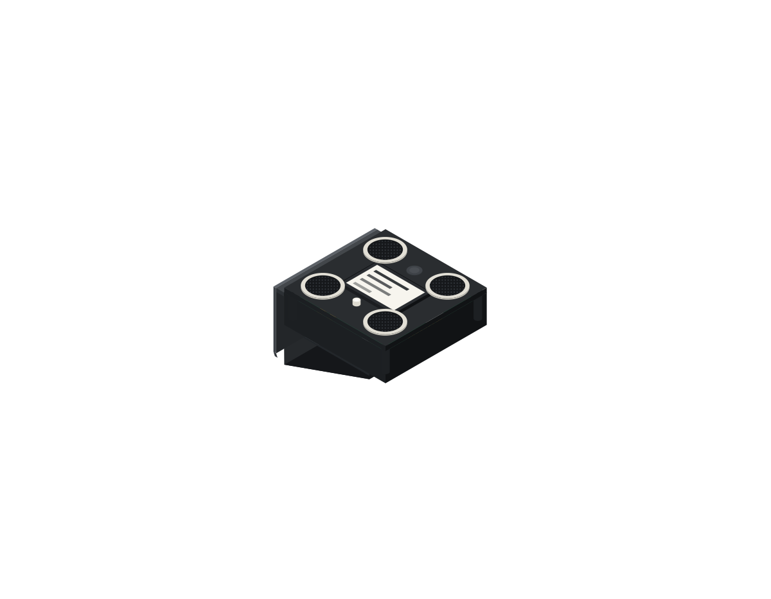
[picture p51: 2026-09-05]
docs/images/assembled-iso.png

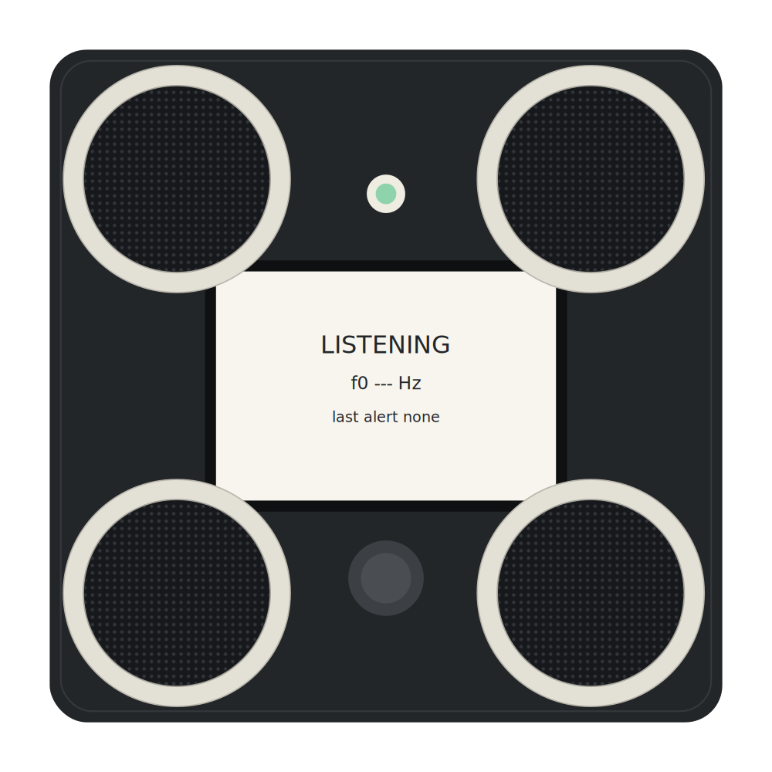
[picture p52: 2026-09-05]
docs/images/assembled-face.png

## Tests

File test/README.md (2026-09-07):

# Test audio

Recordings from the 21 August 2026 field session, 16 kHz mono WAV, straight off the array. Play them from a phone at half a metre to check a fresh build, or feed them to the detector on a laptop.

| File | What it is |
|---|---|
| two_propellers_stable_16k.wav | Two loaded 7 in propellers, steady throttle |
| two_propellers_punch_out_16k.wav | Two propellers, fast throttle punches |
| two_propellers_with_wind_14m_distance_16k.wav | Two propellers at 14 m in changing wind, the day's range limit |
| Wind_recording_16k.wav | Wind only |
| Wind_recording_2_16k.wav | Wind only, second capture |

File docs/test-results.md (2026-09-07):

# Test results

Measured, with date and conditions, in the order it happened. Nothing here is rounded up.

## 6 September 2026: 104 m on a street

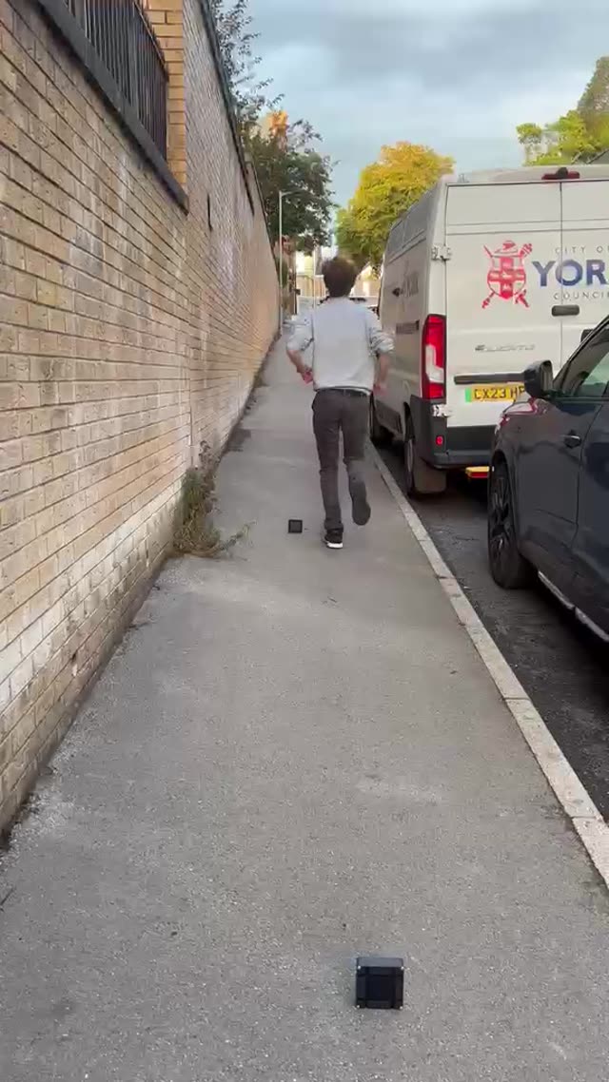
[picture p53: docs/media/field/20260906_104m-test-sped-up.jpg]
The unit in the hand, the rig at the far end of the street


One unit, N-F2CF, held on the pavement of a brick-walled street with traffic passing and people talking nearby. The test rig hovered at the far end of the street. Distance taped and confirmed on the map: **104.2 m, 114 yards**.

| | |
|---|---|
| Tier that fired | 4, no-floor comb |
| Score | W 31.9 against a threshold of 30.5 |
| Rate | f0 600 Hz |
| Wind | light, about 1 m/s |
| False alarms | none, cars and speech included |

<table><tr>
<td width="50%">114 yards on the map</td>
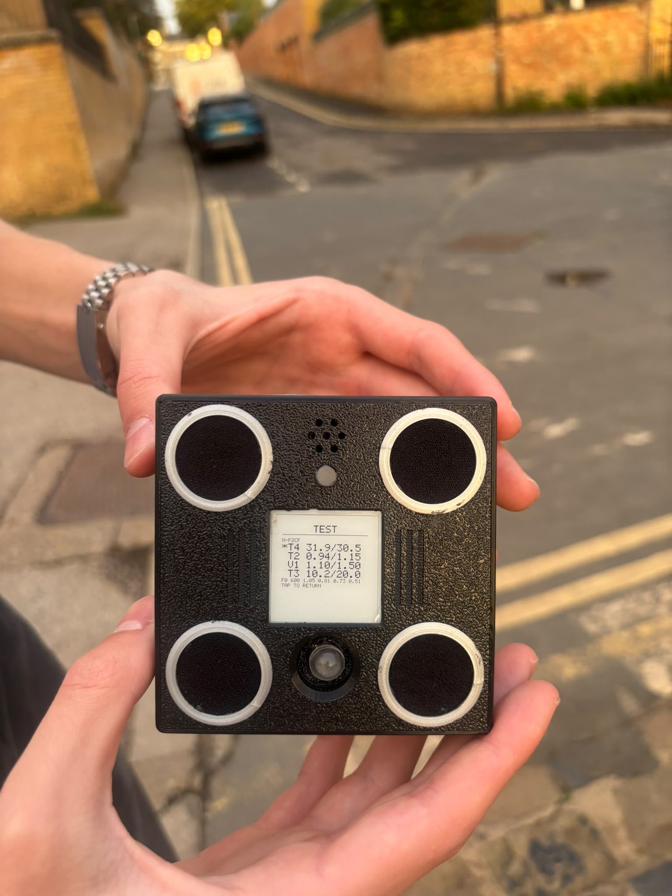
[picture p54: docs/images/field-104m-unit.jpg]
The test screen after the detection, star on tier 4
<td width="50%"></td>
</tr></table>

Videos from the session, in [the gallery](gallery.md#field-test-videos). Since this test the detector has been tuned further, for a lower false-alarm rate and a faster reaction, and those changes are in the current firmware.

## 28 August 2026: first production board

Rev A2, first bring-up. Detector output bit-identical to the reference implementation on the golden test vectors, to the last decimal place. Four tiers running together: worst frame 29.4 ms against the 32 ms budget, 1,938 frames, no overruns, over a seven minute guard. All four microphones matched within ±1 dB after per-channel calibration.

One finding shaped the build guide. With no battery fitted, beeper, motor and radio transmit at the same moment browned out a USB-only supply. The battery is part of the power design.

## 21 August 2026: open ground

Four, then two, loaded 7 in propellers on the rig, open ground, mild changing wind. Detection to about 14 m with the fast tier and the wash tier. Wind, not electronics, set the number. Close steady hovers were caught intermittently and fast throttle punches were mostly missed, both traced to the fast floor absorbing steady sounds. Tiers 2 and 4 came from this day. No false alarms across the whole session.

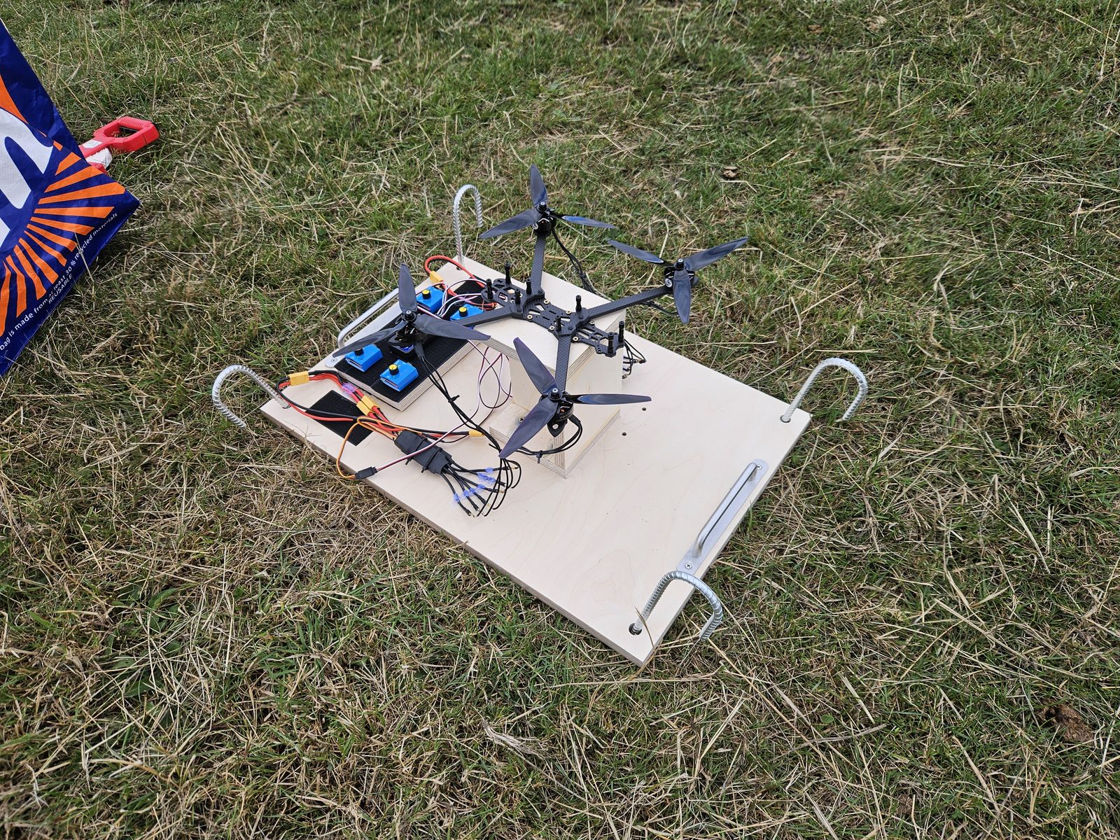
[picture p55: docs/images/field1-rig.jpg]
The rig staked on open ground, unit in the foreground


Loaded props measured +5.9 dB in the 125 to 1000 Hz scoring band at 4 m over site wind. The recordings from this day are in [test/audio](../test/audio/): two propellers steady, two propellers punching out, two propellers in wind at 14 m, and two wind-only captures. All 16 kHz mono WAV, straight off the array.

## 13 August 2026: bench

A single 2807-class motor with a 7 in three-blade propeller, quiet indoor conditions, through the full array. Detection at 25 to 30 m, which was the far wall of the longest room available, not the distance where it failed. First real-rotor locks at f0 = 423 and 471 Hz, inside the 375 to 475 Hz band predicted from the airframe's physics before any rotor had been heard.

## Confusers

Synthetic corpus replayed through the full pipeline: helicopter, propeller aircraft, diesel truck, motorbike, distant traffic, HVAC. No false alarms. In the lab, sustained speech close to the unit and orchestral music through a speaker have triggered the comb tiers. Both are known and both are rare in an outdoor mounting position.

## Field measurements

| Date | Build | Source | Distance | Result | Wind | Environment | Tier |
|---|---|---|---|---|---|---|---|
| 2026-08-13 | DevKit | single loaded rotor | 25 to 30 m | detected | none, indoor | lab | 1 |
| 2026-08-21 | DevKit | 4 then 2 loaded props | 14 m | detected | changing, mild | open ground | 1, 3 |
| 2026-09-06 | rev A2, N-F2CF | four-motor rig, hover | 104.2 m | detected | light, ~1 m/s | street, traffic, speech | 4 |

## Report yours

Open an issue titled `Build report: <rough location, month>` with:

    Build type:        full unit / breadboard
    Firmware version:  from the boot banner
    Mics healthy:      4/4? from the boot report
    Test source:       drone model / rig / speaker
    Distances:         detected at ___ m, not detected at ___ m
    Wind:              calm / light, leaves move / moderate, branches move / strong
    Environment:       open field / urban / indoor
    False alarms:      count over ___ hours, and the cause if known

Photos welcome. No maps of where your units are.

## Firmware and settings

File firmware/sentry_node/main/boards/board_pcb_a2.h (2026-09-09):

/*
 * boards/board_pcb_a2.h - the pin map for the SENTRY-Node PCB, rev A2.
 *
 * Transcribed from the board specification, which lives with the board design
 * rather than in this repository. This header is therefore a copy of numbers
 * that are authoritative somewhere else - the one place in this firmware
 * where a constant cannot be re-derived from anything in the tree. When a
 * board is in front of you, `I` and a multimeter are the authority, not this
 * file, which is the same rule the DevKit header carries.
 *
 * ---------------------------------------------------------------------------
 * GPIO numbering is identical to the validated DevKitC-1 build, so the
 * fourteen proven pins below are byte-for-byte the DevKit's. They are
 * repeated here rather than included from the DevKit header, because the two
 * boards agreeing today is a fact to be checked - the seam test checks it -
 * and not an inheritance to be assumed: the day a later revision moves one
 * pin, an inheritance would move it on the breadboard too and silently
 * invalidate every bench measurement this project owns.
 *
 * What is genuinely new on this board is at the bottom: the battery sense
 * divider, the charger status line, and the LoRa radio.
 * ---------------------------------------------------------------------------
 */
#pragma once

/* ---- mic #1 (INMP441) --------------------------------------------------- */
#define PIN_I2S_BCLK   4    /* mic SCK  - bit clock,  master out */
#define PIN_I2S_WS     5    /* mic WS   - word select, master out */
#define PIN_I2S_SD     6    /* mic SD   - data,        mic out / ESP in */
#define PIN_I2S_SD2    7    /* mics #3/#4 data line, read by I2S1 as a slave
                             * off the same GPIO4/GPIO5 clocks I2S0 drives. */

/* ---- alert outputs and operator controls -------------------------------- */
#define PIN_EPD_CS     10   /* e-paper chip select   (SPI2 / FSPI)          */
#define PIN_EPD_DIN    11   /* e-paper MOSI - shared with the radio          */
#define PIN_EPD_CLK    12   /* e-paper SCLK - shared with the radio          */
#define PIN_EPD_DC     13   /* e-paper data/command, plain GPIO              */
#define PIN_EPD_RST    14   /* e-paper reset, plain GPIO                     */
#define PIN_EPD_BUSY   15   /* e-paper busy, INPUT, polled with a timeout    */
#define PIN_LED_WS2812 16   /* WS2812 data via 330 Ohm; RMT TX, 800 kHz      */
#define PIN_BUZZER     17   /* NPN base via 1 kOhm. HIGH = ON. LOW at boot.  */
#define PIN_MOTOR      18   /* NPN base via 1 kOhm. HIGH = ON. LOW at boot.  */
#define PIN_SNOOZE_BTN 21   /* button to GND, internal pull-up. PRESSED = LOW */

/* ---- what the mic itself must be strapped to ---------------------------- */
#define MIC_LR_STRAP   "GND (LEFT slot)"
#define I2S_BCLK_HZ    (CFG_FS * 32 * 2)

/* ==========================================================================
 * New on the PCB.
 * ========================================================================== */

/* Battery sense. A 100k/100k divider from VBAT into ADC1_CH0, with a 100 nF
 * cap across the lower leg, so the pin sees VBAT/2 - comfortably inside the
 * ADC's range for a 1S cell at 4.2 V. The divider ratio is a board constant
 * and lives here; power_mon.c multiplies by it and never knows the number. */
#define PIN_VBAT_SENSE        1
#define BOARD_VBAT_DIV_NUM    2      /* VBAT = pin_mV * NUM / DEN            */
#define BOARD_VBAT_DIV_DEN    1

/* Charger status. BQ24074-class power path; STAT is open drain with a 100k
 * pull-up, so it reads low while charging and floats high otherwise.
 *
 * That polarity is what the part family does rather than what this board has
 * been measured to do, and a charge glyph that is lit whenever the battery is
 * not charging is the kind of wrong that survives a whole field season. Read
 * the pin plugged and unplugged at bring-up; if it comes back inverted, this
 * one line changes and nothing else does. */
#define PIN_CHG_STAT          2
#define BOARD_CHG_ACTIVE_LOW  1

/* The radio: Ai-Thinker Ra-01H (SX1276) on SPI2, sharing SCK and MOSI with
 * the e-paper and owning MISO alone - the panel is write-only, so nothing
 * else can drive that line. Its own CS, reset and DIO0.
 *
 * PA_BOOST only. The Ra-01H bonds the SX1276's PA_BOOST output and leaves RFO
 * unconnected, so the PA select bit is not a preference on this module, it is
 * the only setting that transmits at all. */
#define PIN_LORA_MISO         8
#define PIN_LORA_CS           9    /* idle HIGH */
#define PIN_LORA_RST          47
#define PIN_LORA_DIO0         48
#define BOARD_LORA_PA_BOOST   1
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

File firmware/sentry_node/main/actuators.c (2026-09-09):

#include "actuators.h"
#include "ui_config.h"

#include "freertos/FreeRTOS.h"
#include "freertos/task.h"

#include "driver/gpio.h"
#include "driver/ledc.h"
#include "esp_rom_gpio.h"
#include "soc/gpio_sig_map.h"

#include "board_pins.h"
#include "led_ws2812.h"

static bool s_booted;
static bool s_buzzer;
static bool s_motor;

/* ---- buzzer drive -------------------------------------------------------
 * DC by default, which is exactly the behaviour every previous capture was
 * taken with. The LEDC timer/channel is created on FIRST PWM USE and never at
 * boot, so the boot path is unchanged. */
#define BUZZ_LEDC_MODE  LEDC_LOW_SPEED_MODE
#define BUZZ_LEDC_TIMER LEDC_TIMER_0
#define BUZZ_LEDC_CHAN  LEDC_CHANNEL_0
#define BUZZ_LEDC_BITS  LEDC_TIMER_10_BIT
#define BUZZ_LEDC_HALF  512     /* 50% of 2^10 - the loudest square wave */

static uint8_t  s_drive = BUZZ_DRIVE_DC;
static uint32_t s_drive_hz = BUZZ_PWM_HZ_DEFAULT;
static bool     s_ledc_ready;

/* Hand the pad back to the GPIO peripheral and park it LOW. Detaching the
 * LEDC output signal matters: ledc_stop() alone leaves the pad wired to the
 * LEDC matrix, so a later gpio_set_level() would be ignored and the buzzer
 * could not be turned off by the DC path. */
static void buzzer_pad_to_gpio(void)
{
    esp_rom_gpio_connect_out_signal(PIN_BUZZER, SIG_GPIO_OUT_IDX, false, false);
    gpio_set_level(PIN_BUZZER, 0);
}

static bool buzzer_ledc_init(uint32_t hz)
{
    ledc_timer_config_t t = {
        .speed_mode = BUZZ_LEDC_MODE,
        .duty_resolution = BUZZ_LEDC_BITS,
        .timer_num = BUZZ_LEDC_TIMER,
        .freq_hz = hz,
        .clk_cfg = LEDC_AUTO_CLK,
    };
    if (ledc_timer_config(&t) != ESP_OK) {
        return false;
    }
    if (!s_ledc_ready) {
        ledc_channel_config_t ch = {
            .gpio_num = PIN_BUZZER,
            .speed_mode = BUZZ_LEDC_MODE,
            .channel = BUZZ_LEDC_CHAN,
            .timer_sel = BUZZ_LEDC_TIMER,
            .duty = 0,
            .hpoint = 0,
            .intr_type = LEDC_INTR_DISABLE,
        };
        if (ledc_channel_config(&ch) != ESP_OK) {
            return false;
        }
        s_ledc_ready = true;
    }
    return true;
}

void actuators_boot_safe(void)
{
    /* Level BEFORE direction: setting the level first means the pad never
     * spends even one instruction as a driven HIGH, which on an NPN base is
     * the difference between silence and a chirp at every reset. */
    gpio_set_level(PIN_BUZZER, 0);
    gpio_set_level(PIN_MOTOR, 0);

    gpio_config_t cfg = {
        .pin_bit_mask = (1ULL << PIN_BUZZER) | (1ULL << PIN_MOTOR),
        .mode = GPIO_MODE_OUTPUT,
        .pull_up_en = GPIO_PULLUP_DISABLE,
        .pull_down_en = GPIO_PULLDOWN_DISABLE,
        .intr_type = GPIO_INTR_DISABLE,
    };
    gpio_config(&cfg);
    gpio_set_level(PIN_BUZZER, 0);
    gpio_set_level(PIN_MOTOR, 0);

    s_buzzer = false;
    s_motor = false;
    s_booted = true;
}

void actuators_buzzer_drive(uint8_t mode, uint32_t hz)
{
    if (!s_booted) {
        actuators_boot_safe();
    }
    const bool was_on = s_buzzer;
    actuators_buzzer(false);            /* silence before re-wiring the pad */

    if (mode == BUZZ_DRIVE_PWM) {
        if (hz < 100u)   { hz = 100u; }
        if (hz > 10000u) { hz = 10000u; }
        if (buzzer_ledc_init(hz)) {
            s_drive = BUZZ_DRIVE_PWM;
            s_drive_hz = hz;
        } else {
            s_drive = BUZZ_DRIVE_DC;    /* refuse silently-broken PWM */
            buzzer_pad_to_gpio();
        }
    } else {
        s_drive = BUZZ_DRIVE_DC;
        if (s_ledc_ready) {
            ledc_stop(BUZZ_LEDC_MODE, BUZZ_LEDC_CHAN, 0);
        }
        buzzer_pad_to_gpio();
    }
    if (was_on) {
        actuators_buzzer(true);
    }
}

bool actuators_buzzer_tone(uint32_t hz, int duty_pct, bool on)
{
    if (!s_booted) {
        actuators_boot_safe();
    }
    if (!on) {
        if (s_ledc_ready) {
            (void)ledc_set_duty(BUZZ_LEDC_MODE, BUZZ_LEDC_CHAN, 0);
            (void)ledc_update_duty(BUZZ_LEDC_MODE, BUZZ_LEDC_CHAN);
        }
        s_buzzer = false;
        return true;
    }
    if (hz < 100u)   { hz = 100u; }
    if (hz > 40000u) { hz = 40000u; }
    if (duty_pct < 0)   { duty_pct = 0; }
    if (duty_pct > 100) { duty_pct = 100; }
    if (!buzzer_ledc_init(hz)) {
        return false;
    }
    /* 10-bit resolution: 1024 counts full scale. */
    const uint32_t duty = (uint32_t)((duty_pct * 1024) / 100);
    if (ledc_set_duty(BUZZ_LEDC_MODE, BUZZ_LEDC_CHAN, duty) != ESP_OK) {
        return false;
    }
    if (ledc_update_duty(BUZZ_LEDC_MODE, BUZZ_LEDC_CHAN) != ESP_OK) {
        return false;
    }
    s_drive = BUZZ_DRIVE_PWM;
    s_drive_hz = hz;
    s_buzzer = (duty_pct > 0);
    return true;
}

uint8_t  actuators_buzzer_drive_mode(void) { return s_drive; }
uint32_t actuators_buzzer_drive_hz(void)   { return s_drive_hz; }

void actuators_buzzer(bool on)
{
    if (!s_booted) {
        actuators_boot_safe();
    }
    s_buzzer = on;
    if (s_drive == BUZZ_DRIVE_PWM && s_ledc_ready) {
        /* 50% duty is the maximum-energy square wave; anything else is a
         * narrower pulse and therefore quieter. */
        ledc_set_duty(BUZZ_LEDC_MODE, BUZZ_LEDC_CHAN, on ? BUZZ_LEDC_HALF : 0);
        ledc_update_duty(BUZZ_LEDC_MODE, BUZZ_LEDC_CHAN);
        return;
    }
    gpio_set_level(PIN_BUZZER, on ? 1 : 0);
}

/* The motor pad can be driven as a plain GPIO or by LEDC, and BOTH of those
 * are used: the burst ramp and the snooze pulse need PWM, everything else
 * does not. Declared up here because actuators_motor() below has to know
 * which peripheral currently owns the pad - writing a level the hardware
 * ignores is exactly the fault this arrangement exists to prevent. */
static bool s_motor_pwm;
static void motor_pwm_duty(int pct);
static void motor_pwm_down(void);
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

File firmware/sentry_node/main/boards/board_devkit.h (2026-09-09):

/*
 * boards/board_devkit.h - the pin map for the ESP32-S3-DevKitC-1 breadboard
 * build. One file, no second opinion.
 *
 * Target: ESP32-S3-DevKitC-1 N16R8 (16 MB quad flash, 8 MB octal PSRAM).
 *
 * If you are wiring the board, do not read the numbers out of a document.
 * Send `I` to the running firmware: it prints the pin map from these macros,
 * so what you read is what is actually flashed. A document can go stale; this
 * cannot.
 *
 * ---------------------------------------------------------------------------
 * Why these pins. Unavailable on this module, and why:
 *
 *   0, 3, 45, 46   strapping - level at reset selects boot mode / VDD_SPI /
 *                  ROM log verbosity
 *   19, 20         native USB D-/D+ - this is the console and the flash link
 *   26-32          SPI flash. QIO (set in sdkconfig.defaults) uses IO2/IO3,
 *                  which were already bonded here, so QIO costs no extra pins
 *   33-37          octal PSRAM. The N16R8 bonds the PSRAM die to these pins
 *                  even with CONFIG_SPIRAM=n; the module wires them
 *                  regardless, so they are not free
 *   38, 48         onboard addressable RGB LED (48 on DevKitC-1 v1.0, 38 on
 *                  v1.1). Avoid both rather than guess the board revision
 *   39-42          MTCK/MTDO/MTDI/MTMS - usable as GPIO, kept free so an
 *                  external JTAG probe stays possible
 *   43, 44         UART0 TX/RX (silkscreened) - kept free as a fallback
 *                  console if USB-Serial-JTAG ever misbehaves
 *
 * GPIO 4, 5, 6, 7 are free, have no alternate function, and sit adjacent on
 * one header - four wires in a row.
 * ---------------------------------------------------------------------------
 */
#pragma once

/* ---- mic #1 (INMP441) --------------------------------------------------- */
#define PIN_I2S_BCLK   4    /* mic SCK  - bit clock,  master out */
#define PIN_I2S_WS     5    /* mic WS   - word select, master out */
#define PIN_I2S_SD     6    /* mic SD   - data,        mic out / ESP in */

/* Mic #2 shares BCLK and WS with #1 and drives the other half of the frame
 * (its L/R tied to 3V3 instead of GND), so a second mic needs no new clock
 * pins at all. GPIO 7 carries a second data line instead - mics #3/#4 on the
 * same peripheral, or a second mic pair that must stay electrically
 * independent. */
#define PIN_I2S_SD2    7    /* quad build: mics #3/#4 data line.
                             * #3 = LEFT slot (L/R->GND), #4 = RIGHT (L/R->3V3).
                             * Read by I2S1 as a slave off the same GPIO4/GPIO5
                             * clocks that I2S0 drives, so all four microphones
                             * share one clock domain. */

/* ---- alert outputs and operator controls -------------------------------
 * None of these is initialised at boot except the two NPN bases below, which
 * must be driven low immediately: their bases hang off these pins through
 * 1 kOhm, so a high-Z pad at reset is an undefined base drive. Everything
 * else initialises lazily on first command.
 *
 * GPIO 10/11/12 are the native FSPICS0 / FSPID / FSPICLK pins, which is why
 * the e-paper is on SPI2 there rather than on arbitrary GPIO. */
#define PIN_EPD_CS     10   /* e-paper chip select   (SPI2 / FSPI)          */
#define PIN_EPD_DIN    11   /* e-paper MOSI                                  */
#define PIN_EPD_CLK    12   /* e-paper SCLK                                  */
#define PIN_EPD_DC     13   /* e-paper data/command, plain GPIO              */
#define PIN_EPD_RST    14   /* e-paper reset, plain GPIO                     */
#define PIN_EPD_BUSY   15   /* e-paper busy, INPUT, polled with a timeout    */
#define PIN_LED_WS2812 16   /* WS2812 data via 330 Ohm; RMT TX, 800 kHz      */
#define PIN_BUZZER     17   /* NPN base via 1 kOhm. HIGH = ON. LOW at boot.  */
#define PIN_MOTOR      18   /* NPN base via 1 kOhm. HIGH = ON. LOW at boot.  */
#define PIN_SNOOZE_BTN 21   /* button to GND, internal pull-up. PRESSED = LOW */

/* ---- what the mic itself must be strapped to ---------------------------- */
/*   VDD -> 3V3      (INMP441 is 1.8-3.3 V; the usual breakout has a reg)
 *   GND -> GND
 *   L/R -> GND      => the mic drives the LEFT slot, data valid while WS low,
 *                      which is why the firmware selects I2S_STD_SLOT_LEFT.
 *                      Tying L/R to 3V3 instead moves it to the RIGHT slot and
 *                      the firmware reads silence. */
#define MIC_LR_STRAP   "GND (LEFT slot)"

/* BCLK = fs * bits_per_slot * slots = 16000 * 32 * 2 = 1.024 MHz.
 * Std (Philips) mode always clocks two slots even when only one is stored. */
#define I2S_BCLK_HZ    (CFG_FS * 32 * 2)
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

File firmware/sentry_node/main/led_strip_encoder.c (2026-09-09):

/*
 * SPDX-FileCopyrightText: 2021-2022 Espressif Systems (Shanghai) CO LTD
 *
 * SPDX-License-Identifier: Apache-2.0
 */

#include "esp_check.h"
#include "led_strip_encoder.h"
#include "ui_config.h"

/* ---- the bit timings come from ui_config.h ------------------------------
 *
 * They are not literals here, because a literal in an encoder says nothing
 * about which part it is right for and cannot be changed without editing the
 * encoder. The fitted part's windows are T0H 220..380, T0L 750..1600,
 * T1H 750..1600, T1L 220..420 ns, and the classic WS2812B numbers many
 * drivers still carry (T0H 400 ns) are outside the first of those. Integer
 * arithmetic, not floating point, so what is programmed is
 * exactly what the assert below checks. */
#define LED_NS_TICKS(ns, res) ((uint32_t)(((uint64_t)(ns) * (res)) / 1000000000ULL))

/* At 10 MHz a tick is 100 ns and every constant above is a whole number of
 * them. A resolution or a constant that stopped dividing exactly would be
 * silently rounded into or out of the part's window, so it fails the build
 * instead. */
_Static_assert(LED_T0H_NS % 100 == 0 && LED_T0L_NS % 100 == 0 &&
               LED_T1H_NS % 100 == 0 && LED_T1L_NS % 100 == 0,
               "a WS2812B-V6 bit time is not a whole number of 100 ns ticks");

static const char *TAG = "led_encoder";

typedef struct {
    rmt_encoder_t base;
    rmt_encoder_t *bytes_encoder;
    rmt_encoder_t *copy_encoder;
    int state;
    rmt_symbol_word_t reset_code;
} rmt_led_strip_encoder_t;

RMT_ENCODER_FUNC_ATTR
static size_t rmt_encode_led_strip(rmt_encoder_t *encoder, rmt_channel_handle_t channel, const void *primary_data, size_t data_size, rmt_encode_state_t *ret_state)
{
    rmt_led_strip_encoder_t *led_encoder = __containerof(encoder, rmt_led_strip_encoder_t, base);
    rmt_encoder_handle_t bytes_encoder = led_encoder->bytes_encoder;
    rmt_encoder_handle_t copy_encoder = led_encoder->copy_encoder;
    rmt_encode_state_t session_state = RMT_ENCODING_RESET;
    rmt_encode_state_t state = RMT_ENCODING_RESET;
    size_t encoded_symbols = 0;
    switch (led_encoder->state) {
    case 0: // send RGB data
        encoded_symbols += bytes_encoder->encode(bytes_encoder, channel, primary_data, data_size, &session_state);
        if (session_state & RMT_ENCODING_COMPLETE) {
            led_encoder->state = 1; // switch to next state when current encoding session finished
        }
        if (session_state & RMT_ENCODING_MEM_FULL) {
            state |= RMT_ENCODING_MEM_FULL;
            goto out; // yield if there's no free space for encoding artifacts
        }
    // fall-through
    case 1: // send reset code
        encoded_symbols += copy_encoder->encode(copy_encoder, channel, &led_encoder->reset_code,
                                                sizeof(led_encoder->reset_code), &session_state);
        if (session_state & RMT_ENCODING_COMPLETE) {
            led_encoder->state = RMT_ENCODING_RESET; // back to the initial encoding session
            state |= RMT_ENCODING_COMPLETE;
        }
        if (session_state & RMT_ENCODING_MEM_FULL) {
            state |= RMT_ENCODING_MEM_FULL;
            goto out; // yield if there's no free space for encoding artifacts
        }
    }
out:
    *ret_state = state;
    return encoded_symbols;
}

static esp_err_t rmt_del_led_strip_encoder(rmt_encoder_t *encoder)
{
    rmt_led_strip_encoder_t *led_encoder = __containerof(encoder, rmt_led_strip_encoder_t, base);
    rmt_del_encoder(led_encoder->bytes_encoder);
    rmt_del_encoder(led_encoder->copy_encoder);
    free(led_encoder);
    return ESP_OK;
}

RMT_ENCODER_FUNC_ATTR
static esp_err_t rmt_led_strip_encoder_reset(rmt_encoder_t *encoder)
{
    rmt_led_strip_encoder_t *led_encoder = __containerof(encoder, rmt_led_strip_encoder_t, base);
    rmt_encoder_reset(led_encoder->bytes_encoder);
    rmt_encoder_reset(led_encoder->copy_encoder);
    led_encoder->state = RMT_ENCODING_RESET;
    return ESP_OK;
}

esp_err_t rmt_new_led_strip_encoder(const led_strip_encoder_config_t *config, rmt_encoder_handle_t *ret_encoder)
{
    esp_err_t ret = ESP_OK;
    rmt_led_strip_encoder_t *led_encoder = NULL;
    ESP_GOTO_ON_FALSE(config && ret_encoder, ESP_ERR_INVALID_ARG, err, TAG, "invalid argument");
    led_encoder = rmt_alloc_encoder_mem(sizeof(rmt_led_strip_encoder_t));
    ESP_GOTO_ON_FALSE(led_encoder, ESP_ERR_NO_MEM, err, TAG, "no mem for led strip encoder");
    led_encoder->base.encode = rmt_encode_led_strip;
    led_encoder->base.del = rmt_del_led_strip_encoder;
    led_encoder->base.reset = rmt_led_strip_encoder_reset;
    // different led strip might have its own timing requirements, following parameter is for WS2812
    rmt_bytes_encoder_config_t bytes_encoder_config = {
        .bit0 = {
            .level0 = 1,
            .duration0 = LED_NS_TICKS(LED_T0H_NS, config->resolution),
            .level1 = 0,
            .duration1 = LED_NS_TICKS(LED_T0L_NS, config->resolution),
        },
        .bit1 = {
            .level0 = 1,
            .duration0 = LED_NS_TICKS(LED_T1H_NS, config->resolution),
            .level1 = 0,
            .duration1 = LED_NS_TICKS(LED_T1L_NS, config->resolution),
        },
        .flags.msb_first = 1 // WS2812 transfer bit order: G7...G0R7...R0B7...B0
    };
    ESP_GOTO_ON_ERROR(rmt_new_bytes_encoder(&bytes_encoder_config, &led_encoder->bytes_encoder), err, TAG, "create bytes encoder failed");
    rmt_copy_encoder_config_t copy_encoder_config = {};
    ESP_GOTO_ON_ERROR(rmt_new_copy_encoder(&copy_encoder_config, &led_encoder->copy_encoder), err, TAG, "create copy encoder failed");

    /* The reset is emitted as ONE symbol of two low halves, so each half is
     * reset_us/2. An RMT duration field is 15 bits, so a half is capped at
     * 32767 ticks = 3.27 ms at 10 MHz - far above anything a WS2812 wants,
     * but clamped rather than silently truncated. */
    uint32_t reset_us = config->reset_us ? config->reset_us : LED_RESET_US;
    uint32_t reset_ticks = config->resolution / 1000000 * reset_us / 2;
    if (reset_ticks > 32767u) {
        reset_ticks = 32767u;
    }
    led_encoder->reset_code = (rmt_symbol_word_t) {
        .level0 = 0,
        .duration0 = reset_ticks,
        .level1 = 0,
        .duration1 = reset_ticks,
    };
    *ret_encoder = &led_encoder->base;
    return ESP_OK;
err:
    if (led_encoder) {
        if (led_encoder->bytes_encoder) {
            rmt_del_encoder(led_encoder->bytes_encoder);
        }
        if (led_encoder->copy_encoder) {
            rmt_del_encoder(led_encoder->copy_encoder);
        }
        free(led_encoder);
    }
    return ret;
}

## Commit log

2026-09-05 VolAnti: hardware, enclosure, documentation and parts list
    [bom.csv, pick-and-place.csv]
2026-09-07 new test
    [VolAnti_Base.step, VolAnti_Base.stl, VolAnti_GrilleRing.step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]
2026-09-09 firmware: ESP32-S3 source
    [partitions.csv]
2026-09-13 src, data: the reference detector, config and golden vectors the build needs
    The firmware build generates its headers from src/ and data/, which were not
    in the repository. This adds them, with environment.yml for the Python side.
    The build can also use any Python with numpy through SENTRY_PYTHON.
    [golden_high_alert_pos_trace.csv, golden_marginal_neg_trace.csv, golden_marginal_pos_trace.csv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]
2026-09-13 docs: fix the firmware path and build steps, add a note on the project
    The flashing guide and firmware README pointed at firmware/volanti, which does
    not exist, and said the PCB was the default target. Both now describe
    firmware/sentry_node and its two board targets. Also fixes a board selection
    comment, four broken links in the website source and the LED description, and
    adds a short note to the README and the disclaimer.
